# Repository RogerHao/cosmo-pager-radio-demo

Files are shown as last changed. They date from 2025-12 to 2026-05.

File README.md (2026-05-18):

# CosmoRadio

可穿梭于平行宇宙的 Radio 接收器

## 项目简介

桌面交互设备，安卓平板 + 3D 打印外壳 + ESP32 USB HID 控制器。造型参考 iMac G3 斜面站立式设计，用户通过旋钮调频、NFC 刷卡切换内容，仿佛在平行宇宙间搜索信号。

**当前版本：V4**（2026.04 — 2026.05）— 技术方案验证 + 单套原型制作

> 2026-04-29 与 Arthur 达成重启协议：第四期缩小为技术方案验证和单套原型制作，合同价 ¥5,000，目标 2026-05-20 左右交付。原 4 套整机 + 8 套电子套件交付范围已取消。

## 产品形态

- **外观风格**: iMac G3 斜面站立式，模块化三件式（主体 + 顶部 + 背板）
- **显示设计**: 三圆形遮罩（矩形屏幕通过开孔分割为三个圆形显示区）
- **输入方式**: 2 × EC11 旋钮 + Kailh 机械轴按钮 (6.25U 卫星轴) + NFC 刷卡
- **状态指示**: WS2812 RGB LED

## 硬件组成（V4）

| 组件 | 规格 | 用途 |
|---|---|---|
| 安卓平板 | 客户自购 (Samsung Galaxy Tab A9 8.7") | 主机，运行 Web 应用 |
| ESP32-S3 DevKitC N16R8 | 36+ GPIO / USB OTG / 16MB Flash / 8MB PSRAM | HID 控制器 |
| 定制 PCB 载板 | **100×100mm 双面** (JLCPCB 免费打样)，**两条 1×22 单排母** + 5 路 XH2.54 + 4× 10kΩ/10nF 去抖 | 消灭飞线，XH2.54 即插即用 |
| EC11 旋钮 × 2 | 15mm 半轴柄旋转编码器 | 频率调节 / 模式切换 |
| Kailh BOX 轴 + 6.25U 卫星轴 | 机械键盘蝴蝶结构，3.6mm 行程 | Action Button |
| RC522 mini NFC 模块 × 1 | 13.56MHz SPI，读 NTAG215 NDEF | NFC 刷卡交互（最终 1 个，2026-05-06 确认） |
| **OTG dongle (YK16-09E V1) 内置子板** | 拆 USB-A 母座，4 飞线接 J5 → DevKitC 排针 GPIO19/20 + 5V/GND | 平板 Data Host + Power Sink 同时工作 |
| 板载 RGB LED | DevKitC GPIO48 WS2812B | 状态指示（不外接 LED）|

## 连接方案

| 方案 | 固件位置 | 状态 |
|---|---|---|
| USB HID | 项目根目录 | **当前使用** — TinyUSB，即插即用 |
| BLE HID | (已删除，见 git 历史) | V1-V2 遗留，已停用 |

## 交互设计

输入设备通过 ESP32 USB HID 协议作为标准键盘连接到安卓平板，事件以模拟按键传递：

| 输入 | 映射 | 功能 |
|---|---|---|
| 顶部 Action 按钮 | Enter 键 | 确认选择 |
| EC11 左 旋转 | 上/下方向键 | 调节频率 |
| EC11 左 按下 | F1（占位，平板可重映射） | 扩展功能位 |
| EC11 右 旋转 | 左/右方向键 | 切换模式 |
| EC11 右 按下 | F2（占位，平板可重映射） | 扩展功能位 |
| NFC 卡（写了 NDEF Text） | `<payload>\n` | **主路径**：固件读卡上写入的字符串，原样键入 + Enter（无前缀） |
| NFC 卡（空白 / 非 NDEF） | `NFC:<UID>\n` | 兜底：识别失败时键入 UID 方便诊断 |

### NFC 协议设计

为了让产品身份与 NFC 卡 UID 解耦（UID 不可控且需要逐张录入），固件读取卡上的 NDEF Text Record 内容作为产品 ID。流程：

1. 出厂前用任一手机 NFC 工具 app 把每张卡写入特定字符串（如 `R01`、`track-42`）
2. 用户放卡 → 固件读 NDEF → HID 键入 `R01\n`
3. 平板侧 Android 应用结合页面状态/输入长度判断当前是 NFC payload 还是普通 HID 键入；`NFC:` 前缀仅出现在 UID 兜底路径，方便区分

### LED 状态指示（DevKitC 板载 GPIO48 RGB LED）

| 事件 | LED 颜色 |
|---|---|
| 按钮按下 | 红色 |
| 按钮释放 | 熄灭 |
| NFC 识别中（键入期间） | 蓝色 |
| 启动完成 | 绿色闪烁 |

## 项目结构

```
cosmo-radio/                            # 项目根 = ESP-IDF USB HID 固件
├── main/
│   ├── tusb_hid_example_main.c         # 入口：USB HID + ASCII→HID 编码
│   ├── input_handler.c/h               # GPIO 中断输入（按钮 + 双 EC11）
│   ├── nfc_handler.c/h                 # RC522 SPI 扫描 + NDEF Text 解析
│   └── led_indicator.c/h               # 板载 WS2812 RGB（GPIO48）
├── sdkconfig.defaults
├── CMakeLists.txt
├── pcb/                                # KiCad 工程 + JLCPCB 上板资料（待开始）
├── docs/
│   ├── assets/                         # 元器件引脚图、原型照片
│   ├── firmware/                       # 固件实现文档
│   ├── hardware/                       # 硬件模块设计方案（NFC、USB...）
│   ├── legacy/                         # 弃用内容
│   └── project/ → codex                # BOM、PCB Spec、项目主文档
└── test/
    └── hid-test.html
```

## 相关项目

- [cosmo-pager-web-nextjs-vercel](https://github.com/RogerHao/cosmo-pager-web-nextjs-vercel) — Web 应用前端（客户软件团队开发）

## 版本历史

| 版本 | 时间 | 主控 | 连接 | 主要变化 |
|---|---|---|---|---|
| V1 | 2025 Q3-Q4 | Adafruit HUZZAH32 | — | 硬件预研 |
| V2 | 2025.12-2026.01 | XIAO ESP32S3 | BLE HID | 首批组装，硅谷交付 |
| V3 | 2026.01-2026.02 | ESP32-S3 SuperMini | USB HID | BLE→USB 切换，12 套交付 |
| **V4** | **2026.04-2026.05** | **ESP32-S3 DevKitC N16R8** | **USB HID** | **模块化 PCB + NFC + 机械按钮，单套原型验证** |

## V4 进度

**2026-05-07 整体技术方案验证完成 ✅**——电气、固件、NFC 协议端到端跑通。后续是 PCB 板设计 + 结构件设计。

电气与固件：
- [x] 原 12 套 BOM 定稿 + 报价（单套 ¥79，已取消）
- [x] 2026-04-29 与 Arthur 重启 V4：技术方案验证 + 单套原型，合同价 ¥5,000
- [x] USB-C 充电方案：被动 SS34 注入实测失败 → 改为内置一分二 OTG 线材小板（已采购验证）
- [x] NFC 数量确认：1 个 RC522 mini（2026-05-06）
- [x] 万能板飞线原型焊接 + GPIO 验证（2026-05-06，[图片](docs/assets/v4-handmade-prototype-2026-05-06.jpg)）
- [x] 固件 V4 GPIO 迁移（SuperMini → DevKitC N16R8）
- [x] NFC 驱动开发（RC522 SPI + NDEF Text Record 解析）
- [x] 旋钮 + NFC HID 协议定稿（`#<payload>\n` + UID 兜底）
- [x] 端到端验证：iPhone 写卡 → ESP32 读 NDEF → HID 键入 `#112358\n`（2026-05-07）

待办（V4 收尾）：
- [ ] PCB 载板设计（KiCad → JLCPCB），把万能板飞线版固化为正式板
- [ ] Arthur 寄新 Tab A9（原 Pad 已损坏）→ HID + 充电链路回归
- [ ] 按钮机构验证（6.25U 卫星轴空格键 + 3D 打印键帽）
- [ ] 外壳 3D 模型适配（Arthur Fusion 360）+ 打印装配
- [ ] 单套整机原型组装 + 整机测试
- [ ] 交付技术验证报告 + 单套原型

## 构建与烧录

```bash
get_idf                                    # 激活 ESP-IDF 环境
idf.py set-target esp32s3                  # 设置目标芯片（首次）
idf.py build                               # 构建
idf.py -p /dev/cu.usbmodem* flash monitor  # 烧录并监控
```

## GPIO 引脚分配（V4 终版）

> N16R8 = 8MB octal PSRAM，**GPIO 26-37 全段被内部 octal SPI flash + PSRAM 占用，不可使用**。完整表和"PCB 位置"列见 [CLAUDE.md](CLAUDE.md) "GPIO Pin Assignments"。

| 功能 | GPIO | 连接器 (PCB 位置) |
|---|---|---|
| EC11-L (用户左旋钮) A/B/SW | **42 / 41 / 40** | J1 (PCB 左侧中段, 5P) |
| EC11-R (用户右旋钮) A/B/SW | **17 / 18 / 8** | J2 (PCB 右侧中段, 5P) |
| Action Button | 1 | J3 (PCB 左侧靠前, 2P) |
| RC522 NFC RST/IRQ/MISO/MOSI/SCK/CS | 4 / 5 / 6 / 7 / 15 / 16 | J4 (PCB 右侧, 8P, SPI2 via GPIO Matrix) |
| OTG USB D-/D+ | 19 / 20 | J5 (PCB 左侧靠后, 4P) → dongle USB |
| 板载 RGB LED | 48 | DevKitC 板载，无外接 LED |

> EC11 A/B 信号 PCB 上各加 10kΩ 上拉 + 10nF 对地 RC 去抖。
> V3 引脚分配（SuperMini）见 git 历史。

## 文档索引

- [V4 待办事项](TODO.md)
- [V4 BOM 及报价分析](docs/project/CosmoRadio-V4-BOM及报价分析.md)
- [V4 PCB 载板规格](docs/project/CosmoRadio-V4-PCB-Spec.md)
- [项目主文档](docs/project/cosmoradio-yangweile-customized-hardware.md)
- [USB 接口方案](docs/hardware/usb.md)
- [NFC 模块方案](docs/hardware/nfc.md)
- [OTG 一分二适配器（内置子板）](docs/hardware/otg-adapter.md)

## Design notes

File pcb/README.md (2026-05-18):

# CosmoRadio V4 PCB

CosmoRadio V4 的 PCB 目标是做一块 ESP32-S3 DevKitC N16R8 载板，用于技术方案验证和单套原型制作。

当前阶段不追求量产最优，而是追求：

- 可快速打样
- 可手工装配
- 可稳定验证 USB HID、外部充电、旋钮、按钮、NFC
- 出问题时容易测量和返修

## 当前范围

| 项目 | 结论 |
|---|---|
| 合作状态 | 2026-04-29 与 Arthur 重启 V4 |
| 当前交付 | 技术方案验证 + 单套原型制作 |
| 合同价 | ¥5,000 |
| 目标时间 | 2026-05-20 左右 |
| 核心风险 | PCB 设计与验证 |
| 非当前目标 | 原 4 套整机 + 8 套电子件批量交付 |

## 2026-05-07 整体方案验证完成 ✅

| 项目 | 状态 |
|---|---|
| NFC 数量 | ✅ 确认 **1 个** RC522 mini |
| 一分二 OTG + 充电线材 | ✅ 已采购多种型号，测试出一种比较理想，作为内置子板基准 |
| 手工万能板原型 | ✅ 已焊出（[图片](../docs/assets/v4-handmade-prototype-2026-05-06.jpg)）：ESP32-S3 DevKitC + 拆解后的一分二小板 + 4 路 XH2.54 连接器 |
| 测试机 | ⚠️ 原 R4 Tab A9 已损坏，临时用安卓手机替代验证；新 Tab A9 到货后需回归 |
| 连接器布局 | 左上 J4 NFC 8P / 右上 J3 Action Button 2P / 左中 J1 EC11 左 5P / 右中 J2 EC11 右 5P |
| GPIO 分配 | ✅ V4 终版定稿（2026-05-06），详见 [CLAUDE.md](../CLAUDE.md) |
| 外接 LED | ❌ 不接（用 DevKitC 板载 GPIO48 RGB LED 做调试） |
| EC11 接线 | 3 IO + 共地（C 与 SW2 都接 GND，无需 VCC，靠 ESP32 内部上拉） |
| 固件 V4 GPIO 迁移 | ✅ 完成（2026-05-06）；V3 SuperMini pinout 完全弃用 |
| RC522 NFC 驱动 | ✅ 1MHz SPI，NDEF Text Record 解析跑通（2026-05-07） |
| HID 协议 | ✅ `#<payload>\n` 主路径 + `NFC:<UID>\n` 兜底（2026-05-07） |
| 端到端验证 | ✅ iPhone 写卡 "112358" → ESP32 读 NDEF → HID 键入 `#112358\n`（2026-05-07） |

**剩余工作集中在 PCB 设计 + 结构件**——所有方案级未知都已收敛。

## 下一阶段：PCB 落版（Plan v2，2026-05-18 锁定）

详细方案见 `~/.claude/plans/iridescent-snuggling-planet.md`。要点：

- 把万能板飞线版 1:1 复制到 KiCad（连接器位置、网络名都已经在飞线上验证过）
- ESP32-S3 DevKitC N16R8 用**两条 1×22 单排母**（不是 2×22 双排，单排好焊好对齐），间距 22.86mm
- **5 路 XH2.54 连接器**（J1 EC11-L / J2 EC11-R / J3 BTN / J4 NFC / J5 OTG USB 数据）
- OTG dongle (YK16-09E V1) 拆 USB-A 母座后 4 飞线焊到 J5 公头线
- **EC11 A/B 信号外加 10kΩ + 10nF RC 去抖**（4 R + 4 C，全 0805 贴片）—— 解决飞线版"一格不准"
- NFC SPI 时钟可尝试拉回 5MHz（铜箔走线 + 模块自带去耦应该够）
- 板尺寸 **100×100mm 双面板**（JLC 免费打样上限），无 USB-C 母座、无 SS34、无外接 LED

## 板子定位

这不是完整 ESP32 主控板，而是 **ESP32-S3 DevKitC N16R8 carrier board**。

ESP32-S3 DevKitC 通过 2.54mm 排母插在 PCB 上，PCB 只负责：

- 固定主控与外设线束
- 消灭 V3 的万能板和飞线
- 将旋钮、按钮、LED、NFC、USB-C 接口标准化
- 提供必要的上拉、电阻、二极管、去耦
- 支持单套原型的调试和返修

```mermaid
flowchart LR
    tablet[Android 平板] <-- USB HID --> pcb[CosmoRadio V4 PCB]
    charger[USB-C 充电器] --> pcb
    pcb --> devkit[ESP32-S3 DevKitC N16R8]
    pcb --> enc1[EC11 左旋钮]
    pcb --> enc2[EC11 右旋钮]
    pcb --> top[顶部按钮 / LED]
    pcb --> nfc[RC522 NFC 模块]
```

## 已确认事实

### 主控

- 使用 ESP32-S3 DevKitC N16R8，不再使用 V3 的 ESP32-S3 SuperMini。
- DevKitC 插在载板上，不直接焊死。
- ESP32-S3 原生 USB OTG 固定使用 GPIO19 / GPIO20。
- 当前固件仍是 V3/SuperMini pinout，后续必须迁移到 V4 pinout。

### 输入与输出

- 两个 EC11 旋钮，每个旋钮有 A / B / SW。
- Action Button 使用 Kailh BOX 轴 + 6.25U 卫星轴，本质是单路低电平按钮。
- LED 使用 WS2812B，数据线串 330R。
- NFC 使用 RC522 mini 模块，通过 SPI 连接，不把 MFRC522 芯片集成到主板。

### USB 与供电

- 平板是 Samsung Galaxy Tab A9 8.7"。
- 平板侧需要同时承担 USB Host 和充电需求。
- HID 必须走有线 USB；BLE HID 之前已经测试过，不稳定，排除出当前主路径。
- V3 已经通过 Type-C 一分二 OTG 线材验证：Tab A9/Android 手机可以同时接收 ESP32 USB HID 输入并充电。
- 当前问题不是“原理是否成立”，而是 V3 的一分二线材太长、外露、形态差。
- V4 目标是尽可能把一分二线材里的 OTG + 充电能力集成到 PCB/内部结构中，减少外露线材。
- 市面上容易买到的是 OTG + 充电转接线/小扩展坞，不是适合直接嵌入主 PCB 的裸模块。

```mermaid
flowchart LR
    tablet[Tab A9] <-- USB Host 数据 --> sub[内置一分二 OTG + 充电子系统]
    charger[USB-C 充电器] --> sub
    sub <-- USB HID --> esp[ESP32-S3 DevKitC]
    esp --> io[旋钮 / 按钮 / LED / NFC]
```

当前 USB/充电路径按三档处理：

| 档位 | 方案 | 当前定位 |
|---|---|---|
| P0 | 外购一分二 OTG + 充电线材整件 | V3 已验证成立；继续作为功能基准 |
| P1 | 拆解一分二线材，取内部 PCB，短线/板内固定 | 当前最现实的 V4 原型方向 |
| P2 | 自研 LDR6028/LDR6023C OTG + 充电子板 | 可集成，但先作为后续方案，不塞进第一版主板风险内 |

被动 VBUS 注入方案已经降级为失败路径记录，不再作为主线：

- J6 充电输入 USB-C
- J5 平板输出 USB-C
- J6 VBUS 通过 SS34 注入 J5 VBUS
- J5 / J6 CC1 和 CC2 视转接板实测情况配置 5.1k Rd

原因：6P Type-C 转接板即使有 5.1k Rd，也只能让手机/平板识别到 OTG 设备；它不能让平板同时完成 Data Host 和 Power Sink 的角色组合。实测中，两个 6P 转接板直连、或通过 SS34 注入外部 5V，都无法让手机/平板进入充电状态。

不能把 CH224K、HUSB238 这类 PD Sink/诱骗芯片当成完整解法。它们主要解决“从充电器取电压”，不负责让平板同时保持数据 Host 和供电 Sink，也不负责完整 USB 数据/供电角色编排。

### USB/充电可选方案重审

问题本质：Tab A9 必须同时处于 **Data Host** 和 **Power Sink**。这不是普通 USB-C 默认角色，默认情况下 Host 往往也是供电 Source。要让平板一边 Host ESP32，一边被外部充电，需要角色拆分。

| 方案 | 是否能集成到主 PCB | 风险 | 结论 |
|---|---|---|---|
| 拆解已验证一分二线材并内置小板 | 半集成 | 低中 | 第一版最现实，解决形态问题优先 |
| LDR6028 5V OTG + 充电子板 | 能 | 中 | 元件少，可后续小板验证；不一定比成品便宜 |
| LDR6023C 双口 charge-through 子板 | 能 | 中高 | 更接近成品线材内部方案，但外围更复杂 |
| 标准 USB-C PD charge-through | 能 | 高 | 正规方案，但不适合当前预算和周期 |
| 被动/半主动 SS34 注入 | 能 | 已实测失败 | 不再作为主线 |
| BLE HID + USB-C 只负责充电 | 能 | 低 | 已排除：BLE HID 实测不稳定，且当前要求必须有线 HID |

当前主路径：

1. 用已验证一分二线材作为功能基准。
2. 买 2-3 条同类线材拆解，优先寻找尺寸小、焊点清晰、可固定的内部 PCB。
3. 第一版 V4 主 PCB 给内置子板预留安装区、短线焊盘、测试点和应力释放。
4. 只有当成品线材内部 PCB 不适合内置，才启动 LDR6028/LDR6023C 自研小板。

标准 PD charge-through 架构如下：

```mermaid
flowchart LR
    charger[USB-C 充电器] --> sink[充电器侧 PD Sink 控制器]
    sink --> path[5V 电源路径 / eFuse / DC-DC]
    path --> tabletpd[平板侧 PD 控制器]
    tabletpd --> tablet[Tab A9: Power Sink + Data Host]
    tablet <-- USB2 D+/D- --> esp[ESP32-S3 USB HID Device]
```

这种方案需要：

- 平板侧 Type-C/PD 控制器：处理 Power Role Swap / Data Role Swap，使 Tab A9 保持 Host，同时从本设备受电。
- 充电器侧 PD Sink 控制器：从外部充电器取电。
- 电源路径保护：eFuse、限流、反灌保护、ESD、VBUS 放电。
- USB2 D+ / D- 路由：只有 ESP32 一个 USB 设备时不一定需要 USB Hub；若未来还有多个 USB 设备，才需要 Hub。
- PD 控制器配置或固件：这是主要工程风险。

已验证的一分二线材架构如下：

```mermaid
flowchart LR
    tablet[Tab A9 / Android 手机] <-- USB2 HID --> cable[一分二 OTG + 充电线材内部 PCB]
    charger[USB-C 充电器] --> cable
    cable <-- USB2 --> esp[ESP32-S3 HID]
```

它证明 Tab A9/Android 手机支持“Data Host + Power Sink”这个工作状态。失败的是我们用 6P 转接板和 SS34 复刻这个能力的被动电路，不是设备能力。

LDR6028 自研小板判断：

| 项目 | 判断 |
|---|---|
| 功能定位 | 5V OTG + 充电角色控制小板 |
| 预计新增元件 | 不含连接器约 16-22 个；含连接器约 18-24 个 |
| 单板元件成本 | 约 ¥15-20，不含 PCB、SMT、运费、返工 |
| 优点 | 形态可控，可最终集成 |
| 缺点 | 不比 20 元级成品线材便宜，且有兼容性调试风险 |

结论：LDR6028 的价值不是降成本，而是解决线材形态和长期可控性。对单套 V4 原型，优先拆解成品线材更理性。

已排除方案：BLE HID + USB-C 只负责充电：

```mermaid
flowchart LR
    charger[USB-C 充电器] --> pcb[主 PCB 电源输入]
    pcb --> tablet[短线给 Tab A9 充电]
    esp[ESP32-S3] <-- BLE HID --> tablet
    esp --> io[旋钮 / 按钮 / LED / NFC]
```

这个方案硬件上最容易集成到主 PCB：USB-C 只做供电，输入端可以用 PD Sink/诱骗芯片，输出端按 Type-C Source 给平板 5V。数据改为 BLE HID。但它违反当前硬约束，且 BLE HID 已实测不稳定，因此不作为 V4 路线。

### 有线 HID 下的当前建议

先做 **一分二线材拆解内置方案**，不要直接把 LDR6028/LDR6023C 或标准 PD charge-through 塞进第一版主 PCB。

2026-04-30 Manus 调研结论见 [Tab_A9_OTG_Charging_Feasibility_Report.md](research/Tab_A9_OTG_Charging_Feasibility_Report.md)。该报告针对“Tab A9 专用半主动方案”给出偏负面判断；后续实测一分二线材证明设备支持 HID + 充电，但也证明 6P 转接板 + SS34 这类被动复刻不够。

当前根据实测修正：

- 一分二 OTG + 充电线材已经证明 Tab A9/Android 手机可以同时 HID 输入和充电。
- 6P 转接板 + SS34 的失败说明不能靠简单 VBUS 注入和 CC 下拉复刻该线材。
- 第一版目标应先消灭外部长线，而不是立刻自研 USB-C 协议子系统。
- 标准 PD charge-through 仍是正规方向，但需要 PD 控制器配置、PD 协议调试、电源路径保护和可能的协议分析仪。
- V4 当前是技术验证 + 单套原型，合同价 ¥5,000，不能把主要预算压在 USB-C PD 协议栈调试上。

一分二线材拆解内置方案必须验证：

| 验证项 | 通过标准 |
|---|---|
| HID 枚举 | Tab A9 能识别 ESP32-S3 TinyUSB HID |
| 充电接入 | 插入外部充电器后 HID 不断连，系统显示充电 |
| 电池状态 | Android 显示充电，且电量能净增加 |
| 结构集成 | 拆解后的内部 PCB 能固定在外壳内，线长可缩短 |
| 热稳定 | 连续运行 2 小时无明显温升 |
| 恢复能力 | 平板重启、熄屏、亮屏、重插后能恢复 |

被动 SS34 注入实验记录如下，仅保留为排错依据。

最小验证拓扑只需要 1 颗 SS34：

```mermaid
flowchart LR
    chg[外部 5V] --> d1[SS34]
    d1 --> tabv[Tab A9 VBUS / SYS_5V]
    tabv --> esp[ESP32 5V]
    tab[Tab A9 D+/D-] <-- USB2 --> esp
```

这个拓扑里 `Tab_A9_VBUS` 和 `SYS_5V` 是同一个节点。不插外部电源时，平板作为 USB Host 给 ESP32 供电；插外部电源时，外部 5V 通过 SS34 尝试注入同一节点。SS34 的作用是防止平板 VBUS 反灌到外部充电器输入。

实测结果：6P 转接板能实现 USB HID，但不能实现充电。即使不接 ESP32，只把手机/平板和充电器通过两个 6P 转接板四线直连，也无法充电。原因是该电路没有完成 Type-C/PD 角色协商，平板不会因为 VBUS 被外部注入就切换到可充电状态。

更完整的诊断拓扑曾考虑 `SYS_5V` 电源 OR-ing，需要 3 颗 SS34：

```mermaid
flowchart LR
    tabv[Tab A9 VBUS] --> dt[隔离二极管 / 理想二极管]
    chg[外部 5V] --> dc[隔离二极管 / 理想二极管]
    dt --> sys[SYS_5V]
    dc --> sys
    sys --> esp[ESP32 5V]
    chg --> inj[肖特基 / 限流 / eFuse]
    inj --> tabv
    tab[Tab A9 D+/D-] <-- USB2 --> esp
```

原因：不插外部电源时，平板作为 USB Host 必须能从 `Tab_A9_VBUS` 给 ESP32 供电。若 ESP32 只接外部 `VBUS_IN`，则无法验证正常 OTG 使用场景。外部电源接入后，`VBUS_IN` 同时给 ESP32 供电，并通过隔离/限流路径尝试注入 `Tab_A9_VBUS` 给平板充电。

SS34 接线方向：电流从无色端流向有色条纹端，条纹端是阴极。`外部 5V -> Tab_A9_VBUS` 时，条纹端朝 `Tab_A9_VBUS`。

## 关键设计判断

### 采用混合焊接方案

第一版不做全直插件，也不做全贴片。

| 类型 | 方案 | 理由 |
|---|---|---|
| 电阻 | 0805 SMD | 适合加热台，易夹取，易返修 |
| 电容 | 0805 SMD | 适合加热台，布线短 |
| SS34 | SMA / DO-214AC SMD | 电流能力够，焊盘大，可返修 |
| JST-XH 连接器 | 直插件 | 插拔受力大，原型更可靠 |
| DevKitC 排母 | 直插件 | 承重和插拔受力，不适合贴片 |
| USB-C | DIP 转接板 / 2.54mm 排孔 | 第一版避免裸 USB-C SMT 焊接风险 |

判断：**低风险小器件贴片，高机械应力器件直插件**。这比全直插件更整洁，也比全贴片更适合单套原型。

### 不把 USB-C 母座直接做成 SMT 主件

裸 USB-C SMT 母座对第一版不划算：

- 焊盘密，短路排查成本高
- 插拔受力大，需要外壳和板边机械支撑
- 3D 模型和 footprint 容易踩坑
- D+ / D- / CC 任何问题都会让 USB 调试变复杂

第一版主板使用已有 6P USB-C DIP 转接板更稳。OTG + 充电子系统如果采用拆板方案，则作为独立子板固定，不把未知小板强行复刻进主 PCB。

### 先解决线材形态，不先挑战 USB-C 协议

当前真正问题不是“有没有转接器”，而是“转接器线太长、外露、丑”。因此第一轮验证目标应改成：

1. 买 2-3 个便宜 OTG + 充电转接器。
2. 逐个做 Tab A9 + ESP32-S3 HID + 充电稳定性复测。
3. 拆开最稳定、体积最小的一款，记录内部 PCB 尺寸、接口、焊点、芯片丝印。
4. 将其作为内置子板固定在外壳内，用短线或板内焊点连接主板。
5. 主 PCB 只为它预留 USB HID 接口、5V/GND 测试点、安装空间和应力释放结构。

这个路线比从零设计 USB-C PD/OTG 子板更快，也比把完整转接线塞进外壳更干净。

### NFC 连接器按 8P 处理

文档里曾出现 7P / 8P 不一致。以 RC522 mini 实物和 NFC 文档为准，采用 8P：

| Pin | RC522 丝印 | 信号 |
|-----|---|---|
| 1 | SDA | CS |
| 2 | SCK | SCK |
| 3 | MOSI | MOSI |
| 4 | MISO | MISO |
| 5 | IRQ | IRQ |
| 6 | GND | GND |
| 7 | RET | RST |
| 8 | 3V3 | 3V3 |

IRQ 可选，但第一版建议接出，避免后续想做中断驱动时改板。

### 顶部按钮和 LED 暂时分开连接

PCB Spec 曾建议将按钮和 LED 合并为 4P 顶部模块连接器。BOM 里按钮和 LED 是分开的 2P + 3P。

第一版建议分开：

- BTN：2P XH2.54
- LED：3P XH2.54

理由：

- 原型更容易测试
- 按钮和 LED 可独立替换
- 顶部模块结构未最终定型，分开线束更灵活

## 接口定义（Plan v2，最终版）

权威 GPIO 表见 [CLAUDE.md](../CLAUDE.md) "GPIO Pin Assignments"。下表为 PCB 视角连接器列表：

| Ref | 接口 | 类型 | 连接对象 | 信号（按 pin 顺序）|
|-----|---|---|---|---|
| U1A | DevKitC 左列 socket | 1×22P 排母 2.54mm | ESP32-S3 DevKitC N16R8 左侧排针 | 22 pin，含 19/20/21/35-44/1/2/5V/GND |
| U1B | DevKitC 右列 socket | 1×22P 排母 2.54mm | ESP32-S3 DevKitC N16R8 右侧排针 | 22 pin，含 3V3/RST/4-18/3/46/9-14 |
| J1 | EC11-L (用户左旋钮) | XH2.54 5P | 左旋钮 | A=42, B=41, SW=40, GND, GND |
| J2 | EC11-R (用户右旋钮) | XH2.54 5P | 右旋钮 | A=17, B=18, SW=8, GND, GND |
| J3 | BTN | XH2.54 2P | Kailh BOX 按钮 | SIG=1, GND |
| J4 | NFC | XH2.54 8P | RC522 mini | CS=16, SCK=15, MOSI=7, MISO=6, IRQ=5, GND, RST=4, 3V3 |
| J5 | OTG USB 数据 | XH2.54 4P | OTG dongle (YK16-09E V1) 拆 USB-A 后 4 飞线 | VBUS, D-=19, D+=20, GND |

> **U1A 中心距 U1B = 22.86mm** (= 9 × 2.54mm pitch)，breadboard 兼容。以飞线万能板实测为准。

## 原理图元件清单（Plan v2，14 元件）

| Ref | 元件 | 封装 | 说明 |
|-----|---|---|---|
| U1A, U1B | 1×22P 排母座 (×2) | 2.54mm THT | DevKitC 插入用 |
| J1, J2 | XH2.54 5P 立式直针座 (×2) | THT | EC11 旋钮 |
| J3 | XH2.54 2P 立式直针座 | THT | Action Button |
| J4 | XH2.54 8P 立式直针座 | THT | RC522 NFC |
| J5 | XH2.54 4P 立式直针座 | THT | OTG dongle USB 数据 |
| R1, R2 | 10kΩ 上拉 (EC11-L A/B) | 0805 | LCSC C17414 |
| R3, R4 | 10kΩ 上拉 (EC11-R A/B) | 0805 | LCSC C17414 |
| C1, C2 | 10nF 对 GND (EC11-L A/B) | 0805 X7R 50V | RC 去抖，τ=100µs |
| C3, C4 | 10nF 对 GND (EC11-R A/B) | 0805 X7R 50V | 同上 |
| H1-H4 | M2.5 安装孔 | 通孔 | 四角 |

**取消的元件**（vs 旧 spec）：USB-C 母座 J5/J6、USB-C CC 5.1k Rd × 4、SS34 防倒灌、WS2812B LED 连接器 J4 (旧)、330Ω LED 限流。所有 USB 充电由 OTG dongle 内部承担，LED 用 DevKitC GPIO48 板载 RGB。

## PCB 物理约束

| 项目 | 目标 |
|---|---|
| 尺寸 | **100mm × 100mm**（JLC 免费打样上限）|
| 层数 | 2 层 |
| 板厚 | 1.6mm |
| 铜厚 | 1oz |
| 表面 | HASL 无铅 |
| 阻焊 | 黑色 |
| 丝印 | 白色 |
| 安装孔 | 4 × M2.5（四角，孔径 2.7mm）|
| 制造 | JLCPCB 5 片打样 |
| SMT 装配 | 不上 SMT；纯打板，8 个 0805 + 6 个连接器手焊 ~15min |

## 布局原则（Plan v2）

- DevKitC 居中，USB-C OTG 端朝外壳后侧（用户视角顶部）
- 连接器位置就近其需要的 GPIO（最短走线）：
  - **PCB 左侧**：J5 USB (靠后, GPIO 19/20) / J1 EC11-L (中段, GPIO 42/41/40) / J3 BTN (靠前, GPIO 1)
  - **PCB 右侧**：J4 NFC (中段, GPIO 4-7/15-16) / J2 EC11-R (中段偏上, GPIO 17/18/8)
- R/C 去抖网络紧贴 J1/J2 的 A/B pin（电容回 GND 路径最短）
- VBUS 走线宽度 ≥ 0.6mm（dongle 充电电流过路）
- USB D+/D- 短、并行、少过孔（<10cm 距离，无需阻抗控制）
- 每个连接器旁边丝印接口名 + pin 功能（≥1.0mm 高，gotcha #6）
- 顶丝印加 **"OTG USB-C: DO NOT PLUG"** 警示

## 已关闭的问题（Plan v2 收敛）

| 旧问题 | 决议 |
|---|---|
| DevKitC N16R8 实物 pinout 和排母间距 | 22.86mm，参 `pcb/asset/ESP32-S3-DevKitC-N16R8.png` |
| USB-C DIP 转接板尺寸 | 不用——OTG dongle 替代 |
| OTG + 充电转接器选型 + 拆解 | YK16-09E V1，已确定 |
| NFC 数量 | 1 个 RC522 mini，已锁 |
| 顶部模块线束 BTN+LED 合并？| 分开——BTN 2P (J3)，不外接 LED |
| 80×50 是否够 | 改 100×100 直接给到 JLC 免费打样上限 |
| 第二版扩展接口 | 不预留，U1A/U1B 自然暴露所有未用 GPIO |

## 下一步

1. ✅ ~~实测 DevKitC 排针尺寸~~ — 22.86mm 已确认
2. ✅ ~~拆 OTG dongle 选型~~ — YK16-09E V1 已用于飞线版
3. ⏳ KiCad 原理图（circuit-synth Phase 2）
4. ⏳ 生成 100×100mm PCB layout（Phase 4）
5. ⏳ Freerouting + DRC 0/0（Phase 5）
6. ⏳ 出 Gerber zip 上传 JLCPCB（Phase 7）

执行节奏见 `~/.claude/plans/iridescent-snuggling-planet.md`。

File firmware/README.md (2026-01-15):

# Cosmo Pager Radio - ESP32 BLE HID Firmware

基于 ESP-IDF 的 BLE HID 键盘固件，用于 Cosmo Pager Radio 项目。

## 硬件要求

| 组件 | 规格 | 连接 |
|---|---|---|
| XIAO ESP32S3 | Seeed Studio | 主控 |
| EC11 旋转编码器 x2 | 增量式编码器 | D1/D2, D3/D4 |
| 按钮 x1 | 常开按钮 | D0 |

## GPIO 引脚映射

| 功能 | GPIO | XIAO 引脚 | HID 按键 |
|---|---|---|---|
| 按钮 | 1 | D0 | Enter |
| 编码器1 CLK | 2 | D1 | Up |
| 编码器1 DT | 3 | D2 | Down |
| 编码器2 CLK | 4 | D3 | Right |
| 编码器2 DT | 5 | D4 | Left |

所有输入 GPIO 使用内部上拉电阻，低电平有效（接 GND 触发）。

## 电源接线

XIAO ESP32S3 背面有电池焊盘，支持 3.7V 锂电池直接供电：

- **B+**: 电池正极（远离 USB 口）
- **B-**: 电池负极（靠近 USB 口）

## 构建与烧录

```bash
# 激活 ESP-IDF 环境
get_idf

# 设置目标芯片（首次）
idf.py set-target esp32s3

# 构建
idf.py build

# 烧录并监控
idf.py -p /dev/cu.usbmodem* flash monitor
```

退出监控：`Ctrl+]`

## 配置说明

配置文件：
- `sdkconfig.defaults` - 通用配置
- `sdkconfig.defaults.esp32s3` - ESP32-S3 特定配置

关键配置项：
| 配置 | 值 | 说明 |
|---|-----|---|
| `CONFIG_BT_NIMBLE_ENABLED` | y | 使用 NimBLE 协议栈 |
| `CONFIG_EXAMPLE_KBD_ENABLE` | y | HID 键盘模式 |
| `CONFIG_ESPTOOLPY_FLASHSIZE_8MB` | y | 8MB Flash |

## 预期输出

```
I (367) HID_DEV_DEMO: setting hid gap, mode:2
I (457) HID_DEV_DEMO: GPIO input task started
I (457) HID_DEV_DEMO: GPIO input initialized: BTN=1, ENC1=2/3, ENC2=4/5
I (457) HID_DEV_BLE: START
```

按下按钮或转动旋钮时：
```
I (xxxxx) HID_DEV_DEMO: BTN -> ENTER
I (xxxxx) HID_DEV_DEMO: ENC1 CW -> UP
I (xxxxx) HID_DEV_DEMO: ENC2 CCW -> LEFT
```

## 蓝牙配对

设备名称：`cosmo-radio-input`

配对方式：Just Works（无需 PIN 码）

## 故障排除

1. **看不到 GPIO 日志**：确认 `mode:2`（键盘模式），如果是 `mode:1` 说明配置错误
2. **按钮无反应**：检查接线是否正确（按钮一端接 D0，另一端接 GND）
3. **无法烧录**：按住 BOOT 按钮再插入 USB 进入下载模式

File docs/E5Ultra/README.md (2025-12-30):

# E5 Ultra 设备参考

## 设备概述

E5 Ultra 是一款安卓游戏掌机，本项目将其改造为桌面式 Radio 接收器的主机部分。

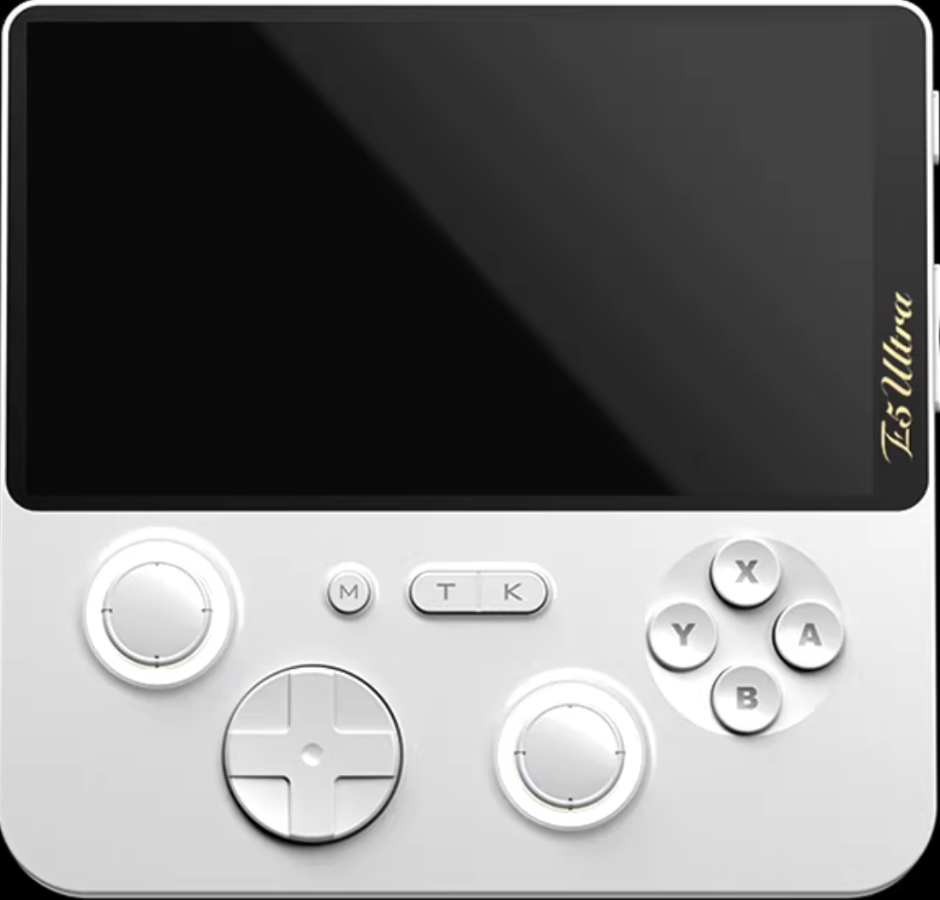
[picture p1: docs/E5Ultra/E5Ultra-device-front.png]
设备正面


## 规格参数

| 类别 | 规格 |
|---|---|
| **处理器** | T620 芯片，8核 A75+A55 CPU |
| **内存/存储** | 6GB RAM + 128GB 存储 |
| **屏幕** | 5寸 IPS 全贴屏 |
| **分辨率** | 1280 x 720 (16:9) |
| **刷新率** | 60Hz |
| **亮度** | 450nit，可调光 |
| **色域** | RGB 98% 覆盖 |
| **电池** | 5000mAh |
| **马达** | 线性马达 |
| **端口** | USB-C 4.0 x1 / 3.5mm 音频 x1 / TF 卡槽 x1 (micro SD 4.0) |
| **无线** | 5G WiFi / 2.4G WiFi / 蓝牙 |

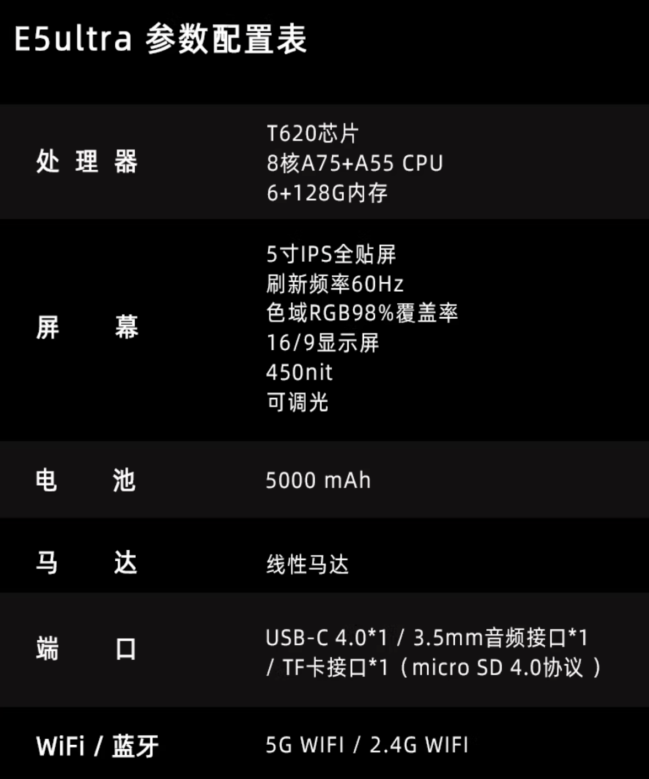
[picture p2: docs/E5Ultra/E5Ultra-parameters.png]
参数表


## 本项目使用方式

### 保留组件
- 屏幕模组（5寸 IPS）
- 主板及芯片组
- 电池（5000mAh）
- USB-C 接口
- WiFi/蓝牙模块

### 移除组件
- 后壳
- 下方物理按键区域
- 原有输入控制板

### 改造后状态

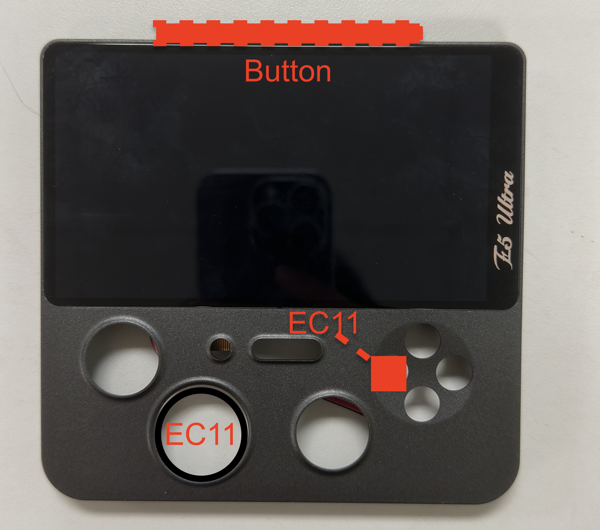
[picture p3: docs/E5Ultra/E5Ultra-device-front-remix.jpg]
改装标注图


改装后只保留前壳+屏幕+主板，下方原有按键区域的开孔将用于安装两个 EC11 旋钮。

## 供电取电点

从主板测试点取电，为外接 ESP32 控制器供电：
- 电压：3.5V ~ 3.7V（电池电压）
- 接入 ESP32 的 BAT 引脚

## 软件环境

- 操作系统：Android
- 浏览器：Fully Kiosk Browser（Kiosk 模式运行 Web 应用）
- 蓝牙：支持 HID 设备连接

## 外壳设计

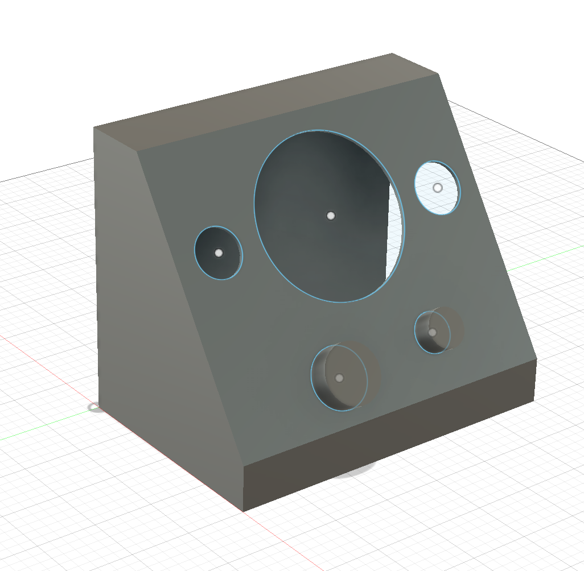
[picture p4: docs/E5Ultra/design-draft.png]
外壳设计稿


新外壳采用 3D 打印，E5 Ultra 的前壳将贴合在新外壳正面，通过三个圆形开孔展示屏幕内容。

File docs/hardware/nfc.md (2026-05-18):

# CosmoRadio V4 — NFC 模块方案

> 用户将带有 NFC/RFID 标签的实物放置在收音机上方，触发安卓平板上的对应行为。
> ESP32 作为 USB HID 键盘，通过"键入字符串"方式将 NFC 事件传递给平板。

> ✅ **NFC 数量已确认（2026-05-06）**：1 个 RC522 mini，最终方案，不再讨论。下文"双 NFC 方案备选"段保留作为备忘，不再实施。

---

## 1. 硬件方案

### 1.1 模块选型：RC522 Mini

| 参数 | 值 |
|---|---|
| IC | NXP MFRC522 |
| 工作频率 | 13.56 MHz (ISO/IEC 14443 Type A) |
| 通信接口 | SPI (Mode 0, max 10 Mbps) |
| 工作电压 | 2.5V — 3.3V |
| 工作电流 | 13 — 26 mA (激活), < 80 µA (休眠) |
| 模块尺寸 | 30 × 40 mm (mini 版) |
| 单价 | ¥9.94 |

支持标签类型：MIFARE Classic 1K/4K, MIFARE Ultralight, **NTAG213/215/216**。

### 1.2 推荐标签：NTAG215

| 规格 | NTAG213 | **NTAG215** | NTAG216 |
|---|---|---|---|
| UID 长度 | 7 bytes | 7 bytes | 7 bytes |
| 用户存储 | 144 bytes | 504 bytes | 888 bytes |
| 写入寿命 | 50,000 次 | 200,000 次 | 500,000 次 |
| 密码保护 | PWD_AUTH | PWD_AUTH | PWD_AUTH |

选 NTAG215 的理由：
- 504 bytes 用户存储，够写入自定义 payload（UID 之外的元数据）
- Amiibo 标准标签，量产最大、价格最低（¥0.3 — ¥1/片）
- 如果只用 UID 识别不写数据，NTAG213 也够用

### 1.3 接线 (PCB J4 连接器 — 8P JST-XH, **PCB 右侧**)

J4 在 PCB 上的物理位置：**用户右侧**（NFC 的 SPI 信号 GPIO 4/5/6/7/15/16 都在 DevKitC 的右列）。与 RC522 mini (MF522-MINI) 模块的 8-pin 排针**物理顺序一一对应**，8P 端子线直接压接即可，无需交叉或空线。

> 引脚顺序来源：zave 旗舰店商品详情图实拍丝印，从排针第 1 脚到第 8 脚。
>
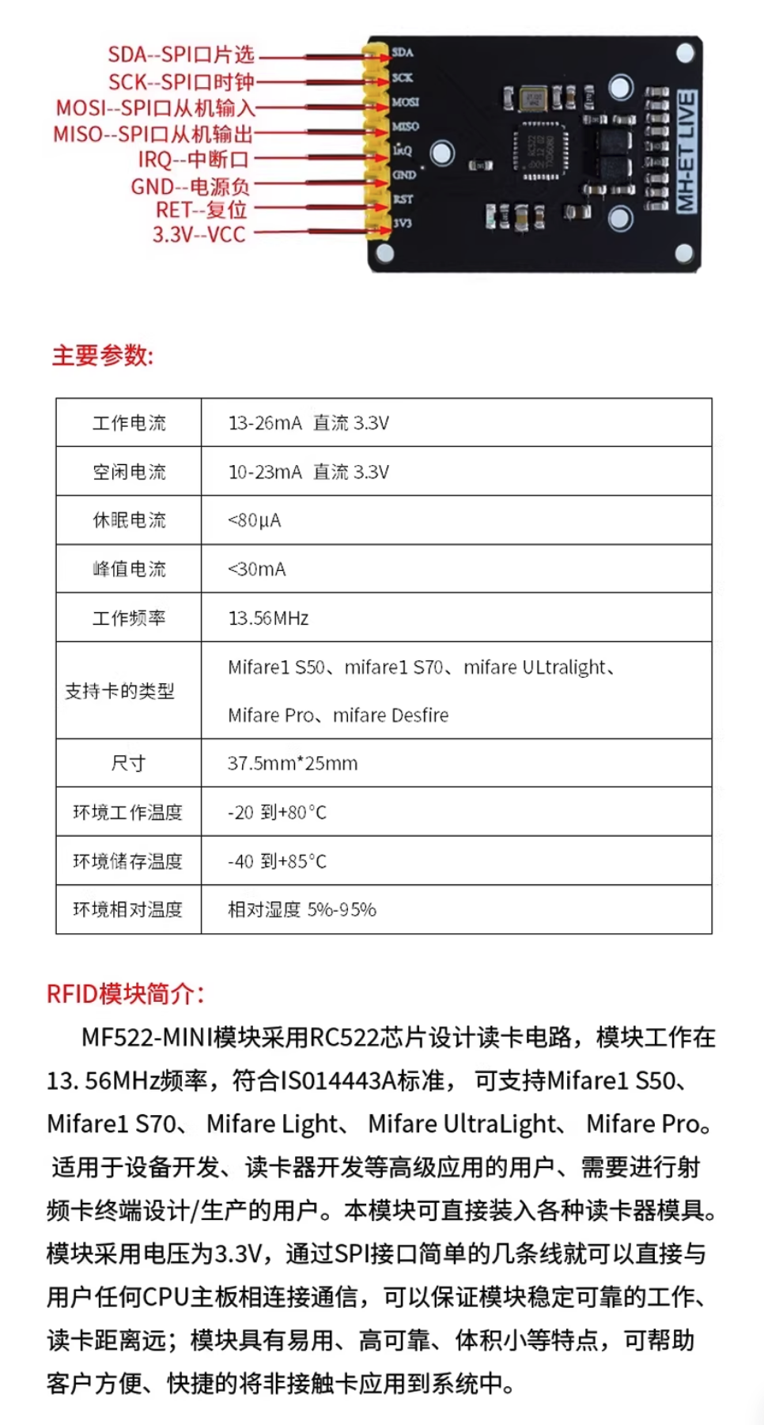
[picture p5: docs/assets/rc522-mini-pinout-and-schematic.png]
RC522 mini 引脚定义与原理图
> 

| Pin | 模块丝印 | 信号 | ESP32-S3 GPIO | SPI 总线 | 说明 |
|-----|---|---|---|---|---|
| 1 | SDA | CS (片选) | GPIO16 | SPI2 (软件 CS) | 软件控制，低有效 |
| 2 | SCK | SPI 时钟 | GPIO15 | SPI2 CLK | |
| 3 | MOSI | 主→从数据 | GPIO7 | SPI2 MOSI | |
| 4 | MISO | 从→主数据 | GPIO6 | SPI2 MISO | |
| 5 | IRQ | 中断请求 | GPIO5 | — | 低有效，固件未使用，仅接线预留 |
| 6 | GND | 地 | GND | — | |
| 7 | RST | 复位 | GPIO4 | — | 低有效 |
| 8 | 3V3 | VCC | 3V3 | — | 模块供电 |

使用 SPI2 (FSPI) 硬件 SPI 总线，信号走 GPIO Matrix。RC522 工作频率 ~8 MHz，远低于 GPIO Matrix 上限（80 MHz），信号完整性无压力。

> **GPIO 分配演进**：
> - 最初：GPIO 34-37（FSPI IO MUX 直连）→ ❌ 撞到 N16R8 内部 octal PSRAM
> - 中间：GPIO 4/5/6/7（SCK/MISO/MOSI/CS）+ 15/16（RST/IRQ）→ 信号端连续，但飞线时 8P 排线需在板上转圈
> - **当前（2026-05-06 实焊定稿）**：把整段顺序"翻过来"——RST→4 / IRQ→5 / MISO→6 / MOSI→7 / SCK→15 / CS→16，让 J4 连接器引脚和 DevKitC 排针走向一致，飞线无交叉
>
> **IRQ 引脚说明**：MFRC522 检测到标签进入射频场时拉低 IRQ。当前 `abobija/rc522` 库采用 SPI 轮询模式，不依赖 IRQ，但保留接线方便未来切换中断驱动模式以降低 CPU 占用。
>
> **注意**：模块丝印 RET 实际为 RST（复位），系厂商丝印错误。

### 1.4 安装位置

RC522 天线安装在**外壳顶部模块内侧**（朝上），用户将标签物品放置在收音机顶部。

> **双 NFC 方案备选**：若确认 2 个 NFC，一个放顶部模块左侧、一个放右侧。第二个 RC522 需要独立 CS 引脚（从 Reserved GPIO 11-18 分配），共享 FSPI 总线的 SCK/MOSI/MISO。RST 和 IRQ 也各需独立 GPIO。总计额外占用 3 个 GPIO（CS + RST + IRQ）。

关键约束：
- **PLA/PETG 对 13.56 MHz 磁场透明** — 2mm 壁厚几乎无衰减，读取距离不受影响
- **金属是大敌** — 天线区域附近不能有铜箔、螺丝、USB 屏蔽层。PCB 载板的地平面需要在天线投影区域开窗
- Mini 模块天线较小，有效读取距离约 15 — 30 mm（贴片标签）/ 30 — 50 mm（卡片标签）
- 标签穿过 2mm PLA 外壳后，实际工作距离 ≈ **13 — 28 mm**（贴片）

```
  ┌──────────────────────────────┐
  │     NFC 标签物品放置区域       │  ← 用户将物品放在这里
  ├──────────────────────────────┤
  │  ░░░░ 3D 打印顶部模块 ░░░░   │  ← 2mm PLA 壁
  │  ┌────────────────────────┐  │
  │  │   RC522 Mini 天线面朝上  │  │  ← 模块贴装在顶盖内侧
  │  └────────────────────────┘  │
  ├──────────────────────────────┤
  │       ESP32-S3 载板区域       │
  └──────────────────────────────┘
```

---

## 2. 通信协议设计

### 2.1 核心思路

ESP32 始终作为 USB HID 键盘。NFC 事件通过**键入结构化字符串**的方式传递给安卓平板，平板端应用解析该字符串并执行对应动作。

这种方案的优势：
- ESP32 固件不需要维护 UID → 动作的映射表
- 新增标签不需要刷固件，只需在安卓端配置
- 标准 HID 键盘协议，无需自定义驱动
- 调试方便 — 任何文本编辑器都能看到输出

### 2.2 NFC HID 报文格式（**2026-05-07 定稿**）

> **协议演进**：早期方案是单一的 `NFC:<UID>\n`，但 UID 不可控（厂家烧录、每张卡随机），意味着每张卡都需要"逐张录入服务端数据库"才能上线。**当前方案改为读取卡上 NDEF Text Record 内容作为产品 ID**，UID 退化为兜底诊断信号。

固件按以下两条路径之一键入：

| 卡片状态 | HID 输出 | 说明 |
|---|---|---|
| 卡上写有 NDEF Text Record | `#<payload>\n` | **主路径** — payload 由生产时写入（如 `R01`、`track-42`） |
| 空白卡 / 非 NDEF / 解析失败 | `NFC:<UID_HEX>\n` | 兜底 — 方便诊断"这张卡是不是没写过内容" |

示例：
```
#R01\n                     ← 用户写入了 "R01"，平板查映射表决定播什么
#track-42\n                ← 用户写入了 "track-42"
#112358\n                  ← 用户写入了 "112358"（实测）
NFC:04734D67220289\n       ← 同一张卡如果擦除了 NDEF，回退为 UID
```

平板侧解析（伪代码）：

```kotlin
when (line.firstOrNull()) {
    '#'  -> handleNfcPayload(line.drop(1))  // "R01" → 查映射 → 执行
    'N'  -> handleNfcUid(line.removePrefix("NFC:"))  // 兜底，提示用户卡未配置
    else -> /* keyboard event from buttons/encoders */
}
```

### 2.2.1 Payload 编码契约

| 项目 | 约束 |
|---|---|
| 字符集 | `[A-Za-z0-9 # : / . - _]`（HID 表能直接键入的） |
| 长度上限 | 32 字节（超长截断；建议 ≤ 12 字节减少键入延迟） |
| 编码 | UTF-8 NDEF Text Record（status 字节 lang_len 任意） |
| 写入工具 | 任一手机 NFC writer app（NFC Tools 等） |
| 不支持 | 中文 / 空格 / UTF-16 / URI 类型 / 多记录 NDEF |

### 2.2.2 同卡去重

固件维护"上次触发的 UID + 时间戳"。同 UID 在 1500ms 内重复出现视为 RC522 心跳抖动（卡片未真正离开），静默丢弃。这意味着用户**必须把卡拿开 ≥1.5s 再放回**才能触发第二次。

### 2.2.3 历史方案（仅 UID）— 已废弃

```
NFC:<UID_HEX>\n   ← 14 字符 UID，留作兜底
```

废弃原因：UID 厂家随机烧录，新卡上线必须逐张录入服务端，损坏一张卡需改服务端配置。NDEF Text 方案让产品身份与卡片物理身份解耦。

### 2.3 键入速率

HID 键盘的轮询间隔为 10ms（当前描述符配置）。每个字符需要 key-down + key-up 两个报文，最快 20ms/字符。

19 个字符 × 20ms = **~380ms** 完成一次 NFC 报文传输。

实际建议字符间隔 5ms（key-down 后 5ms key-up，再 5ms 下一个 key-down），总耗时约 **~190ms**，用户感知为即时响应。

### 2.4 协议扩展（可选）

后续如果需要传递更多信息，可扩展格式：

```
NFC:<UID_HEX>:<ACTION>\n     ← 带动作码
NFC:04A1B2C3D4E5F6:R\n       ← R = 标签放置 (Read)
NFC:04A1B2C3D4E5F6:X\n       ← X = 标签移除 (eXit)
```

当前 V4 阶段只实现基础 `NFC:<UID>\n`，移除检测和扩展动作留作后续。

### 2.5 与现有按键的兼容性

NFC 字符串键入会占用 HID 报文通道。需要处理的边界情况：

| 场景 | 处理方式 |
|---|---|
| NFC 键入期间旋钮转动 | 队列缓冲，NFC 字符串完成后再发送旋钮事件 |
| NFC 键入期间按钮按下 | 按钮事件进队列，NFC 完成后发送 |
| 连续放置同一标签 | 去重 — 同一 UID 在移除前不重复发送 |
| 连续放置不同标签 | 立即发送新 UID（中断当前如果还在键入） |

实现方式：NFC 键入在独立 FreeRTOS task 中执行，通过 mutex 与 `on_input_event()` 互斥访问 HID 报文接口。

---

## 3. 软件实现

### 3.1 驱动库

使用 [`abobija/esp-idf-rc522`](https://github.com/abobija/esp-idf-rc522) (v3.4.3)：

- ESP Component Registry 可用：`idf.py add-dependency "abobija/rc522"`
- ESP-IDF ≥ 5.0，支持 SPI / I2C
- 事件驱动：卡片检测 → 激活 → 空闲 → 移除
- NTAG 支持：`GET_VERSION`, `READ`, `FAST_READ`, `WRITE`, `PWD_AUTH`
- 软件 CS 控制（不占用硬件 CS 资源）

### 3.2 SPI 配置

```c
rc522_spi_config_t driver_config = {
    .host_id = SPI2_HOST,  // FSPI on ESP32-S3
    .bus_config = &(spi_bus_config_t){
        .miso_io_num = 37,   // FSPIQ
        .mosi_io_num = 35,   // FSPID
        .sclk_io_num = 36,   // FSPICLK
    },
    .dev_config = {
        .spics_io_num = 34,  // FSPICS0 (软件控制)
    },
    .rst_io_num = 9,
};
```

ESP32-S3 SPI2 (FSPI) 通过 GPIO Matrix 灵活映射，不存在半双工限制问题。RC522 工作频率 ~8 MHz，GPIO Matrix 完全够用。

### 3.3 模块架构

新增两个文件到 `tusb_hid/main/`：

```
tusb_hid/main/
├── tusb_hid_example_main.c   # 现有：入口 + HID + 事件分发
├── input_handler.c/h         # 现有：GPIO 中断输入
├── led_indicator.c/h         # 现有：WS2812 LED
├── nfc_reader.c              # 新增：RC522 驱动 + UID 读取
└── nfc_reader.h              # 新增：NFC 接口定义
```

### 3.4 接口设计

```c
// nfc_reader.h

typedef struct {
    uint8_t uid[7];       // NTAG 7-byte UID
    uint8_t uid_len;      // 实际 UID 长度 (4 or 7)
    bool present;         // 标签是否在场
} nfc_event_t;

typedef void (*nfc_event_cb_t)(const nfc_event_t *event);

esp_err_t nfc_reader_init(void);
void nfc_reader_set_callback(nfc_event_cb_t cb);
esp_err_t nfc_reader_start(void);
esp_err_t nfc_reader_stop(void);
```

### 3.5 HID 字符串键入实现

HID 键盘发送可打印字符需要查表 ASCII → HID keycode + modifier：

| 字符 | HID Keycode | Modifier |
|---|---|---|
| `N` | 0x11 | Left Shift |
| `F` | 0x09 | Left Shift |
| `C` | 0x06 | Left Shift |
| `:` | 0x33 | Left Shift |
| `0`—`9` | 0x27, 0x1E—0x26 | 无 |
| `A`—`F` | 0x04—0x09 | Left Shift |
| Enter | 0x28 | 无 |

实现为通用的 `hid_type_string(const char *str)` 函数，可复用于未来其他字符串传输需求。

### 3.6 事件流

```
RC522 硬件中断 / 轮询
       │
       ▼
abobija/rc522 事件回调
  RC522_EVENT_PICC_STATE_CHANGED
       │
       ├─ state == ACTIVE  → 读取 UID → nfc_event_cb(present=true)
       └─ state == IDLE    → nfc_event_cb(present=false)
       │
       ▼
tusb_hid_example_main.c: on_nfc_event()
       │
       ├─ 获取 HID mutex
       ├─ hid_type_string("NFC:04A1B2C3D4E5F6")
       ├─ send_key_pulse(KEY_ENTER)
       ├─ 释放 HID mutex
       └─ LED 闪烁反馈 (紫色)
```

### 3.7 去重逻辑

```c
static uint8_t last_uid[7] = {0};
static bool tag_present = false;

void on_nfc_event(const nfc_event_t *event) {
    if (event->present) {
        if (tag_present && memcmp(last_uid, event->uid, 7) == 0) {
            return;  // 同一标签仍在场，跳过
        }
        memcpy(last_uid, event->uid, 7);
        tag_present = true;
        // 发送 HID 字符串
    } else {
        tag_present = false;
        memset(last_uid, 0, 7);
        // 可选：发送移除事件
    }
}
```

---

## 4. 安卓端集成要点

平板端应用需要：

1. **监听键盘输入** — 在前台 Activity 中捕获 `dispatchKeyEvent()` 或维护一个隐藏的 `EditText`
2. **解析 NFC 前缀** — 识别 `NFC:` 开头的字符串，提取 UID
3. **UID → 动作映射** — 本地维护一张映射表（JSON / SQLite），将 UID 映射到具体行为（切换频道、播放音效、触发动画等）
4. **标签注册流程** — 提供 UI 让用户"扫描新标签 → 命名 → 绑定动作"

映射表示例：
```json
{
  "04A1B2C3D4E5F6": { "action": "channel", "value": "jazz" },
  "04D8E9F0A1B2C3": { "action": "channel", "value": "ambient" },
  "0412345678ABCD": { "action": "effect", "value": "static" }
}
```

---

## 5. 风险与对策

| 风险 | 影响 | 对策 |
|---|---|---|
| RC522 读取距离不够（物品标签贴在非最优位置） | 用户体验差 | 标记推荐放置区域；必要时换 40×60mm 标准模块 |
| HID 字符串键入被安卓输入法拦截 | 字符丢失或变形 | 安卓端设置硬件键盘模式，禁用软键盘 |
| NFC 字符串键入与旋钮事件冲突 | HID 报文错乱 | mutex 互斥 + 事件队列 |
| FSPI 总线与其他外设冲突 | SPI 通信失败 | V4 中 FSPI 专用于 NFC，无其他 SPI 设备 |
| 多标签同时在场 | 只能识别一个 | RC522 单天线单标签限制，可接受 |

---

## 6. 实施步骤

| 步骤 | 内容 | 依赖 |
|---|---|---|
| 1 | `idf.py add-dependency "abobija/rc522"` | 无 |
| 2 | 实现 `nfc_reader.c/h` — SPI 初始化 + UID 读取 | RC522 模块到货 |
| 3 | 实现 `hid_type_string()` — ASCII → HID keycode 查表 + 逐字符发送 | 无 |
| 4 | 集成到 `tusb_hid_example_main.c` — 注册回调 + mutex | 步骤 2, 3 |
| 5 | PCB J4 连接器焊接 + 飞线测试 | PCB 到货 |
| 6 | 读取距离测试（穿透 2mm PLA） | 步骤 2 + 外壳样件 |
| 7 | 安卓端字符串解析 + 映射表 | 步骤 4 |
| 8 | 端到端联调：标签 → ESP32 → HID → 平板 → 动作 | 全部 |

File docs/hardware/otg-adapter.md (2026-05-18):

# OTG 一分二适配器 — 集成分析

> 标记号：YK16-09E V1（板上丝印，日期码 240919）
> 用途：让 Tab A9 同时处于 **Data Host**（接收 ESP32 的 USB HID）+ **Power Sink**（被外部充电器充电）
> 当前状态：作为内置子板已采购、已实测 OTG + 充电同时工作；**仅剩 dongle USB-A ↔ ESP32 之间的一根 USB 3.0 线**外露在主板侧

参考图：[otg-adapter-yk16-09e-photo.jpg](../assets/otg-adapter-yk16-09e-photo.jpg)

## 1. 这块小板内部到底在做什么

从照片可以看到三个端口和板间一颗小型 IC：

| 端口 | 类型 | 角色 | 走向 |
|---|---|---|---|
| 左（"Pad"） | **Type-C 公头**（焊接式 plug，已带短缆） | DFP 视角的 Power Sink，但宣告自己是 USB Host (DFP/Host) 的 Data Role | 插入 Tab A9 |
| 中（"Power"） | **Type-C 母座** | UFP/Sink → 上行接外部充电器（Source） | 充电器 |
| 右（"ESP32"） | **USB 3.0 Type-A 母座**（9 pin） | 标准 USB Host 提供给下游设备 | 经一根 USB 3.0 线连到 ESP32-S3 DevKitC 自带 USB-C |

中间那颗带丝印的 IC 是关键，它干三件事：

1. **CC 线协商**：在朝向平板的 Type-C plug 上呈现 Rp（pull-up），并通过 PD BMC（或固定 CC pattern）告诉平板"我是 Host + Sink"。这一步用普通 5.1k 上拉/下拉电阻**做不到**——`pcb/README.md` 里 6P 转接板 + SS34 的失败就是这个原因。
2. **Power Role / Data Role 编排**：让平板内部把电源开关切到 Sink 路径（充电器电直接进电池），同时数据通路保持在 Host 模式（向下游提供 USB Host）。
3. **VBUS 路由 + 反灌保护**：把充电器的 5V 经高边 MOSFET 转接给平板 VBUS，同时阻止平板侧 VBUS 倒灌进充电器或下游设备。

这颗 IC 大概率是 LDR6028/LDR6023C 一族（5V OTG + 充电控制器）或 IP2721 类，**没有从板上拆下来在显微镜下看丝印之前不能 100% 确认**。

## 2. ESP32-S3 实际只用 9 pin 中的 4 pin

| 引脚 | 用途 | ESP32 是否用 |
|---|---|---|
| VBUS | 5V 电源 | ✅ 走 DevKitC 的 5V 输入 |
| GND  | 地 | ✅ |
| D+ / D- | USB 2.0 高速差分对（480 Mbps） | ✅ |
| StdA_SSRX± / StdA_SSTX± / GND_DRAIN | USB 3.0 SuperSpeed 通道（5 GT/s+） | ❌ 全部空跑 |

**结论**：USB-A 一侧 9 pin 里有 5 pin 完全是浪费。把这条 USB 3.0 线消灭只需要把 4 根线（VBUS、GND、D+、D-）从 dongle 直接接到主 PCB 即可。

## 3. 三种集成路径，按风险从低到高排

### 方案 1（推荐 V4 采用）：拆 USB-A 母座，4 根短线直连主 PCB

**做法**：
1. 把 dongle 上的 USB 3.0 Type-A 母座从板上拆下来（USB-A 受电力 + 信号都在板边焊盘，9 pin 加 2-4 个机械固定脚，热风枪 30s 可下件）。
2. 露出 4 个有用焊盘：VBUS、GND、D+、D-。
3. 焊 4 根 AWG28-AWG30 信号线到主 PCB 上一个新增的 4P XH2.54 连接器（或直接 4 个焊盘 + 应力释放）。
4. 主 PCB 这一侧用一根短跳线接到 ESP32-S3 DevKitC 的 USB-C 座（保持 DevKitC 不变）；或者后续 PCB rev 把 ESP32-S3 的 GPIO19/20/5V/GND 直接走到这个 4P 连接器，整条 USB-C 线也省掉。

**优点**：
- 不动 dongle 上的 PD/CC 控制 IC，电气行为 0 变化。
- 工艺非常确定：拆一个 USB-A 座 + 焊 4 根线，半小时收工。
- USB 2.0 HS 480 Mbps 在 <10 cm 短线上完全不需要阻抗匹配/length matching。
- 任何一头坏了都好换。

**缺点**：
- dongle 仍是一块独立小板，机械固定方案要做（双面胶 / 螺丝柱 / 卡扣）。
- BOM 里仍有"成品 dongle 整片"这一项，不是真正"自研一片主 PCB 含 OTG"。

**成本**：dongle ¥15-25 + 4 根线 ¥0 + 1 个 4P 连接器 ¥0.5。比当前少一根 USB 3.0 线（~¥10）。

**适合 V4** —— 04/29 重启的 V4 范围是"技术验证 + 单套原型"，2026-05-20 前要交付。这条路径**风险几乎为零**，今天就能动手。

### 方案 2：dongle USB-A 焊盘改 2.54 排针，主 PCB 出 4P 排母

**做法**：把 USB-A 拆掉后不焊飞线，而是焊一个 4P 2.54 直插排针；主 PCB 对应位置放排母。

**优点**：可拆卸，调试期间方便单独验证 dongle 或主 PCB。

**缺点**：增加了机械应力点，长期连接可靠性略差，不如直接焊死。

**适合**：调试阶段做，到最终组装再焊死，等于"1 + 2 混合"。

### 方案 3（推迟到 V5）：把 dongle 内部电路完整复刻到主 PCB

**做法**：
1. 拆 dongle，显微镜读丝印识别 CC 控制 IC（关键步骤——丝印不清就死路一条，需要好相机 + 侧光）。
2. 找到 datasheet 后，把 IC、外围被动件、ESD/TVS 阵列、VBUS 路径 MOSFET 全部画进 KiCad 原理图。
3. 主 PCB 上加 1 个 Type-C 充电母座 + 1 根 Type-C 公头 pigtail（去往平板）。
4. 重新过 JLCPCB（5 天打板 + 3 天到货），做 PD/CC 行为回归测试。

**优点**：彻底单板化、形态最干净、可量产。

**缺点 / 风险**：
- IC 识别失败 → 整条路径作废（实物焊在板上的 SOT-23-6/QFN 丝印往往只有 2-3 字符代号，要查代号表，不一定能查到）。
- 即使识别出 IC，PD/CC 行为复刻不一定 1:1 一致；Tab A9 这类设备对 CC 时序敏感，可能要协议分析仪才能调通。
- 时间预算 ≥ 一个 PCB rev cycle，约 10-15 天，**吃光 V4 剩余周期**。

**结论**：**不要塞进 V4。** 这是 V5（如果客户后续要小批量量产）才动的活。文档里把这条路径标为"未来工作"即可。

## 4. 给 V4 的具体决定

| 项 | 决定 |
|----|---|
| OTG dongle | **保留为内置子板**（YK16-09E V1） |
| dongle ↔ ESP32 之间的 USB 3.0 线 | **消灭**：拆 USB-A 母座 → 4 根飞线 → 主 PCB 4P XH2.54 连接器 |
| 主 PCB 上是否新增 PD/CC 控制 IC | **不新增** |
| 主 PCB 上是否新增 Type-C 母座（充电输入） | **不新增**（充电仍走 dongle 上自带的 Type-C 母座） |
| 朝向平板的 Type-C 公头线 | **保留 dongle 自带的**（它就是焊在 dongle 板上的 plug + 短缆） |
| 后续工作（V5+） | 显微镜读 IC 丝印 → 复刻入主 PCB |

## 5. 在动手之前要做的小件事（10 分钟）

1. **拍一张 dongle 中央 IC 的高分辨率照片**（手机 macro 或 USB 显微镜，侧光读丝印）。即使本期不复刻，IC 型号也是 V5 文档的金字塔基。把照片存成 `docs/assets/otg-adapter-yk16-09e-ic-marking.jpg`。
2. **量一下 dongle PCB 物理尺寸**（含 Type-C plug 短缆出板方向 + 长度 + 三个端口的开口位置），决定外壳里给它留哪一块平面 + 螺丝柱。
3. **确认 USB-A 母座下件后的 4 个焊盘极性**（VBUS、D-、D+、GND，从左到右是 USB-A 标准定义，但实物板可能镜像）。可以用万用表通断从 USB-A 金属壳和 4 个 pin 之间反查。

## 6. 主 PCB 改动清单

如果 V4 PCB 还没下单，加这几项；如果已经下单，飞线接也行：

- 新增 1 个 **J5（dongle USB 数据接入）** = 4P XH2.54 立式直插，位于 PCB 边缘靠近 ESP32-S3 DevKitC USB-C 那一侧。
- 信号顺序建议 `VBUS / D- / D+ / GND`（与 USB-A 物理顺序一致，方便排查）。
- VBUS 走线宽度 ≥ 0.6 mm（承载 ≤2 A 充电电流过路）。
- D+ / D- 走差分对，宽度 ~0.2 mm，间距 ~0.13 mm，长度匹配差 < 5 mm（USB 2.0 HS 容差很宽）。
- 在 J5 上的 D+ / D- 各预留一个不焊接的 ESD 二极管位（USBLC6-2 类或 0402 TVS），现版可以 0Ω 跳过。

## 7. 文档前后兼容

- `docs/hardware/usb.md` 中"方案 A / B / C"分析仍保留为历史参考，但其结论已被 dongle 实测 + 本文件覆盖。
- `pcb/README.md` 第 113-115 行的优先级表里，本方案对应 P1（"拆解一分二线材，取内部 PCB，短线/板内固定"），现在升级为 V4 主路径。
- BOM (`docs/project/CosmoRadio-V4-BOM及报价分析.md`) 应增加：dongle YK16-09E V1 ¥X / 4P XH2.54 connector ¥0.5 / 4 根 AWG28 飞线 ¥0。下次更新 BOM 时一起补。

## 8. 一句话总结

**能集成，但分两步走。** V4 阶段把 dongle 当成"焊死的内置子板"，仅消灭 USB 3.0 长线（4 根飞线即可，零电气改动）；V5 阶段再考虑识别 dongle 上的 CC 控制 IC、整板复刻。这样 V4 deadline (2026-05-20) 守得住，长期可控性也保住了。

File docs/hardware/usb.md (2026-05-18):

# CosmoRadio V4 — USB 接口方案设计（历史文档）

> ⚠️ **2026-05-18 状态**：本文件是早期方案 A/B/C 调研记录，**已被 OTG dongle 方案替代**。
> 当前 V4 最终方案：
> - 充电 + USB Host 由 OTG dongle (YK16-09E V1) 内置子板承担，详见 [otg-adapter.md](otg-adapter.md)
> - 主 PCB 不上 USB-C 母座、不做 VBUS 注入、无 SS34
> - PCB 设计 v2 详细方案见 `~/.claude/plans/iridescent-snuggling-planet.md`
>
> 以下内容保留为历史参考。

## 2026-04-30 修正结论

本文件下面的方案分析保留为历史参考，但当前 V4 原型的 USB/充电判断已经调整：

1. 市面上低价可买到的通常是 OTG + 充电转接线/小扩展坞，不是可直接上板的裸模块。
2. 外置长线方案只能验证电气功能，不能满足产品形态。
3. 第一阶段应购买 3-5 个低价 OTG + 充电转接器，验证 Tab A9 + ESP32-S3 HID + 充电是否稳定。
4. 若稳定，拆解最小的一款，取内部 PCB 作为内置子板，用短线或焊点接入主 PCB。
5. 被动 VBUS 注入方案降级为实验项，不能作为最稳妥主路径。
6. CH224K、HUSB238 这类 PD Sink/诱骗芯片不能单独解决“平板做 USB Host，同时平板作为供电 Sink 充电”的完整问题。

当前权威记录以 [pcb/README.md](../../pcb/README.md) 为准。

## 目标设备

| 项目 | 规格 |
|---|---|
| 平板 | Samsung Galaxy Tab A9 8.7" (SM-X110, Wi-Fi) |
| USB | Type-C 2.0 |
| OTG | 支持 (USB OTG 2.0) |
| PD | 支持 (USB PD 2.0, Power Role Swap) |
| 充电 | 15W (5V/3A) |
| 电池 | 5100 mAh |
| 系统 | Android 13 / One UI 5.1 |

**关键特性**：
- **USB 2.0** → 只需 D+/D- 一对数据线，无需 USB 3.x 的 SS 高速对
- **USB PD 2.0** → 具备 Power Role Swap 能力，方案 C (PD 控制器) 的硬件基础已具备
- **15W / 5V3A** → 方案 B 的 SS34 二极管 (3A 额定) 刚好匹配最大充电电流

## 当前状态（已替换）

| 组件 | 规格 | 单价 |
|---|---|---|
| FPC Type-C 弯头线 | ESP32 → PCB USB-C 座 | ¥24.80 |
| Type-C 一分二数据线 | 充电 + OTG 分流 | ¥33.00 |
| **合计** | **占单套成本 43%** | **¥57.80** |

当前方案需要两根线 + 外部 Y 型分线器，成本高且走线复杂。

## 需求分析

```
                    ┌──────────────────────┐
  [USB-C 充电器] ──→│  J6 (充电输入)         │
     5V/2A+        │                      │
                    │    CosmoRadio PCB    │
                    │                      │
                    │  ESP32 GPIO19/20 ──→ │──→ [J5 (数据+供电输出)] ──→ [平板]
                    │  (USB HID D+/D-)     │     单根 USB-C 线
                    └──────────────────────┘
```

**数据流**：ESP32 (USB Device/HID) → D+/D- → 平板 (USB Host)
**电力流**：充电器 5V → J6 VBUS → PCB → J5 VBUS → 平板充电

## 核心技术挑战

USB-C 协议中，数据角色和供电角色默认绑定：
- **DFP (Host)** = 数据主机 = 供电方 (Source)
- **UFP (Device)** = 数据从机 = 受电方 (Sink)

我们需要的是：**平板做数据主机 (Host)，但同时接受外部供电 (Sink)**。这在标准 USB-C 中需要 PD Power Role Swap 才能实现。

但实际上，大多数 Android 平板的充电 IC 和 USB 数据通路是独立的——只要 VBUS 上有 ≥4.5V 电压，充电 IC 就会开始充电，不管 USB 控制器处于 Host 还是 Device 模式。这就是市面上大量 "OTG+充电" Y 型线能工作的原理。

---

## 方案对比

| | 方案 A：成品 OTG+充电模块 | 方案 B：PCB 被动 VBUS 注入 | 方案 C：PD 控制器 IC |
|---|---|---|---|
| **原理** | 购买成品 2-in-1 适配器 | 双 USB-C 座 + 肖特基二极管 | FUSB302/WUSB3801 IC |
| **物料成本** | ¥15-25/套 | ¥6-10/套 | ¥15-20/套 |
| **PCB 改动** | 无（外置模块） | 新增 J6 座 + 二极管 + 电阻 | 新增 IC + 外围电路 |
| **固件改动** | 无 | 无 | 需 I2C 驱动 + PD 协商 |
| **兼容性** | 高（模块已处理 PD） | 中（依赖平板充电 IC 行为） | 高（标准协议） |
| **复杂度** | 极低 | 低 | 高 |
| **推荐场景** | 首选，快速验证 | 成本敏感，已验证平板兼容 | 需要兼容所有设备 |

---

## 方案 A：成品 OTG+充电模块（推荐首选）

### 原理

购买现成 "USB-C OTG + PD 充电二合一" 适配器（内置 MCU + MOSFET 处理 PD 协商），安装在外壳内部。PCB 只需要一个 USB-C 座（J5）输出 HID 数据。

### 架构

```
[充电器] → [OTG+PD 适配器 充电口]
                    │
[PCB J5] → [OTG+PD 适配器 数据口] → [单根线] → [平板]
```

### 物料清单

| 组件 | 规格 | 参考价 | 采购关键词 |
|---|---|---|---|
| OTG+充电适配器 | USB-C 二合一，PD 60W | ¥15-25 | "USB-C OTG 充电 二合一 转接器" |
| USB-C 短线 | PCB J5 → 适配器，15cm | ¥3-5 | "USB-C 公对公 短线 25cm" |

**单套成本：¥18-30（对比当前 ¥57.80，节省 48-69%）**

### 优点
- 零 PCB 设计改动，零固件改动
- PD 协商由模块内部 MCU 处理，兼容性最好
- 如模块坏了可直接更换

### 缺点
- 外壳内部需要给模块留空间
- 增加一个连接节点（可靠性略降）
- 外观不够整合

### 选型建议
淘宝搜索 "USB-C OTG 充电 二合一"，选择：
- 支持 PD 快充（至少 18W，最好 60W）
- 输出端为 USB-C（不是 USB-A）
- 体积小巧，适合内嵌

---

## 方案 B：PCB 被动 VBUS 注入（推荐量产）

### 原理

在 PCB 上增加第二个 USB-C 座（J6，充电输入），通过肖特基二极管将充电器 VBUS 注入到平板连接的 J5 VBUS 线上。利用 Android 平板充电 IC 独立于 USB Host 控制器的特性，实现 OTG 数据 + 外部充电同时工作。

### 电路原理图

```
J6 (充电输入 USB-C)              J5 (平板输出 USB-C)
┌─────────┐                     ┌─────────┐
│ VBUS  ──┼── SS34 ──┬───────── │ VBUS    │
│ CC1 ──┼── 5.1kΩ ─┤GND       │ CC1 ──┼── 5.1kΩ ── GND
│ CC2 ──┼── 5.1kΩ ─┤GND       │ CC2 ──┼── 5.1kΩ ── GND
│ D+   NC │         │          │ D+ ←────── ESP32 GPIO20
│ D-   NC │         │          │ D- ←────── ESP32 GPIO19
│ GND  ──┼─────────┴───────── │ GND     │
│ SHLD ──┼── GND              │ SHLD ──┼── GND
└─────────┘                     └─────────┘
                                     │
                              DevKitC 5V ←┘ (ESP32 供电)
```

### CC 引脚配置说明

| 端口 | CC 配置 | 电阻 | 作用 |
|---|---|---|---|
| J6 (充电输入) | Rd pull-down | 2× 5.1kΩ to GND | 对充电器呈现为 Sink，充电器输出 5V |
| J5 (平板输出) | Rd pull-down | 2× 5.1kΩ to GND | 对平板呈现为 UFP Device，平板进入 Host 模式 |

### 供电路径

**无充电器时**：
```
平板 VBUS (5V) → J5 VBUS → DevKitC 5V → ESP32 供电
（二极管反偏，J6 不导通）
```

**接入充电器时**：
```
充电器 (5V~5.2V) → J6 VBUS → SS34 (Vf≈0.3V) → ~4.7-4.9V → J5 VBUS
平板充电 IC 检测到 VBUS 电压 → 开始充电
同时：ESP32 D+/D- 维持 HID 通信不中断
```

大多数充电器输出 5.0-5.2V，经肖特基二极管后约 4.7-4.9V，足以触发平板充电 IC（阈值通常 4.0-4.5V）。平板自身在 Host 模式也会输出约 5V VBUS，但当外部供电电流能力远大于平板 VBUS 输出时（充电器 2A+ vs 平板 OTG 输出 500mA），平板充电 IC 会净吸收电流，实现充电。

### 物料清单

| 组件 | 封装 | 数量 | 参考价 | 备注 |
|---|---|---|---|---|
| USB-C 母座转接板 (DIP) | 2.54mm through-hole | 2 | ¥2-3/个 | "USB-C 母座 转接板 DIP 2.54" |
| SS34 肖特基二极管 | SMA/DO-214AC | 1 | ¥0.3 | Vf=0.3V@3A，防倒灌 |
| 5.1kΩ 电阻 | 0805 或直插 | 4 | ¥0.1 | CC 引脚配置 |
| **合计** | | | **¥5-7/套** | |

**单套成本：¥5-7（对比当前 ¥57.80，节省 88-91%）**

### 模块选型：USB-C 母座转接板

选择 DIP (2.54mm 间距) 直插模块，引出至少 VBUS / GND / D+ / D- / CC1 / CC2 六个引脚。

推荐选择条件：
- 引出全部引脚（至少 6P，最好 12P/16P）
- 2.54mm 排针间距，可直接插面包板或焊接排母
- 有固定孔（M2 或 M2.5）

淘宝搜索关键词：
- "USB Type-C 母座 转接板 DIP"
- "USB-C breakout board 2.54mm"
- "Type-C 测试板 引脚全引出"

### PCB 设计改动

在现有 80×50mm PCB 基础上：
1. **新增 J6 位置**：USB-C 充电输入座，放置在 PCB 边缘（与 J5 同侧或对侧）
2. **新增 SS34 二极管**：J6 VBUS → SS34 → J5 VBUS 路径
3. **新增 4× 5.1kΩ 电阻**：J5 和 J6 各两个 CC pull-down
4. **走线**：VBUS 走线宽度 ≥ 1mm（承载 2A）

如果使用 DIP 转接板模块，J5 和 J6 可以用排母座接口代替板载 USB-C 座，大幅降低 PCB 贴片复杂度。

### 兼容性注意

此方案依赖平板内部充电 IC 在 USB Host 模式下仍接受 VBUS 充电。需要实测验证：

**验证步骤**：
1. 用面包板搭建原型：两个 USB-C 转接板 + SS34 + 5.1kΩ 电阻
2. 接入充电器和平板，确认平板是否进入充电状态
3. 同时接入 ESP32 HID，确认数据通信不受影响
4. 测量 VBUS 电压、充电电流、温升

**已知兼容情况**：
- 三星 Galaxy Tab 系列：历史上对 OTG+充电支持较好
- 大部分 Android 10+ 设备：充电 IC 独立于 USB Host 模块

**不兼容的补救**：若平板在 Host 模式拒绝 VBUS 充电，回退到方案 A。

---

## 方案 C：PD 控制器 IC（参考，暂不推荐）

### 原理

使用 FUSB302 或 WUSB3801 等 USB PD 控制器 IC，在固件中实现 PD 协议协商，执行 Power Role Swap（将平板从 Source 切换为 Sink）和 Data Role Swap（保持平板为 Host），从而标准化地解决供电和数据角色分离问题。

### 关键 IC

| IC | 价格 | 接口 | 功能 | 备注 |
|----|---|---|---|---|
| FUSB302 | ¥3-5 | I2C | CC 检测 + PD BMC 通信 | 开源社区支持好，需 MCU 驱动 |
| WUSB3801 | ¥3-4 | I2C/GPIO | CC 检测 + DRP 自动切换 | 更简单，但不支持完整 PD |
| TPS65987 (TI) | ¥15+ | I2C | 完整 PD 3.0 控制器 | 贵，功能过剩 |

### 复杂度评估

- 需要 FUSB302 + 外围电路（10+ 被动元件）
- 需要 ESP32 I2C 驱动 + PD 协议栈固件（约 500-1000 行代码）
- 需要 MOSFET 做 VBUS 开关
- PCB 面积增加约 15×10mm
- 调试和验证周期长

**结论：复杂度远超项目需求，留作未来需要兼容所有设备时的升级路径。**

---

## 推荐实施路径

```
第一步：方案 B 原型验证（面包板，1-2 天）
  │
  ├── 成功 → 方案 B 集成到 PCB V4
  │          成本 ¥5-7/套，节省 ¥50+/套
  │
  └── 失败（平板不充电）→ 方案 A
                          成本 ¥18-30/套，仍节省 ¥28-40/套
```

### 第一步：面包板验证方案 B

所需材料：
- 2× USB-C 母座转接板（DIP）
- 1× SS34 肖特基二极管
- 4× 5.1kΩ 电阻
- 面包板 + 杜邦线
- ESP32-S3 DevKitC（现有）
- 充电器 + USB-C 线 + 平板

接线验证 VBUS 注入是否能触发平板充电，同时确认 HID 不中断。

### 第二步：PCB 集成

验证通过后，在 KiCad 原理图中：
1. 新增 J6 (USB-C 充电输入) 连接器符号
2. 新增 SS34 二极管符号
3. 新增 4× 5.1kΩ CC 电阻
4. 更新 PCB layout，J6 放置在板边缘
5. VBUS 走线加宽到 1mm+

---

## 附录 A：USB-C 引脚定义速查

```
USB-C 母座 (Receptacle) 引脚定义 — 简化 USB 2.0 用途

Pin  Name    用途
A1   GND     地
A4   VBUS    电源 5V
A5   CC1     Configuration Channel 1
A6   D+      USB 2.0 数据+
A7   D-      USB 2.0 数据-
A8   SBU1    (不用)
A9   VBUS    电源 5V
A12  GND     地

B1   GND     地
B4   VBUS    电源 5V
B5   CC2     Configuration Channel 2
B6   D+      USB 2.0 数据+ (连接到 A6)
B7   D-      USB 2.0 数据- (连接到 A7)
B8   SBU2    (不用)
B9   VBUS    电源 5V
B12  GND     地

USB 2.0 简化接法：
- VBUS: A4+A9+B4+B9 全部短接
- GND:  A1+A12+B1+B12 全部短接
- D+:   A6+B6 短接
- D-:   A7+B7 短接
- CC1:  A5 (独立)
- CC2:  B5 (独立)
```

## 附录 B：CC 引脚电阻配置速查

| 角色 | CC 电阻 | 阻值 | 效果 |
|---|---|---|---|
| Sink (UFP/Device) | Rd pull-down to GND | 5.1kΩ | 告知对方"我是设备" |
| Source (DFP/Host) Default USB | Rp pull-up to VBUS | 56kΩ | 告知对方"我是主机，可提供默认电流" |
| Source 1.5A | Rp pull-up to VBUS | 22kΩ | 告知对方"可提供 1.5A" |
| Source 3A | Rp pull-up to VBUS | 10kΩ | 告知对方"可提供 3A" |

本项目 J5/J6 均使用 **Rd 5.1kΩ pull-down**（Sink 配置）。

## 附录 C：参考资料

- [All About USB-C: Example Circuits (Hackaday)](https://hackaday.com/2023/08/07/all-about-usb-c-example-circuits/)
- [USB Type-C Configuration Channel (Benson Leung)](https://medium.com/@leung.benson/usb-type-c-s-configuration-channel-31e08047677d)
- [Simultaneously Charging and OTG in Type C (TI E2E)](https://e2e.ti.com/support/power-management-group/power-management/f/power-management-forum/949928/simultaneously-charging-and-otg-in-type-c)
- [Teardown: USB-C OTG Adapter with PD Charging (Gough's Tech Zone)](https://goughlui.com/2023/10/29/teardown-t-tersely-usb-c-otg-adapter-with-pd-charging-pass-through/)
- [USB-C OTG + Charge Discussion (XDA Forums)](https://xdaforums.com/t/usb-otg-charge.3588019/page-2)
- [ESP32-S3-USB-OTG Dev Board (Espressif)](https://docs.espressif.com/projects/esp-dev-kits/en/latest/esp32s3/esp32-s3-usb-otg/user_guide.html)
- [USB OTG Host Adapter with Charging (Elektroda)](https://www.elektroda.com/rtvforum/topic3449427.html)

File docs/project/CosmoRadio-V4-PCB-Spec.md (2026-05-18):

# CosmoRadio V4 — PCB 载板规格 (v2.0)

> **版本**：v2.0（2026-05-18 整理，对应 PCB Plan v2）
> **范围**：技术方案验证 + 单套原型制作；JLCPCB 免费打样 5 片
> **设计文档**：详细执行步骤见 `~/.claude/plans/iridescent-snuggling-planet.md`
> **GPIO 权威表**：`/CLAUDE.md` "GPIO Pin Assignments"

---

## 设计理念

**Carrier Board（载板）** — ESP32-S3 DevKitC N16R8 通过两条 1×22 单排母插入 PCB，所有外设通过 5 路 XH2.54 JST 连接器即插即用。**整块板的本质是"连接器转接板 + EC11 RC 去抖网络"**——零有源元件，只有 8 个 0805 贴片被动件 + 6 个 THT 连接器。

### 为什么是 DevKitC N16R8 + carrier board

| 对比项 | ESP32-S3 SuperMini (V3) | ESP32-S3 DevKitC N16R8 (V4) |
|---|---|---|
| USB HID | TinyUSB ✓ | TinyUSB ✓（同一套代码）|
| BLE | 有（未用）| 无（不需要）|
| GPIO 数量 | 11 可用 | 36+ 可用 |
| 价格 (1688) | ¥15 | ¥8-10 |
| 尺寸 | 25×18mm | 70×27mm |
| Flash / PSRAM | 4MB / 0 | 16MB / 8MB Octal |
| 固件迁移量 | — | 仅改 GPIO 编号 + sdkconfig |

ESP32-S3 有原生 USB OTG，TinyUSB HID 代码直接跑。GPIO 多 3 倍，方便加 NFC。N16R8 的 16MB Flash + 8MB PSRAM 足够 NFC 大缓冲。

### V3 问题 → V4 解决

| V3 问题 | V4 方案 |
|---|---|
| 飞线杂乱，杜邦线无锁扣 | PCB 走线 + JST-XH 带卡扣连接器 |
| 万能板空间局促 + 容易脱焊 | 100×100mm 双面 PCB，机械稳定 |
| 组装需焊接技能 | 全插拔 + 螺丝固定，附图文指南 |
| SuperMini GPIO 不够 | DevKitC 36+ GPIO，充裕 |
| 旋钮一格一格不准 | EC11 A/B 加 10kΩ + 10nF RC 去抖 |
| USB-C 母座焊接难 + 充电方案不稳 | OTG dongle (YK16-09E V1) 内置子板，主 PCB 不上 USB-C |

---

## 原理图

### GPIO 引脚分配（V4 终版）

> 完整权威表见 [/CLAUDE.md](../../CLAUDE.md)。下表为 PCB 视角概览。

| 功能 | GPIO | 连接器 | PCB 位置 |
|---|---|---|---|
| EC11-L (用户左旋钮) A/B/SW | 42 / 41 / 40 | J1 (5P) | **PCB 左侧中段** |
| EC11-R (用户右旋钮) A/B/SW | 17 / 18 / 8 | J2 (5P) | **PCB 右侧中段** |
| Action Button | 1 | J3 (2P) | **PCB 左侧靠前** |
| RC522 NFC RST/IRQ/MISO/MOSI/SCK/CS | 4 / 5 / 6 / 7 / 15 / 16 | J4 (8P) | **PCB 右侧** |
| OTG USB D-/D+ | 19 / 20 | J5 (4P) | **PCB 左侧靠后** (near USB-C 端) |
| 板载 RGB LED | 48 | DevKitC 板载 | — |

> "PCB 位置" 列基于 DevKitC 安装朝向（USB-C OTG 朝外壳后侧 = PCB 顶部）。`pcb/asset/ESP32-S3-DevKitC-N16R8.png` 是 datasheet 标准视角（USB-C 在下），用户安装 = 180° 旋转后视角。

### 连接器定义（5 路 XH2.54）

| 连接器 | 类型 | 引脚定义（从 pin 1 顺序）| 线缆长度 | 方向 |
|---|---|---|---|---|
| J1 | XH2.54 5P 立式直针 | A=GPIO42, B=GPIO41, SW=GPIO40, GND, GND | 20cm | → 左旋钮 (EC11) |
| J2 | XH2.54 5P 立式直针 | A=GPIO17, B=GPIO18, SW=GPIO8, GND, GND | 20cm | → 右旋钮 (EC11) |
| J3 | XH2.54 2P 立式直针 | SIG=GPIO1, GND | 25cm | → Kailh BOX 按钮 |
| J4 | XH2.54 8P 立式直针 | CS=16, SCK=15, MOSI=7, MISO=6, IRQ=5, GND, RST=4, 3V3 | 15cm | → RC522 NFC mini |
| J5 | XH2.54 4P 立式直针 | VBUS, D-=19, D+=20, GND | <10cm | → OTG dongle USB-A 拆后 4 飞线 |

> **J4 引脚顺序与 RC522 mini 模块物理排针 1:1**，端子线直压无需交叉。详见 [docs/hardware/nfc.md](../hardware/nfc.md)。
> **J5 引脚顺序与 USB-A 公头物理引脚顺序一致**（VBUS, D-, D+, GND），方便 dongle 拆解后直焊。详见 [docs/hardware/otg-adapter.md](../hardware/otg-adapter.md)。

### DevKitC 插座（两条 1×22 单排母）

| Ref | 类型 | 间距 |
|-----|---|---|
| U1A | 1×22P 排母 2.54mm 立式 | — |
| U1B | 1×22P 排母 2.54mm 立式 | — |
| U1A ↔ U1B 中心距 | **22.86mm** (= 9 × 2.54mm pitch) | breadboard 兼容 |

**为什么用两条单排母而非一条 2×22 双排母**：
- 单排母可独立对齐，安装时容差大、不会因双排"一边歪导致整体插不进"
- 单排零件 LCSC 可选范围更大，本身更便宜
- 焊接工艺更简单（每条 22 个焊点串行做完再做下一条）

### EC11 RC 去抖网络（关键设计）

每个 EC11 旋钮的 A/B 信号各加：
- **10kΩ 上拉电阻**到 3V3（增强边沿陡度，比内部 ~45kΩ 强 4.5×）
- **10nF 电容**对 GND（与上拉电阻形成 RC 低通滤波器，τ = 100µs）

**工作原理**：EC11 机械触点抖动通常在 µs 级；10nF 电容把高频抖动吸收掉，但用户手转的 ~10 detent/s 信号（频率 <100Hz）原封通过。这是 Ben Buxton 1998 年《Rotary encoders》经典文档里的标准接法。

**布局要求**：R/C 紧贴各自的 J1/J2 连接器（A/B pin 旁 ≤5mm），电容对 GND 走线尽量短。

```
J1.1 (A=GPIO42) ──┬──── 10kΩ ──── 3V3
                  ├──── 10nF ──── GND
                  └─── 走线到 DevKitC GPIO42

J1.2 (B=GPIO41) ──┬──── 10kΩ ──── 3V3
                  ├──── 10nF ──── GND
                  └─── 走线到 DevKitC GPIO41

(J2 同结构，A=17 / B=18)
```

**不加去抖网络的 pin**：
- EC11 SW（按下事件慢，软件 debounce 足够）
- Action Button (J3 SIG, GPIO1)
- NFC SPI 信号（模块板载已有去耦）

### 电路要点

1. **USB HID 通路**：DevKitC native USB → 排针 GPIO19/20 → J5 4P → dongle USB-A 拆后 4 飞线 → dongle 输出 Type-C plug → 平板
2. **供电**：外部充电器 → dongle Type-C 母座 → dongle 内部 CC IC 协商 → 平板 (充电) + dongle 输出 5V 给 DevKitC (USB 通路)
3. **3V3 来源**：DevKitC 板载 AMS1117-3.3 LDO
4. **EC11 上拉**：A/B 各 10KΩ 上拉到 3V3，A/B 各 10nF 对 GND（共 8 个 0805 贴片件）
5. **NFC SPI**：SPI2 经 GPIO Matrix 走 GPIO 4/5/6/7/15/16（不是 FSPICLK 硬件 pin，因为那些 pin 在 octal PSRAM 占用范围内）
6. **板载 LED**：DevKitC GPIO48 板载 WS2812B RGB，不外接

---

## PCB 物理规格

| 参数 | 值 |
|---|-----|
| 尺寸 | **100mm × 100mm**（JLCPCB 免费打样上限）|
| 层数 | 2 层 |
| 板厚 | 1.6mm |
| 铜厚 | 1oz |
| 表面处理 | HASL（无铅）|
| 阻焊 | 黑色 |
| 丝印 | 白色，每个连接器标注接口名 + 引脚功能 + **"OTG USB-C: DO NOT PLUG"** 警示 |
| 安装孔 | 4× M2.5（四角，孔径 2.7mm）|

### 布局建议

```
                ↑ BACK (远离用户, USB-C 朝外)
   ┌────────────────────────────────────────────┐
   │ ⊙ H1                                ⊙ H2  │
   │                                            │
   │  ┌──────────┐                              │
   │  │ J5 USB   │  ◄── GPIO 19/20 + 5V/GND     │
   │  │   4P     │                              │
   │  └──────────┘                              │
   │                                            │
   │  ┌──────┐ ┌──────┐                         │
   │  │ U1A  │ │ U1B  │            ┌──────────┐ │
   │  │ 1×22 │ │ 1×22 │            │ J4 NFC   │ │
   │  │      │ │      │            │   8P     │ │
   │  │ 左列  │ │ 右列  │            └──────────┘ │
   │  │      │ │      │                         │
   │  │      │ │      │            ┌────────┐   │
   │  │      │ │      │            │ J2     │   │
   │  │      │ │      │            │ EC11-R │   │
   │  │      │ │      │            │  5P    │   │
   │  └──────┘ └──────┘            └────────┘   │
   │                                            │
   │   R3,R4,C3,C4 (10k/10n for ENC2)           │
   │                                            │
   │  ┌────────┐                                │
   │  │ J1     │ ◄── GPIO 42/41/40              │
   │  │ EC11-L │                                │
   │  │   5P   │                                │
   │  └────────┘                                │
   │                                            │
   │  R1,R2,C1,C2 (10k/10n for ENC1)            │
   │                                            │
   │  ┌────────┐                                │
   │  │ J3 BTN │ ◄── GPIO 1 + GND               │
   │  │   2P   │                                │
   │  └────────┘                                │
   │                                            │
   │   CosmoRadio V4 r1.0      OTG USB-C:       │
   │   dehonghao.com           DO NOT PLUG      │
   │ ⊙ H4                                ⊙ H3  │
   └────────────────────────────────────────────┘
                ↓ FRONT (朝向用户)
```

### 丝印标注

- 每个 JST 连接器旁标注：**接口名 + pin 顺序的信号名**（如 J4 旁标 `NFC | CS SCK MOSI MISO IRQ G RST 3V3`）
- 顶部丝印：`CosmoRadio V4 r1.0` + `dehonghao.com`
- **底部丝印警示**：`⚠ OTG USB-C: DO NOT PLUG`（必须，避免误插烧端口）
- 安装孔旁不丝印（避免遮挡螺丝）
- 所有丝印高 ≥ 1.0mm（JLC DFM 最小 0.8mm，留余量）

---

## 配套线缆（预压 JST-XH 端子）

| 线缆 | 规格 | JST 端 | 外设端 | 数量/套 |
|---|---|---|---|---|
| EC11 线缆 ×2 | 5P × 20cm | JST-XH 5P 公 | 直焊 EC11 引脚 | 2 |
| Action Button 线缆 | 2P × 25cm | JST-XH 2P 公 | 焊到 Kailh BOX 轴 | 1 |
| NFC 线缆 | 8P × 15cm | JST-XH 8P 公 | 8P 排针压接到 RC522 | 1 |
| OTG dongle 线缆 | 4P × <10cm | JST-XH 4P 公 | 焊到 dongle 拆 USB-A 后的 4 焊盘 | 1 |
| dongle Type-C 输出 | Type-C plug + 短缆 | （dongle 自带）| 插入平板 | 1 |
| dongle Type-C 充电输入 | Type-C 母座 | （dongle 自带）| 接外部充电器 USB-C | 1 |

> 单套原型阶段：JST 端预压好，外设端预焊好，用户只需插 JST 到主板。

---

## 制造

| 项目 | 方案 | 成本 |
|---|---|---|
| PCB 打样 | JLCPCB 免费打样 5 片 | ¥0 + 国内运费 ~¥20 |
| SMT 贴片 | **不上**——单套原型，8 个 0805 手焊 ~5min | ¥0 |
| 手焊部分 | 2× 1×22 排母 + 5× JST 母座 + 8× 0805 (R+C) | ~15min/板 |

### 生产流程

```
KiCad 设计完成
  → JLCPCB 下单（仅打板，不贴片）
  → 5 片裸板到货（国内 ~3-5 天）

焊接元件（我们做，~15min/板）
  → R1-R4 (10kΩ 0805) × 4
  → C1-C4 (10nF 0805) × 4
  → U1A + U1B (1×22 排母) × 2
  → J1-J5 (XH2.54 母座) × 5

预压 JST 线缆（5 根）
  → EC11 5P × 2 / BTN 2P × 1 / NFC 8P × 1 / OTG dongle 4P × 1

质检
  → 万用表通断（5V/3V3/GND 到 J5/J4/U1 各 pin）
  → 插入 DevKitC，UART USB-C 烧固件，逐一测试各端口
  → 旋钮转动测试（验证 RC 去抖效果，每格一个事件）

打包
  → PCB + DevKitC + dongle + 线缆 + 螺丝 = 1 套电子件
```

---

## 工具需求

| 工具 | 用途 |
|---|---|
| KiCad 10+ | 原理图 + PCB layout |
| circuit-synth + Freerouting | AI 驱动的设计 + 自动布线（见 `~/.claude/skills/pcb`）|
| JLCPCB | 打板下单 |
| 万用表 | 通断测试 |
| JST-XH 压线钳 | 预压端子线缆 |
| 烙铁 + 助焊剂 + 加热台 | 焊接 0805 + 直插件 |

---

## 设计追溯

- 完整设计计划 + 风险评估：`~/.claude/plans/iridescent-snuggling-planet.md`
- DevKitC 物理引脚分布权威表：`/CLAUDE.md` + `pcb/asset/ESP32-S3-DevKitC-N16R8.png`
- OTG dongle 集成方案：`docs/hardware/otg-adapter.md`
- NFC 模块接口：`docs/hardware/nfc.md`
- 飞线万能板实证：`pcb/asset/飞线测试版本-顶视图.JPG` + `飞线测试版本-飞线图.JPG`

---

## 历史归档

v1.0（2026-04-01 出稿，对应 V4 启动期）已被本 v2.0 取代。v1.0 的主要差异：
- 板尺寸 80×50mm → 100×100mm
- 连接器 4 路 → 5 路（新增 J5 OTG USB）
- 包含 USB-C 母座 J5/J6 → 移除（OTG dongle 接管充电）
- 包含 SS34 防倒灌 + 4× 5.1k CC 下拉 → 全移除
- 包含 LED 4P 顶部模块连接器 → 移除（用 DevKitC GPIO48 板载 RGB）
- GPIO 编号是 V3 残留（顺序 1-8）→ 更新为 V4 终版（与固件实测一致）
- 单排母 vs 双排母未定 → **确定两条 1×22 单排母**
- 旋钮稳定性未涉及 → **新增 10kΩ + 10nF RC 去抖网络**

如需查阅 v1.0 内容，请 `git log -- docs/project/CosmoRadio-V4-PCB-Spec.md`。

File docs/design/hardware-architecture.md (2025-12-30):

# 硬件架构设计

## 概述

本项目将 E5 Ultra 安卓掌机改造为桌面式 Radio 接收器，核心思路是：
1. 保留 E5 Ultra 的屏幕、主板、电池
2. 移除原有物理按键
3. 通过 ESP32 蓝牙 HID 实现自定义输入
4. 3D 打印新外壳，实现 iMac G3 风格造型

## 系统架构

```
┌─────────────────────────────────────────────────────────┐
│                    3D 打印外壳                           │
│  ┌─────────────────────────────────────────────────┐   │
│  │                  E5 Ultra                        │   │
│  │  ┌───────────────────────────────────────────┐  │   │
│  │  │            5寸 IPS 屏幕                    │  │   │
│  │  │   ○ 模式    ◉ 主显示区    ○ 频率         │  │   │
│  │  └───────────────────────────────────────────┘  │   │
│  │               Android 系统                       │   │
│  │               蓝牙 HID Host                      │   │
│  └──────────────────┬──────────────────────────────┘   │
│                     │ 蓝牙                              │
│  ┌──────────────────┴──────────────────────────────┐   │
│  │           Adafruit HUZZAH32 (ESP32)             │   │
│  │               蓝牙 HID Device                    │   │
│  └────┬─────────────┬─────────────────┬────────────┘   │
│       │             │                 │                 │
│   ┌───┴───┐    ┌────┴────┐      ┌────┴────┐           │
│   │ EC11  │    │  EC11   │      │ 微动开关 │           │
│   │频率旋钮│    │模式旋钮 │      │顶部按钮  │           │
│   └───────┘    └─────────┘      └─────────┘           │
└─────────────────────────────────────────────────────────┘
```

## E5 Ultra 改造

### 保留部件
- 5寸 IPS 全贴屏（1280x720，60Hz）
- T620 主板及芯片组
- 5000mAh 电池
- USB-C 充电接口
- WiFi/蓝牙模块

### 移除部件
- 后壳
- 下方物理按键区域（摇杆、D-pad、ABXY 按钮等）
- 原有输入控制板

### 改造要点
- 只保留前壳+屏幕+主板组件
- 前壳将贴合在新 3D 打印外壳的正面
- 从主板测试点取电为 ESP32 供电

## ESP32 蓝牙 HID 方案

### 控制器选型
选用 Adafruit HUZZAH32 - ESP32 Feather，原因：
- ESP32 双模蓝牙，支持 Classic BT 和 BLE
- 内置电池管理，BAT 引脚支持锂电池直连
- 体积小巧，便于内置
- ESP-IDF 开发生态成熟

### 输入设备映射

| 输入设备 | 硬件接口 | HID 映射 |
|---|---|---|
| EC11 #1 | 旋转编码器 A/B 相 | 上/下方向键 |
| EC11 #2 | 旋转编码器 A/B 相 | 左/右方向键 |
| 顶部按钮 | 微动开关 | Enter 键 |

### 通信协议
- 使用蓝牙 HID 协议（Human Interface Device）
- ESP32 作为 HID Device（键盘）
- E5 Ultra Android 系统作为 HID Host
- 配对后自动连接，模拟标准键盘输入

## 供电方案

### 电源来源
从 E5 Ultra 主板测试点取电，输出电压约 3.5~3.7V（电池电压）

### 接入方式
- 电源正极接入 HUZZAH32 的 BAT 引脚
- BAT 引脚额定输入范围：3.5V - 4.2V
- 共地连接

### 充电
- E5 Ultra 原有 USB-C 接口保留
- 通过 USB-C 为整机充电
- ESP32 随 E5 Ultra 一同开关机

## 外壳设计

### 设计风格
- 参考 iMac G3 的斜面站立式造型
- 屏幕面板向后倾斜，便于桌面使用
- 底部加宽作为稳定支撑

### 三圆形遮罩设计
利用 E5 Ultra 的 5 寸矩形屏幕，通过外壳开孔实现三个圆形显示区：
- **中间大圆**: 主显示区，展示核心内容
- **左侧小圆**: 模式指示区
- **右侧小圆**: 频率指示区

软件界面需配合此遮罩设计，在对应位置显示相应内容。

### 开孔布局
- 正面上部：三个圆形开孔（屏幕区域）
- 正面下部：两个圆形开孔（EC11 旋钮）
- 顶部：条状开槽（顶部按钮）
- 背部/底部：USB-C 充电口、散热孔

### 制造工艺
- Fusion 360 建模
- FDM 3D 打印
- 建议使用 PLA 或 PETG 材料

## 后续开发

1. **ESP32 固件**: 使用 ESP-IDF 开发蓝牙 HID 键盘固件
2. **外壳迭代**: 根据实际装配情况调整 3D 模型
3. **整机组装**: 布线、固定、测试

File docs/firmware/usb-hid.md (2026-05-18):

# USB HID 固件实现

> ⚠️ **2026-05-18 状态**：本文件原始内容（V2 XIAO ESP32S3 时代 GPIO 1/D0 描述）已过时，整理为下方简明版。
> 完整 V4 实现细节见 [`/CLAUDE.md`](../../CLAUDE.md) "HID Key Mappings" + "GPIO Pin Assignments"。

## 概述

基于 **TinyUSB** 的 USB HID 键盘实现，运行在 **ESP32-S3 DevKitC N16R8**。把物理输入（双 EC11 旋钮 + Kailh BOX 按钮 + RC522 NFC）转换为键盘事件。USB OTG 通过外置 dongle (YK16-09E V1) 实现"平板 USB Host + 充电"同时工作。

V1/V2 BLE HID 方案已删除（见 git 历史）；V3 SuperMini → V4 DevKitC N16R8 已完成迁移。

## 当前固件入口

| 文件 | 职责 |
|---|---|
| `main/tusb_hid_example_main.c` | TinyUSB 初始化 + ASCII→HID keycode 编码 + 多键并发报告管理（`s_pressed_keys[6]` + `s_hid_mutex`）|
| `main/input_handler.c/h` | GPIO 中断驱动状态机：Action Button + 双 EC11 (A/B/SW)，事件队列分发 |
| `main/nfc_handler.c/h` | RC522 SPI (1MHz, SPI2 via GPIO Matrix) + NDEF Text Record 解析 + 1.5s 同卡去重 |
| `main/led_indicator.c/h` | DevKitC GPIO48 板载 WS2812B RGB 状态指示 |

## HID 输入映射

权威表见 [/CLAUDE.md](../../CLAUDE.md) "HID Key Mappings"，简要：

| 输入 | HID 按键 |
|---|---|
| Action Button (GPIO1) 按 | Enter |
| EC11-L (GPIO 42/41/40) 旋转 / 按 | ↑/↓ / F1 |
| EC11-R (GPIO 17/18/8) 旋转 / 按 | →/← / F2 |
| NFC 卡 (NDEF Text) | `<payload>\n` |
| NFC 卡 (UID 兜底) | `NFC:<UID_HEX>\n` |

## LED 行为

DevKitC GPIO48 板载 RGB（不外接 LED）：

| 事件 | 颜色 |
|---|---|
| 启动完成 | 绿色闪烁 |
| 按钮按下 | 红色 |
| NFC 识别中 | 蓝色 |

## 构建与烧录

```bash
get_idf                                    # 激活 ESP-IDF 环境
idf.py set-target esp32s3                  # 首次
idf.py build
idf.py -p /dev/cu.usbmodem* flash monitor  # 走 DevKitC UART USB-C 烧录，不走 OTG USB-C
```

> ⚠️ **烧录走 UART USB-C，不要走 OTG USB-C** — V4 PCB 设计下 GPIO19/20 连到 J5 接 dongle 注入 VBUS，外部插 OTG USB-C 会冲突。

## 已知技术债

详见 [/CLAUDE.md](../../CLAUDE.md) "Known Limitations / Technical Debt"：

- NFC SPI 时钟暂用 1MHz（PCB 版可尝试拉回 5MHz）
- HID 多键并发已修复（2026-05-08 `s_pressed_keys[6]` + mutex）
- NFC 启动失败容错已实现（2026-05-10 warn 不 abort）
- sdkconfig 已升级 N16R8（2026-05-08 16MB QIO + 8MB Octal PSRAM）

## 硬件需求

详见 [/CLAUDE.md](../../CLAUDE.md) "Hardware Target (V4)" + [/docs/project/CosmoRadio-V4-PCB-Spec.md](../project/CosmoRadio-V4-PCB-Spec.md)。

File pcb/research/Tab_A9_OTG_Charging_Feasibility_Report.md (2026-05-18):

# CosmoRadio V4 专用 Tab A9 半主动 USB-C OTG + 充电方案可行性调研报告

> ⚠️ **OBSOLETE — 2026-05-18 状态**：本报告是 2026-04-30 Manus 调研产出的"半主动 SS34 注入"方案可行性评估。
> 实测结论：**6P 转接板 + SS34 复刻方案失败**，无法让 Tab A9 同时进入 Data Host + Power Sink 状态。
> 当前 V4 实际方案：**外购 OTG dongle (YK16-09E V1) 内置子板**，详见 [`docs/hardware/otg-adapter.md`](../../docs/hardware/otg-adapter.md)。
> 本报告仅保留为"为什么不走半主动路线"的历史依据。

## 1. 方案工作原理与机制分析

在 USB-C 和 Android 体系下，实现平板作为 USB Host（控制 ESP32-S3）同时接受外部充电，涉及到 USB 角色协商和电源路径管理的复杂机制。

### 1.1 标准行为与设备特定行为
*   **标准 USB-C DRP (Dual Role Port) 行为**：标准的 USB-C 接口通过 CC (Configuration Channel) 引脚进行角色协商。供电端（Source）在 CC 引脚上提供上拉电阻（Rp），受电端（Sink）提供下拉电阻（Rd，5.1kΩ）。双角色端口（DRP）在未连接时会交替呈现 Rp 和 Rd。当平板作为 USB Host 时，标准行为是它必须作为供电端（Source），向外输出 5V VBUS，此时其内部 CC 逻辑呈现 Rp [1]。
*   **SimulCharge / ACA (Accessory Charger Adapter) 机制**：在早期的 Micro-USB 时代，USB BC 1.2 规范定义了 ACA 机制，通过在 ID 引脚上接特定阻值的电阻（如 124kΩ 或 36.5kΩ），允许设备同时作为 USB Host 并接受充电 [2]。
*   **设备特定行为（Samsung 专有实现）**：在 USB-C 时代，虽然 USB PD 规范支持 Power Role Swap（电源角色交换）和 Data Role Swap（数据角色交换），但这需要完整的 PD 协议栈支持。对于低成本的半主动方案（不使用 PD 芯片），三星等厂商在底层固件中保留了类似 ACA 的模拟检测逻辑，或者允许在特定的 CC 电阻组合及 VBUS 强制注入时，触发“Host 模式下充电”的隐藏状态。这属于**高度设备特定**的行为，严重依赖于平板的内核驱动和充电 IC 固件 [3]。

## 2. 可行电路拓扑建议

针对“低复杂度、可集成到 PCB、不使用完整 PD 固件栈”的需求，建议采用以下半主动注入拓扑：

### 2.1 核心连接关系
1.  **外部充电器 VBUS 注入**：外部 5V 电源通过一个低压降的肖特基二极管（如 SS14 或 SS24）或者 P-MOSFET 理想二极管电路，注入到连接平板的 VBUS 线上。
2.  **平板端 CC 引脚配置**：
    *   在连接平板的 USB-C 插头的 CC 引脚上，需要配置特定的电阻网络来“欺骗”平板。
    *   **常规尝试**：接 5.1kΩ 下拉电阻（Rd）到地，使平板认为连接了充电器（进入 Sink 模式接受充电），同时强行在 D+/D- 上进行数据通信。
    *   **三星特定尝试（模拟 ACA）**：部分三星设备可能需要特定的 Rp 上拉（例如 56kΩ 到 5V）或者在 CC 线上施加特定电压，配合 D+/D- 上的设备连接，才能触发 SimulCharge 模式。
3.  **ESP32-S3 端**：ESP32 的 USB D+/D- 直接连接到平板的 D+/D-。ESP32 的供电可以直接取自外部注入的 5V VBUS。
4.  **防反灌保护**：**必须**在平板 VBUS 和外部充电器 VBUS 之间加入隔离。如果不加隔离，当外部电源断开时，平板会试图向外输出 5V（Host 模式默认行为），导致平板电池被外部电路迅速抽干 [4]。

### 2.2 推荐验证拓扑（第一版，已修正）
*   **最小拓扑**：`Tab_A9_VBUS` 直接作为 `SYS_5V` 给 ESP32 供电。`VBUS_IN -> SS34 -> Tab_A9_VBUS/SYS_5V`。无外部电源时，平板 Host 给 ESP32 供电；有外部电源时，外部 5V 通过 SS34 尝试注入同一节点。该拓扑只需要 1 颗 SS34。
*   **完整诊断拓扑**：验证板单独定义一个 `SYS_5V` 轨道给 ESP32 供电。`SYS_5V` 同时支持两种来源：
    *   无外部电源时：`Tab_A9_VBUS -> SS34/理想二极管 -> SYS_5V -> ESP32_5V`，由平板 Host 供电给 ESP32。
    *   有外部电源时：`VBUS_IN -> SS34/理想二极管 -> SYS_5V -> ESP32_5V`，由充电器供电给 ESP32。
*   **平板充电注入路径**：`VBUS_IN -> SS34/限流/eFuse -> Tab_A9_VBUS`，尝试让平板在 Host 模式下接受外部 VBUS。
*   **CC 引脚**：平板侧 CC1/CC2 尝试下拉 5.1kΩ 到 GND（基础 Sink 测试），或预留焊盘以便测试悬空/上拉。
*   **数据线**：ESP32 D+/D- 直连平板 D+/D-（注意 USB 2.0 走线尽量等长）。

## 3. 最小样板验证步骤

在进行 PCB 投板前，必须使用洞洞板或简单的转接板进行验证。

### 3.1 验证准备
*   准备一个 USB-C 母座（接外部电源）、一个 USB-C 公头（接 Tab A9）、一个 ESP32-S3 DevKit。
*   准备万用表、示波器、低压降肖特基二极管（如 SS24）、5.1kΩ 电阻。

### 3.2 测试步骤与测量项
1.  **基础充电测试**：只连接外部 5V 和 CC 下拉电阻到平板，万用表测量平板 VBUS 电压，确认平板是否显示充电。
2.  **数据连通测试**：在步骤 1 基础上，将 ESP32 的 D+/D- 接入，观察 ESP32 是否成功枚举为 HID 设备。
3.  **无外部电源 OTG 测试**：断开外部 5V，确认平板 `Tab_A9_VBUS` 能通过隔离路径拉起 `SYS_5V`，ESP32 能上电并枚举为 HID。
4.  **VBUS 冲突测试（关键）**：断开外部 5V，万用表测量外部充电输入端，确认平板输出的 VBUS 没有反灌到充电器输入。接入外部 5V 后，确认 `SYS_5V` 来源切换不导致 ESP32 掉电。
5.  **枚举中断测试**：在 ESP32 正常工作时，插拔外部 5V 电源，观察 ESP32 的 HID 连接是否会断开重连。

### 3.3 通过/失败标准
*   **通过**：Tab A9 显示充电（即使是慢充），且 ESP32 稳定枚举为 HID 并能发送数据；插拔充电器不导致 ESP32 掉线或仅有短暂可恢复的掉线。
*   **失败**：Tab A9 拒绝充电；或者充电时无法识别 ESP32；或者外部电源断开时，平板反向供电导致系统不稳定。

## 4. Tab A9 兼容性实测证据

针对 Samsung Galaxy Tab A9 (SM-X110) 的 SimulCharge 兼容性，调研结果**非常不乐观**。

1.  **LAVA 官方兼容性列表**：LAVA 是提供 SimulCharge 适配器的权威厂商。在其 Charge-Plus 兼容性列表中，**未列出**基础版 Tab A9 (SM-X110)。列表中仅提到了 Tab A7 Lite、Tab A8 等，且明确指出部分型号（如 Tab A7 Lite SM-T220）存在严重的电流限制 bug（电量不同时拉取的电流不同，甚至低至 0.5A），并建议**不要使用** [5]。
2.  **用户社区反馈**：在三星社区和 Reddit 上，多位用户反馈 Tab A9 和 A9+ 无法在使用普通 USB-C Hub 时同时进行 OTG 和充电。有用户明确表示“连接 USB-C 输入会点亮适配器，Android 显示正在充电，但无法与外设工作” [6]。
3.  **底层限制原因**：LAVA 的技术博客指出，如果移动设备没有实现完整的 USB-C PD 规范（Power Delivery），就无法与适配器协商电源契约，从而无法实现同时供电和数据传输 [7]。Tab A9 作为入门级平板，其 USB-C 接口仅支持 USB 2.0 且大概率**阉割了完整的 PD 角色交换功能**。

## 5. 可采购器件建议 (LCSC/立创商城)

为了控制 BOM 复杂度，建议采购以下基础器件进行验证：

*   **肖特基二极管（防反灌）**：
    *   **SS24** (Slkor / 长电)：2A，40V。价格极低（约 0.05 RMB），适合基础验证，但压降较大（约 0.5V）。
    *   **SS34**：3A 版本，余量更大。
*   **P-MOSFET（替代肖特基，降低压降）**：
    *   **AO3401A** (AOS / 长电)：-4.2A，-30V，SOT-23 封装。常用于简单的 VBUS 开关和防反接电路，导通电阻低 [8]。
*   **ESD 保护**：
    *   **USBLC6-2SC6** (ST / 各种国产替代)：专为 USB 2.0 D+/D- 设计的超低电容 ESD 阵列，SOT23-6 封装。

## 6. 风险清单

*   **平板拒绝充电 / 充电电流不足**：由于缺乏 PD 协商，平板可能只以默认的 500mA 甚至拒绝充电。
*   **枚举中断**：在插拔外部充电器时，VBUS 电压的波动可能导致 ESP32 重新启动或 USB 重新枚举，导致操作中断。
*   **反灌风险**：如果防反灌二极管失效或 P-MOSFET 栅极控制逻辑错误，外部 5V 和平板输出的 5V 发生冲突，可能烧毁平板接口。
*   **CC 配置错误**：错误的电阻值可能导致平板进入错误的模式（如纯供电模式），完全无法识别设备。

## 7. 最终结论与建议

**结论：针对 Tab A9 (SM-X110) 做纯硬件的“半主动”验证小板，风险极高，成功率较低，但考虑到项目成本限制，值得进行一次低成本的“死马当活马医”式验证。**

原因在于，大量证据表明 Tab A9 缺乏完整的 PD 协议支持，三星很可能在固件层面屏蔽了简单的电阻欺骗法。如果基础的下拉/上拉验证失败，则说明该平板**必须**依赖带 PD 芯片的复杂方案（如通过 FUSB302 等芯片进行角色交换协商），这将违背“低复杂度”的初衷。

### 第一版验证板原理图级连接清单：

1.  **VBUS_IN (外部 5V)** 连接到 **Diode_Anode** (肖特基阳极)。
2.  **Diode_Cathode** (肖特基阴极) 连接到 **Tab_A9_VBUS**。
3.  **最小拓扑**：**Tab_A9_VBUS** 直接连接到 **ESP32_5V_IN**，此时 **Tab_A9_VBUS** 同时也是 **SYS_5V**。
4.  **完整诊断拓扑**：**Tab_A9_VBUS** 通过第二路 SS34/理想二极管连接到 **SYS_5V**，保证无外部电源时平板能给 ESP32 供电。
5.  **完整诊断拓扑**：**VBUS_IN** 通过第三路 SS34/理想二极管连接到 **SYS_5V**，保证有外部电源时充电器给 ESP32 供电。
6.  **SYS_5V** 连接到 **ESP32_5V_IN**。
7.  **Tab_A9_CC1** 和 **Tab_A9_CC2** 各接一个 **5.1kΩ** 电阻到 **GND**（预留断开跳线）。
8.  **Tab_A9_D+** 直连 **ESP32_D+**。
9.  **Tab_A9_D-** 直连 **ESP32_D-**。
10.  所有设备的 **GND** 共地。

*建议先用切断 VBUS 线的 USB 数据线配合面包板进行测试，若步骤 3.2 中的测试均失败，则应果断放弃半主动方案，考虑更换平板型号或接受无法边充边用的现实。*

---
### 参考文献
[1] Texas Instruments. A Primer on USB Type-C and Power Delivery Applications.
[2] StackExchange. Can an Android tablet serve as USB Host and be charged simultaneously.
[3] XDA Forums. Guide..OTG USB HOST and CHARGING at same time for Galaxy tabs.
[4] Reddit. USB-C Prevent back powering in Host OTG-Mode.
[5] LAVA Accessory. Charge-Plus Compatibility List.
[6] Samsung Community. Galaxy Tab A9 USB and charging at the same time.
[7] LAVA Blog. Why Some USB-C Mobile Devices Can't Do Simultaneous Power and Data.
[8] LCSC. AO3401A Datasheet and Pricing.

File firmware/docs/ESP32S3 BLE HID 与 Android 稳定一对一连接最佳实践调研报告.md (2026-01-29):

# ESP32S3 BLE HID 与 Android 稳定一对一连接最佳实践调研报告

## 1. NimBLE BLE HID 连接稳定性最佳实践

### 1.1. 问题与挑战

在 ESP32S3 作为 BLE HID 设备与 Android 平板进行一对一固定配对的场景中，实现与物理外接键盘相媲美的连接稳定性是核心挑战。不稳定的连接表现为意外断开，影响用户体验。这主要与 BLE 的连接参数、安全性和广播策略的配置密切相关。

### 1.2. 推荐方案

#### 1.2.1. 连接参数 (Connection Parameters)

连接参数的设置是功耗与延迟之间的权衡。对于 HID 设备，低延迟通常是首要考虑的因素。根据 TI 工程师的建议和 Apple 的《Accessory Design Guidelines》，对于键盘等 HID 设备，推荐使用较短的连接间隔以保证响应速度 [1] [2]。

**推荐参数组合：**

| 参数 | 推荐值 | 单位 | 说明 |
| --- | --- | --- | --- |
| **Connection Interval (Min)** | 11.25 | ms | 对应 GAP 配置中的 `8` (8 * 1.25ms = 10ms)，或 `9` (9 * 1.25ms = 11.25ms)。 |
| **Connection Interval (Max)** | 15 | ms | 对应 GAP 配置中的 `12` (12 * 1.25ms = 15ms)。 |
| **Peripheral Latency (Slave Latency)** | 0 | - | 对于需要低延迟的键盘操作，建议设置为 0。在低频输入场景下，可以适当增加以降低功耗，但需要充分测试。 |
| **Supervision Timeout** | 5000 | ms | 对应 GAP 配置中的 `500` (500 * 10ms = 5s)。这是用户在初始配置中已设置的值，是一个合理的范围。 |

> **注意**：Android 和 iOS 对连接参数有自己的限制。虽然外设可以请求更新连接参数，但最终决定权在 Central（Android 平板）。iOS 设备在连接到 HID 服务时，可能会接受低至 11.25ms 的连接间隔 [2]。Android 的行为可能因制造商和系统版本而异，需要进行实际测试。

#### 1.2.2. Bonding 与 Security 配置

为了实现固定配对和断线后的快速重连，必须正确配置 Bonding（绑定）和安全性。

- **启用 Bonding**：在 `menuconfig` 中启用 NimBLE 的持久化绑定功能。这会将绑定信息（如加密密钥）存储在 NVS (非易失性存储) 中，使设备在重启后仍能识别已配对的 Android 平板 [3]。
- **安全模式与级别**：对于 HID 设备，建议使用 `LESC (Secure Connections)` 配对，因为它提供了更强的安全性。初始配置中的 `SM_LEGACY + SM_SC` 是一个兼容性较好的选择。
- **I/O 能力**：根据您的设备是否有显示屏或键盘，设置合适的 I/O 能力 (IO Capabilities)。对于一个没有显示和输入的旋钮设备，可以设置为 `NoInputNoOutput`。

#### 1.2.3. 广播参数 (Advertising Parameters)

广播参数影响设备被发现的速度和功耗。

- **广播间隔 (Advertising Interval)**：在未连接状态下，为了让 Android 平板能快速发现设备，可以设置一个较短的广播间隔，例如 100ms。一旦连接建立，应立即停止广播，以节省功耗并防止其他设备尝试连接。
- **定向广播 (Directed Advertising)**：在与已知设备（已绑定）断开连接后，应使用定向广播来快速重连。这会直接向已知的 Android 平板的 MAC 地址发送广播，而不是公开广播。这不仅速度更快，功耗更低，也更安全。

### 1.3. 代码片段或配置示例

**menuconfig 配置:**

在 `Component config -> Bluetooth -> NimBLE Options` 中进行以下配置：

```
[*] NimBLE Host enabled
    (1)   Max Connections
[*]   Enable bonding
[*]   Store bonding information in NVS
```

**连接参数更新请求 (示例):**

```c
// 定义期望的连接参数
static const struct ble_gap_conn_params conn_params = {
    .min_conn_interval = 8,    // 10ms
    .max_conn_interval = 12,   // 15ms
    .slave_latency = 0,
    .supervision_timeout = 500 // 5s
};

// 在连接建立后发起更新请求
ble_gap_update_params(conn_handle, &conn_params);
```

---
## 2. Android 端 BLE HID 的已知问题与规避方法

### 2.1. 问题与挑战

Android 系统的开放性导致其在不同品牌、不同版本的设备上对 BLE 的处理存在差异，这给追求稳定连接带来了挑战。主要的挑战包括：

- **系统兼容性**：不同 Android 版本和手机制造商的 ROM 对 BLE 协议栈的实现和限制不同，可能导致连接参数协商失败或连接不稳定。
- **电源管理策略**：Android 的省电模式（Doze Mode）和应用待机（App Standby）等机制可能会限制后台应用的蓝牙扫描和连接，甚至在屏幕关闭后中断 BLE 连接以节省电量。
- **HID 报告描述符**：不规范或过于复杂的 HID Report Descriptor 可能会被某些 Android 系统拒绝或解析错误。

### 2.2. 推荐方案

#### 2.2.1. 应对兼容性差异

- **遵循标准**：严格遵循 Bluetooth SIG 定义的 HID over GATT Profile (HOGP) 规范。这是保证最大兼容性的基础。
- **连接参数的灵活性**：虽然我们推荐了理想的连接参数，但应用层代码应能处理来自 Android 主机的连接参数更新请求，并接受一个合理的范围，而不是固执地要求一个特定值。
- **充分测试**：在目标 Android 平板上进行详尽的测试是不可或缺的。如果可能，也在其他不同品牌和版本的 Android 设备上进行测试，以了解兼容性范围。

#### 2.2.2. 规避电源管理问题

- **前台服务**：如果您的应用需要在后台保持连接，可以考虑在 Android 应用端实现一个前台服务 (Foreground Service)。这会提高应用的优先级，使其不容易被系统杀死，并减少蓝牙连接被中断的可能性。但这需要修改 Android 端的代码。
- **用户引导**：在 Android 应用中，可以引导用户将您的应用和蓝牙服务加入系统的“电池优化”白名单。这需要用户手动操作，但可以有效防止系统为了省电而断开连接。
- **保持连接活跃**：即使没有用户输入，也可以通过定期发送“心跳包”（例如，一个空的 HID 报告）来模拟设备活跃状态，但这会增加功耗。

#### 2.2.3. HID Report Descriptor 配置

- **保持简洁**：对于旋钮和按钮这样的简单输入设备，HID Report Descriptor 应尽可能简洁。只包含必要的 Usage Page (e.g., Generic Desktop) 和 Usage (e.g., Keyboard, Mouse, Consumer Control)。
- **遵循规范**：确保 Report Descriptor 的格式严格符合 USB HID Specification。任何微小的错误都可能导致 Android 主机拒绝连接。
- **参考成熟项目**：可以参考一些广泛使用的开源 BLE HID 项目的 Report Descriptor，例如 `olegos76/nimble_kbdhid_example` [4] 或 ESP-IDF 官方的 `ble_hid_device_demo` [5]。

### 2.3. 代码片段或配置示例

**一个精简的键盘 HID Report Descriptor 示例：**

```c
static const uint8_t hid_report_map[] = {
    0x05, 0x01, // Usage Page (Generic Desktop)
    0x09, 0x06, // Usage (Keyboard)
    0xA1, 0x01, // Collection (Application)
    0x85, 0x01, // Report ID (1)
    // ... (Modifier keys, keycodes, etc.)
    0xC0        // End Collection
};
```

> **注意**：上述描述符是一个高度简化的示例。实际的键盘描述符需要包含 Modifier (like Ctrl, Shift), Reserved byte, 和多个 Keycode 的定义。关键在于避免包含非标准或设备用不到的复杂定义。

---
## 3. 断线重连机制

### 3.1. 问题与挑战

实现快速、可靠的自动重连是保证“像物理键盘一样稳定”体验的关键。当连接因信号弱、超出范围或 Android 端进入休眠而意外断开时，设备需要能够自动恢复连接，而无需用户手动干预。挑战在于如何区分是需要重新配对（re-pairing）还是仅需重连（reconnection），以及如何高效地利用 BLE 协议栈的特性来实现这一目标。

### 3.2. 推荐方案

#### 3.2.1. 持久化 Bonding 信息

这是实现自动重连的基础。如前所述，必须在 `menuconfig` 中启用 NimBLE 的绑定信息持久化功能。这会将配对过程中交换的密钥（如 LTK）存储在 ESP32S3 的 NVS 闪存中。当 Android 平板（主机）尝试重连时，设备可以使用存储的密钥来恢复加密会话，而无需再次进行配对流程。

#### 3.2.2. 定向广播 (Directed Advertising)

当与一个已绑定的主机断开连接后，最有效的重连方式是使用定向广播。

- **工作原理**：定向广播是一种特殊的广播模式，它将广播包直接发送到特定主机的蓝牙地址。这使得主机可以立即识别并响应，从而快速重建连接。
- **优点**：相比于通用的、可连接的非定向广播，定向广播功耗更低、重连速度更快，并且由于不是公开广播，安全性也更高。
- **实现**：在 NimBLE 中，当发生断连事件时，可以检查断连的原因以及对方设备是否是已绑定的设备。如果是，则可以启动定向广播。通常，会先进行一小段时间（例如，几十秒）的高占空比定向广播，如果仍未连接成功，再转为较慢的非定向广播，以允许用户在需要时从其他设备连接或重新配-对。

#### 3.2.3. Reconnection 与 Re-pairing 的处理

- **Reconnection (重连)**：这是理想情况。当 ESP32S3 和 Android 平板都存有对方的绑定信息时，任何一方都可以发起连接请求，并使用已有的密钥恢复安全连接。您的固件逻辑应该总是优先尝试这种方式。
- **Re-pairing (重新配对)**：当一方的绑定信息丢失时（例如，用户在 Android 的蓝牙设置中“忘记”了该设备），重连会失败（通常是因为加密验证失败）。在这种情况下，设备需要能够处理这种失败，并回退到允许重新配对的状态。这通常意味着：
    1.  删除 ESP32S3 上存储的旧的绑定信息。
    2.  重新开始通用的、可发现的广播，等待新的配对请求。

### 3.3. 代码片段或配置示例

**断连事件处理逻辑 (伪代码):**

```c
void on_disconnect(uint16_t conn_handle, int reason) {
    printf("Disconnected; reason=%d\n", reason);

    // 检查是否是已绑定的设备
    ble_addr_t peer_addr = get_peer_address(conn_handle);
    if (is_bonded(peer_addr)) {
        // 尝试使用定向广播进行快速重连
        start_directed_advertising(peer_addr);
    } else {
        // 如果不是绑定设备，或者定向广播失败后，回退到通用广播
        start_general_advertising();
    }
}

void on_security_failure(uint16_t conn_handle, int reason) {
    // 如果安全验证失败（可能是对方删除了绑定信息）
    // 删除本地的绑定信息，并准备重新配对
    ble_addr_t peer_addr = get_peer_address(conn_handle);
    delete_bonding_info(peer_addr);
    start_general_advertising();
}
```

> **注意**：上述代码是逻辑示意。在 NimBLE 中，您需要在 `ble_gap_event_listener` 中处理 `BLE_GAP_EVENT_CONNECT` 和 `BLE_GAP_EVENT_DISCONNECT` 事件，并调用 `ble_gap_adv_start()` 函数，通过设置 `struct ble_gap_adv_params` 中的 `conn_mode` 和 `filter_policy` 来实现不同类型的广播。

---
## 4. 调试与诊断

### 4.1. 问题与挑战

当连接意外断开时，快速定位问题根源是至关重要的。断连可能是由 ESP32S3 侧、Android 侧或外部环境因素引起的。有效的调试手段可以帮助我们区分这些情况，并找到具体的错误原因。

### 4.2. 推荐方案

#### 4.2.1. 理解断连原因码 (Disconnect Reason Codes)

当 BLE 连接断开时，协议栈会提供一个原因码。这是最直接的调试信息。在 NimBLE 的断连事件回调中，可以获取到这个 `reason` 码。

**常见原因码及其含义 [6] [7]：**

| 原因码 (Hex) | 宏定义 (示例) | 含义 | 可能的原因 |
| --- | --- | --- | --- |
| `0x08` | `BLE_ERR_CONN_TMO` | 连接超时 | 信号弱、干扰、一方设备无响应（死机或进入无法唤醒的休眠）。 |
| `0x13` | `BLE_ERR_REM_USER_CONN_TERM` | 远程用户终止连接 | Android 端主动断开连接（例如，用户在设置中手动断开，或应用调用了断开 API）。 |
| `0x16` | `BLE_ERR_CONN_TERM_LOCAL` | 本地主机终止连接 | ESP32S3 侧主动断开连接。 |
| `0x3E` | `BLE_ERR_CONN_FAIL_ESTABLISH` | 连接建立失败 | 在连接建立过程中，多次尝试后仍无法与对方同步。 |
| `0x05` | `BLE_ERR_AUTH_FAIL` | 认证失败 | 配对或加密过程失败，可能是密钥错误或一方丢失绑定信息。 |

> **特别注意**：您在问题描述中提到的 `BLE_ERR_CONN_SPVN_TMO` (Supervision Timeout) 对应于 `0x08` 连接超时。这是最常见的非主动断连原因，通常指向信号质量问题或一方设备未能及时响应。

#### 4.2.2. 判断断开方

- **`0x13` (Remote User Terminated)**：明确表示是 **Android 侧**主动断开。
- **`0x16` (Local Host Terminated)**：明确表示是 **ESP32 侧**主动断开。
- **`0x08` (Timeout)**：不确定是哪一方的问题。可能是 ESP32 信号太弱，Android 没收到；也可能是 Android 进入深度休眠，没有发送数据，导致 ESP32 超时。需要结合其他信息进一步分析。

#### 4.2.3. 日志级别和调试手段

- **提高日志级别**：在 `menuconfig` 中，将 NimBLE 和 Bluetooth Controller 的日志级别调整为 `Debug` 或 `Verbose`。这将输出详细的协议栈内部状态信息，有助于分析问题。
- **使用 BLE Sniffer**：这是最强大的调试工具。通过一个第三方的 BLE 嗅探器（例如，Nordic 的 nRF Sniffer for Bluetooth LE），可以捕获空中的所有 BLE 数据包。通过分析 sniffer 日志，可以清晰地看到连接参数协商过程、数据交换、以及谁发送了 `LL_TERMINATE_IND` 包，从而无可辩驳地确定问题根源。
- **功耗分析仪**：对于怀疑与休眠相关的问题，使用功耗分析仪可以观察设备在不同状态下的电流消耗，判断设备是否按预期进入或退出了 Light-sleep 模式。
- **禁用 Tickless Idle**：您在初始配置中已经禁用了 `tickless idle`，这是一个正确的调试步骤。因为不当的休眠配置确实是导致 BLE 断连的常见原因。在问题解决之前，保持禁用状态，可以排除休眠带来的不确定性。

---
## 5. 参考实现

### 5.1. 问题与挑战

从零开始实现一个稳定可靠的 BLE HID 设备是复杂的。参考成熟的开源项目和官方讨论可以大大加快开发进程，并避免重复造轮子。挑战在于找到与当前技术栈（ESP32S3 + NimBLE）高度相关且质量优良的参考实现。

### 5.2. 推荐方案

#### 5.2.1. 开源参考项目

在调研过程中，发现以下项目具有较高的参考价值：

- **olegos76/nimble_kbdhid_example** [4]
  - **简介**：这是一个专门为 ESP32 和 NimBLE 栈设计的 BLE HID 键盘和鼠标的示例项目。代码结构清晰，是本次调研任务最直接、最相关的参考实现。
  - **优点**：
    - **专注于 NimBLE**：与 Bluedroid 栈的官方示例相比，它更轻量，启动更快，镜像更小。
    - **功能完整**：实现了 GATT 服务器、广播、连接、GPIO 按键输入、以及发送键盘/鼠标报告的功能。
    - **文档清晰**：作者详细说明了使用 NimBLE 相对于 Bluedroid 的优势，并列出了所参考的蓝牙官方文档，非常适合学习。
  - **建议**：强烈建议将此项目作为您开发的基础框架。仔细研究其服务定义、广播和安全配置。

- **ESP-IDF 官方示例 `ble_hid_device_demo`** [5]
  - **简介**：这是 Espressif 官方提供的 BLE HID 设备示例，位于 ESP-IDF 的 `examples/bluetooth/bluedroid/ble/ble_hid_device_demo` 目录下。
  - **优点**：
    - **官方维护**：代码质量和稳定性有基本保证。
    - **功能全面**：实现了鼠标、键盘和消费类控制设备（如音量键）的复合 HID 设备。
  - **缺点**：
    - **基于 Bluedroid**：与您选择的 NimBLE 技术栈不同。Bluedroid 功能更全面（支持经典蓝牙），但也更臃肿。其 API 和配置方式与 NimBLE 有较大差异。
  - **建议**：可以将其作为 HID Report Descriptor 和服务定义的参考，但不要直接照搬其代码逻辑，因为协议栈不同。

#### 5.2.2. 社区与官方讨论

- **Espressif GitHub Issues & ESP32.com 论坛**：
  - 这些是获取最新信息和解决疑难杂症的重要渠道。例如，关于特定版本 ESP-IDF 中 NimBLE 的 bug、WiFi 与 BLE 共存的稳定性问题、以及特定硬件（如 ESP32-S3）的兼容性问题，通常可以在这些地方找到有价值的讨论。
  - 在搜索时，使用具体的错误码（如 `BLE_ERR_CONN_SPVN_TMO`）、函数名和芯片型号作为关键词，可以更精确地找到相关信息。

- **Punchthrough, Argenox 等专业博客**：
  - 这些公司专注于蓝牙技术，其博客文章（如本次报告引用的 [1] 和 [6]）提供了超越官方文档的深度见解和最佳实践总结，非常值得阅读。

---

## 6. 参考文献

[1] Punchthrough. (2022). *The Ultimate Guide To Managing Your BLE Connection*. [https://punchthrough.com/manage-ble-connection/](https://punchthrough.com/manage-ble-connection/)

[2] Apple Developer. (2017). *Accessory Design Guidelines for Apple Devices*. [https://developer.apple.com/accessories/Accessory-Design-Guidelines.pdf](https://developer.apple.com/accessories/Accessory-Design-Guidelines.pdf)

[3] Espressif Systems. (n.d.). *ESP-IDF Programming Guide: NimBLE Options*. [https://docs.espressif.com/projects/esp-idf/en/latest/esp32/api-reference/kconfig.html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](https://docs.espressif.com/projects/esp-idf/en/latest/esp32/api-reference/kconfig.html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)

[4] olegos76. (n.d.). *nimble_kbdhid_example*. GitHub. [https://github.com/olegos76/nimble_kbdhid_example](https://github.com/olegos76/nimble_kbdhid_example)

[5] Espressif Systems. (n.d.). *ESP-IDF BLE HID Device Demo*. GitHub. [https://github.com/espressif/esp-idf/tree/master/examples/bluetooth/bluedroid/ble/ble_hid_device_demo](https://github.com/espressif/esp-idf/tree/master/examples/bluetooth/bluedroid/ble/ble_hid_device_demo)

[6] Argenox. (2020). *Understanding BLE Disconnections*. [https://argenox.com/blog/understanding-ble-disconnections/](https://argenox.com/blog/understanding-ble-disconnections/)

[7] Bluetooth SIG. (2021). *Core Specification Supplement, Part D, Error Codes*. [https://www.bluetooth.com/specifications/specs/core-specification-5-3/](https://www.bluetooth.com/specifications/specs/core-specification-5-3/)

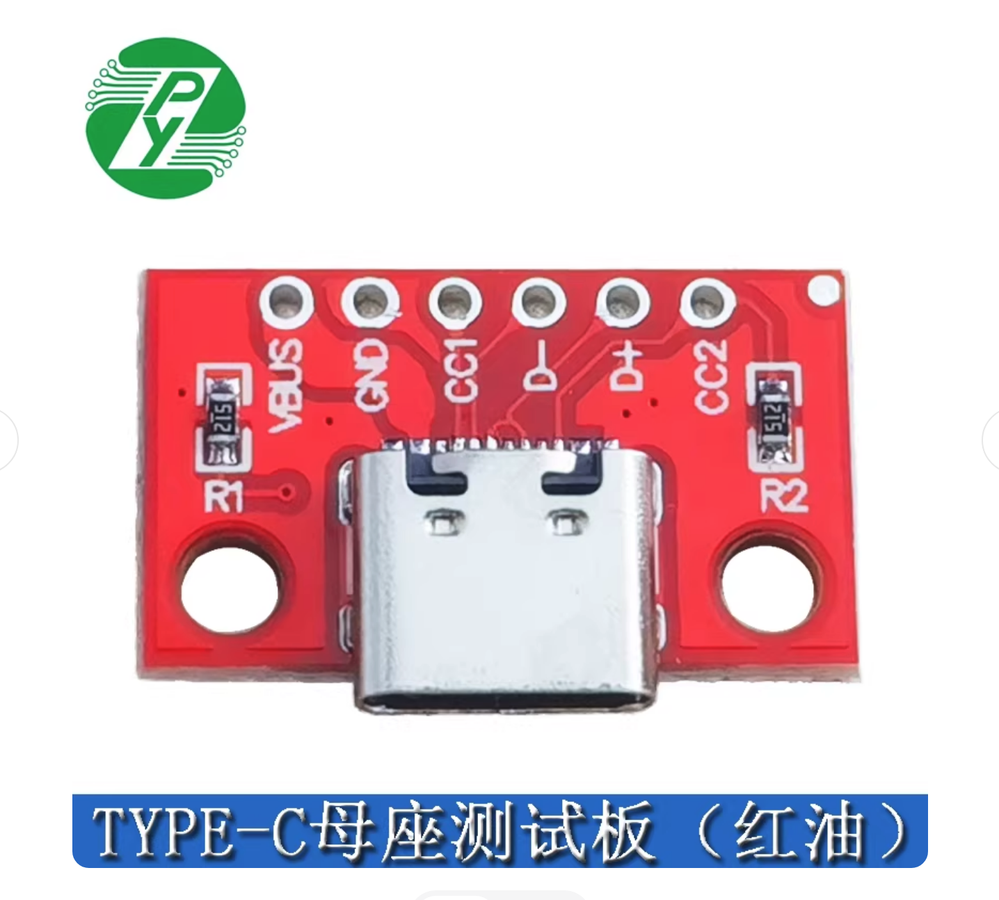
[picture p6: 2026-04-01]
docs/assets/usb-c-breakout-6p-pinout.png

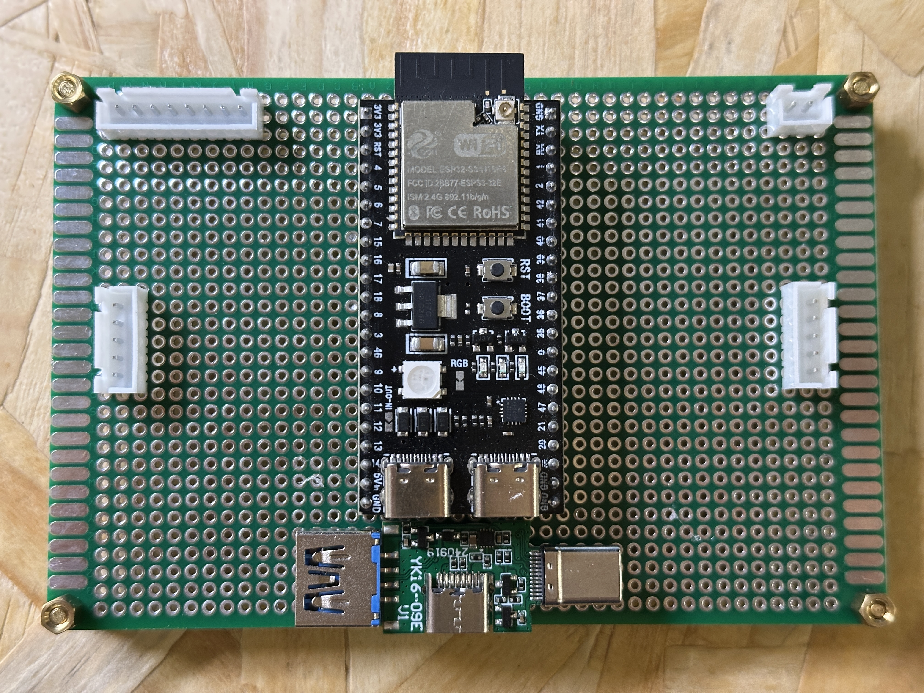
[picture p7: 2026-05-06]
docs/assets/v4-handmade-prototype-2026-05-06.jpg

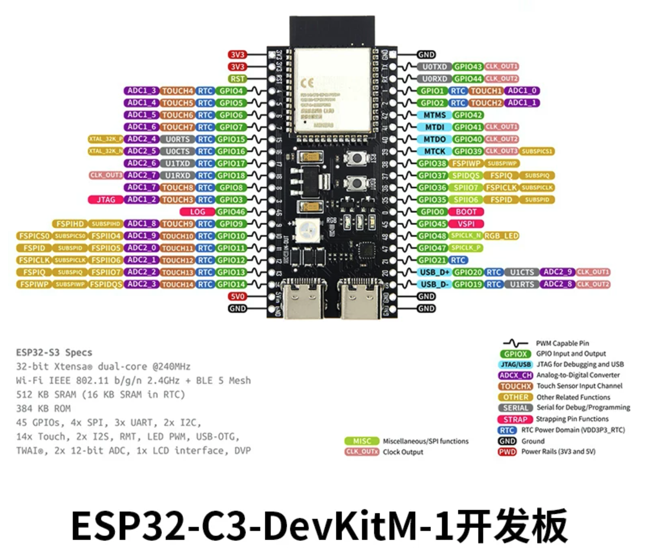
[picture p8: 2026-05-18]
pcb/asset/ESP32-S3-DevKitC-N16R8.png

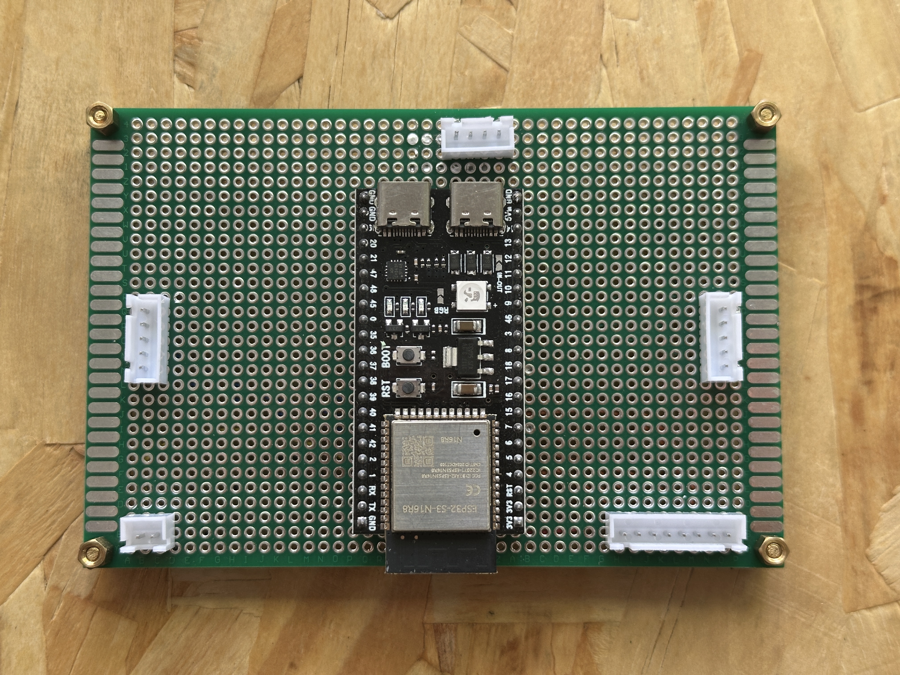
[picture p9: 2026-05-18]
pcb/asset/飞线测试版本-顶视图-接口布局.JPG

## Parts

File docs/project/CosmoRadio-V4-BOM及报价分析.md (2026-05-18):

# CosmoRadio V4 — BOM 及报价分析

> 制作日期：2026-03-31 | 报价会议：2026-04-01 下午
> 主要采购渠道：**zave 旗舰店 (天猫)**、凯华官方天猫、淘宝散件、JLCPCB（PCB）
> 原交付：4 套完整设备 + 8 套电子元件套件（2026-04-02 已取消）
> 当前交付：技术方案验证 + 单套原型制作（2026-04-29 与 Arthur 重启，合同价 ¥5,000）
> 价格核实：2026-03-31 晚实时查价

---

## 一、原批量交付范围（已取消）

> 以下 12 套采购和成本模型保留为批量方案参考。2026-04-29 重启后，当前执行范围为技术方案验证 + 单套原型制作，需按单套原型重新核算材料和打样成本。

| 类型 | 数量 | 包含内容 |
| --- | --- | --- |
| 完整设备 | 4 套 | 3D 打印外壳（3 件模块化） + 控制器 + NFC + 全部线材（不含平板，客户自购） |
| 电子套件 | 8 套 | 控制器 + NFC + 旋钮 + 按钮 + 线材 + 螺丝包（客户自行打印外壳、组装） |
| **合计生产** | **12 套电子件** | 4 套含外壳，8 套不含 |

---

## 二A、V4 单套原型 BOM (Plan v2, 2026-05-18)

> 当前生效的 BOM，对应 2026-04-29 重启后的"单套原型"范围。下方"二、单套 BOM"是 2026-04-01 出稿的批量方案 BOM，保留作为历史参考。

### PCB 载板（V4 PCB Plan v2）

| 序号 | 元件 | 规格 / 封装 | 数量 | 单价 (¥) | 小计 (¥) | 备注 |
|---|---|---|---|---|---|---|
| PCB-1 | PCB 打样 | 100×100mm 2L 1.6mm 黑油白字 HASL | 5 片 | 0 | 0 | JLCPCB 免费打样 + 国内运费 ~¥20 |
| PCB-2 | 1×22P 排母 2.54mm | THT 立式 | 2 | 1.20 | 2.40 | DevKitC 插座 (U1A/U1B) |
| PCB-3 | XH2.54 5P 立式插座 | THT | 2 | 0.40 | 0.80 | J1 EC11-L, J2 EC11-R |
| PCB-4 | XH2.54 2P 立式插座 | THT | 1 | 0.20 | 0.20 | J3 Action Button |
| PCB-5 | XH2.54 8P 立式插座 | THT | 1 | 0.60 | 0.60 | J4 NFC |
| PCB-6 | XH2.54 4P 立式插座 | THT | 1 | 0.30 | 0.30 | J5 OTG USB 数据 |
| PCB-7 | 10kΩ 电阻 | 0805 SMD, LCSC C17414 | 4 | 0.02 | 0.08 | EC11 A/B 上拉 (R1-R4) |
| PCB-8 | 10nF 电容 | 0805 X7R 50V | 4 | 0.05 | 0.20 | EC11 A/B RC 去抖 (C1-C4) |
| **PCB 小计** | | | **14 件** | | **¥4.58** | + 运费 ¥20 = **~¥25** |

### 外购功能模块（与 V3 / 旧 V4 一致）

| 序号 | 元件 | 规格 | 数量 | 单价 (¥) | 小计 (¥) | 来源 |
|---|---|---|---|---|---|---|
| M-1 | ESP32-S3 DevKitC N16R8 | 16MB QIO Flash + 8MB Octal PSRAM, Type-C, 已焊针 | 1 | 32.75 | 32.75 | zave 天猫 |
| M-2 | EC11 旋转编码器 15mm 半轴柄 | 5 只/包 (买 1 包) | 2 (用) | 11.57/5 ≈ 2.31 | 4.63 | zave |
| M-3 | Kailh BOX 轴体 | 5 只/包 | 1 | 12.75/5 ≈ 2.55 | 2.55 | zave |
| M-4 | KEYCOOL 卫星轴 6.25U | 含轴座 + 钢丝 | 1 | 10.80 | 10.80 | 熊猫外设 |
| M-5 | RC522 mini NFC 模块 | 黑色 SPI | 1 | 9.94 | 9.94 | zave |
| M-6 | OTG dongle YK16-09E V1 | 一分二 OTG + 充电 | 1 | ~25 | 25.00 | 已采购验证 |
| M-7 | M2.5×10 平头内六角螺丝 | 不锈钢 | 4 | 0.05 | 0.20 | 固万基 |
| M-8 | M2.5 热熔铜螺母 | M2.5×5×3.5 | 4 | 0.10 | 0.40 | 固万基 |
| **模块小计** | | | | | **~¥86** | |

### 配套线缆（预压 / 预焊）

| 序号 | 线缆 | 规格 | 数量 | 单价 (¥) | 小计 (¥) | 备注 |
|---|---|---|---|---|---|---|
| W-1 | XH2.54 5P 端子线 | 公头 20cm | 2 | 0.47 | 0.94 | J1/J2 to EC11 |
| W-2 | XH2.54 2P 端子线 | 公头 25cm | 1 | 0.30 | 0.30 | J3 to BTN |
| W-3 | XH2.54 8P 端子线 | 公头 15cm | 1 | 1.19 | 1.19 | J4 to NFC |
| W-4 | XH2.54 4P 端子线 + AWG28 飞线 | 公头 <10cm | 1 | 0.40 | 0.40 | J5 to dongle (拆解后焊接) |
| **线缆小计** | | | | | **~¥2.83** | |

### V4 单套原型总成本

| 分类 | 成本 (¥) | 占比 |
|---|---|---|
| PCB（含 SMD 被动件 + 插座 + 打板 + 运费）| ~¥25 | 19% |
| 外购功能模块（主控 + EC11 + 按钮 + NFC + dongle + 螺丝）| ~¥86 | 65% |
| 配套线缆 | ~¥3 | 2% |
| 3D 打印外壳（Arthur 寄来 + 微调）| ~¥20 | 15% |
| **单套合计** | **~¥134** | 100% |

> vs 旧批量方案单套 ¥79：单套原型贵在 PCB 打板分摊（5 片打样而只用 1 片）+ OTG dongle 整件成本。批量化后单套可降至 ~¥80-90。

### 取消的元件（vs 2026-04-01 批量 BOM）

| 元件 | 原数量 | 取消原因 |
|---|---|---|
| USB-C 大电流 DIP 转接板 6P | 28 | 主 PCB 不上 USB-C；OTG dongle 接管充电 |
| 0805 5.1KΩ 贴片电阻 (CC 配置)| 1 包 (100 只)| 取消 USB-C 母座 → 无 CC 引脚需配 |
| 5.1KΩ 1/6W 直插电阻 | 1 包 | 同上 |
| SS34 肖特基二极管 | 2 包 (20 只)| 取消 VBUS 注入方案 |
| WS2812B 5050 RGB LED | 15 | 用 DevKitC GPIO48 板载 RGB |
| XH2.54 插座 3P | 1 包 | 原为 LED 连接，取消 |
| XH2.54 端子线 3P | 2 包 | 同上 |

---

## 二、单套 BOM（V4 USB HID + NFC）— 旧批量方案（2026-04-01 出稿，已被二A 取代）

### V3 → V4 变化对比

| 组件  | V3 | V4 | 变化原因 |
| --- | --- | --- | --- |
| 主控  | ESP32-S3 SuperMini ¥20.68 | ESP32-S3 DevKitC N16R8 ¥32.75 | SuperMini 仅 11 GPIO，NFC SPI 需 5 pin，总需 14+ pin |
| 按钮  | 轻触按键 12×12 ¥0.15 | Kailh BOX 轴 + 6.25U 卫星轴 ~¥12  | 蝴蝶结构，≥3mm 行程，稳定不卡 |
| NFC | 无 | RC522 mini 模块 ¥9.94 | 新增功能，读 NTAG213 UID |
| PCB | 万能板 ¥0.65 | 定制 PCB (JLCPCB) ~¥3/片 | 消灭飞线，XH2.54 即插即用 |
| 连接器 | 焊接直连 | XH2.54 插座 + 端子线 ~¥6 | 模块化，零焊接组装 |
| 螺丝  | M2 少量 | M2.5 × 8 颗 + 热熔螺母 ~¥1 | 4 螺丝固定，结构加强 |
| USB | 无 | PCB 双 USB-C 座 + VBUS 注入 ~¥9 | 板载充电+数据分流，替代 FPC+一分二（[方案](../hardware/usb.md)） |
| 外壳  | 一体两件式 ~300g | 模块化三件式 ~350g | 主体 + 顶部 + 背板 |

> **芯片选型结论**：
>
> - 只有 ESP32-S2 和 S3 支持 USB OTG (TinyUSB HID)，C3/C6/H2 的 USB 是 Serial/JTAG 硬件锁定，**不可用于 HID**
> - ESP32-S3 SuperMini (¥20.68) 仅 11 GPIO，V4 新增 NFC SPI (5 pin) 后总需 14+ pin，**GPIO 不够**
> - ESP32-S3 DevKitC N16R8 (¥32.75 zave) 36+ GPIO，满足所有外设 + 未来扩展
> - 备选供应商：深圳优信电子 (淘宝)，SuperMini 系列更便宜，可作为备件来源

### 采购清单（批量采购）

> 按实际采购批次统计，非单套拆分。数据更新：2026-03-31

#### 主控

| # | 组件 | 规格 | 采购量 | 单价 (¥) | 小计 (¥) | 备注 |
| --- | --- | --- | --- | --- | --- | --- |
| 1 | ESP32-S3 DevKitC N16R8 | Type-C 接口，已焊针 | 12  | 32.75  | 393.00 | 单个售卖，需 12 只 [[A1]] |

#### 旋钮 / 编码器

| # | 组件 | 规格 | 采购量 | 单价 (¥) | 小计 (¥) | 备注 |
| --- | --- | --- | --- | --- | --- | --- |
| 2 | EC11 旋转编码器 | 15mm 半轴柄，5 只/包 | 5 包 | 11.57  | 57.85  | 共 25 只，需 24 只 (12 套 × 2) [[A2]] |

#### 按钮 / 轴体

| # | 组件 | 规格 | 采购量 | 单价 (¥) | 小计 (¥) | 备注 |
| --- | --- | --- | --- | --- | --- | --- |
| 3 | Kailh BOX 轴体 | 白轴 5 + 红轴 5/包，3.6mm 行程 | 2 包 | 12.75  | 25.50  | 共 20 只，需 12 只 [[A3]] |
| 4 | KEYCOOL 卫星轴 6.25U | 钢板卫星轴，含轴座 + 10.5cm 钢丝  | 12  | 10.80  | 129.60 | 单个售卖，需 12 只 [[A4]] |

#### NFC / LED

| # | 组件 | 规格 | 采购量 | 单价 (¥) | 小计 (¥) | 备注 |
| --- | --- | --- | --- | --- | --- | --- |
| 5 | RC522 mini NFC 模块 | 黑色，国产有字芯片，SPI 接口 | 15  | 9.94 | 149.10 | 单个售卖，需 12 只 + 3 备件 [[A5]] |
| 6 | WS2812B 5050 RGB LED | 1 位方形板 | 15  | 2.21 | 33.15  | 单个售卖，需 12 只 + 3 备件 [[A6]] |

#### 连接器 — 排母座

| # | 组件 | 规格 | 采购量 | 单价 (¥) | 小计 (¥) | 备注 |
| --- | --- | --- | --- | --- | --- | --- |
| 7 | 22P 单排母座 2.54mm | 10 只/包 | 3 包 | 3.56 | 10.68  | 共 30 只，需 24 只 (12 套 × 2) [[A7]] |

#### 连接器 — XH2.54 插座（板载）

| # | 组件 | 规格 | 采购量 | 单价 (¥) | 小计 (¥) | 备注 |
| --- | --- | --- | --- | --- | --- | --- |
| 8 | XH2.54 插座 5P | 直针，50 个/包 | 1 包 | 3.04 | 3.04 | 接 EC11 旋钮 × 2，需 24 个 [[A8]] |
| 9 | XH2.54 插座 3P | 直针，50 个/包 | 1 包 | 3.26 | 3.26 | 接 WS2812 LED，需 12 个 [[A8]]  |
| 10  | XH2.54 插座 8P | 直针，50 个/包 | 1 包 | 3.76 | 3.76 | 接 RC522 NFC，需 12 个 [[A8]] |
| 11  | XH2.54 插座 2P | 直针，50 个/包 | 1 包 | 2.16 | 2.16 | 接 Kailh 轴体，需 12 个 [[A8]] |

#### 连接器 — XH2.54 端子线

| # | 组件 | 规格 | 采购量 | 单价 (¥) | 小计 (¥) | 备注 |
| --- | --- | --- | --- | --- | --- | --- |
| 12  | XH2.54 端子线 5P | 公头 20cm，10 条/包 | 3 包 | 4.66 | 13.98  | 接 EC11 旋钮，需 24 条 [[A9]] |
| 13  | XH2.54 端子线 3P | 公头 15cm，10 条/包 | 2 包 | 3.56 | 7.12 | 接 WS2812 LED，需 12 条 [[A9]] |
| 14  | XH2.54 端子线 8P | 公头 20cm，5 条/包  | 3 包 | 5.97 | 17.91  | 接 RC522 NFC，需 12 条 [[A9]]  |
| 15  | XH2.54 端子线 2P | 公头 15cm，10 条/包 | 2 包 | 2.74 | 5.48 | 接 Kailh 轴体，需 12 条 [[A9]] |

#### USB 集成（替代原 FPC + 一分二方案）

> 方案 B：PCB 板载双 USB-C 座 + VBUS 被动注入，详见 [docs/usb.md](../hardware/usb.md)

| # | 组件 | 规格 | 采购量  | 单价 (¥) | 小计 (¥) | 备注 |
| --- | --- | --- | ---- | --- | --- | --- |
| 16  | USB-C 大电流 DIP 转接板 6P | CC1/CC2/D+/D-/VBUS/GND | 28 个 | 1.00 | 28.00  | J5+J6 各 1/套，需 24 + 4 验证备件 [[A10]] |
| 17  | 0805 5.1KΩ 贴片电阻 1% | 100 只/包 | 1 包  | 2.92 | 2.92 | CC 引脚配置，4 只/套，需 48 只 [[A11]] |
| 18  | 5.1KΩ 1/6W 直插金属膜电阻 | 100 只/包 | 1 包  | 2.46 | 2.46 | 面包板原型验证用 [[A12]] |
| 19  | SS34 肖特基二极管 | 贴片 SMA，10 只/包 | 2 包  | 2.05 | 4.10 | VBUS 防倒灌，需 12 + 备件 [[A13]] |

#### 五金 / PCB

| # | 组件 | 规格 | 采购量 | 单价 (¥) | 小计 (¥) | 备注 |
| --- | --- | --- | --- | --- | --- | --- |
| 20  | M2.5 不锈钢超薄头内六角螺丝 | M2.5 × 8mm，200 个/包 | 1 包 | 9.60 | 9.60 | 需 96 个 (12 套 × 8)，余量充足 [[A14]] |
| 21  | M2.5 热熔铜螺母 | M2.5 × 5 × 3.5，50 个/包 | 1 包 | 4.90 | 4.90 | 仅完整设备需要 (4 套 × 8 = 32 个) [[A15]] |
| 22  | PCB 定制载板 | 80 × 50mm 双面，15 片 | 1 批 | 3.00/片 | 45.00  | JLCPCB 含运费，待 KiCad 设计完成后下单 [[A16]] |

---

> **采购总计：¥953**（原 ¥1,609，USB 集成方案节省 ¥656）

#### 链接索引

| 编号  | 店铺 | 链接 |
| --- | --- | --- |
| A1  | ++**[zave旗舰店](https://zave.tmall.com/)**++ | [ESP32-S3 DevKitC N16R8](https://detail.tmall.com/item.htm?id=887690740161&skuId=5749012884645) |
| A2  | ++**[zave旗舰店](https://zave.tmall.com/)**++ | [EC11 旋转编码器 15mm 半轴柄](https://detail.tmall.com/item.htm?id=614080038092&skuId=5034452591940) |
| A3  | ++**[zave旗舰店](https://zave.tmall.com/)**++ | [Kailh BOX 轴体](https://detail.tmall.com/item.htm?id=639271554533&skuId=5232353392543) |
| A4  | 熊猫外设 | [KEYCOOL 卫星轴 6.25U](https://item.taobao.com/item.htm?id=1028713285265&skuId=6205214291793) |
| A5  | ++**[zave旗舰店](https://zave.tmall.com/)**++ | [RC522 mini NFC 模块](https://detail.tmall.com/item.htm?id=609470096659&skuId=4559514486884) |
| A6  | ++**[zave旗舰店](https://zave.tmall.com/)**++ | [WS2812B 5050 RGB LED](https://detail.tmall.com/item.htm?id=643957520185&skuId=4810589362903) |
| A7  | ++**[zave旗舰店](https://zave.tmall.com/)**++ | [22P 单排母座 2.54mm](https://detail.tmall.com/item.htm?id=607373839301&skuId=5735058853004) |
| A8  | ++**[zave旗舰店](https://zave.tmall.com/)**++ | [XH2.54 插座（选 SKU）](https://detail.tmall.com/item.htm?id=609069698010) |
| A9  | ++**[zave旗舰店](https://zave.tmall.com/)**++ | [XH2.54 端子线（选 SKU）](https://detail.tmall.com/item.htm?id=607825418214) |
| A10 | **[鹏宇电子科技](https://pengyu-circuit.taobao.com/)** | [USB-C 大电流 DIP 转接板 6P](https://item.taobao.com/item.htm?id=844266868488&skuId=5789976139613) |
| A11 | ++**[zave旗舰店](https://zave.tmall.com/)**++ | [0805 5.1KΩ 贴片电阻](https://detail.tmall.com/item.htm?id=607129192037&skuId=4265311209718) |
| A12 | ++**[zave旗舰店](https://zave.tmall.com/)**++ | [5.1KΩ 1/6W 直插电阻](https://detail.tmall.com/item.htm?id=614267859689&skuId=4494918971050) |
| A13 | ++**[zave旗舰店](https://zave.tmall.com/)**++ | SS34 肖特基二极管（同店搜索 "SS34 贴片 SMA"） |
| A14 | ++**[固万基官方旗舰店](https://guwanji.tmall.com/)**++ | [M2.5 不锈钢超薄头内六角螺丝](https://detail.tmall.com/item.htm?id=1036592632828&skuId=6215898378248) |
| A15 | ++**[固万基官方旗舰店](https://guwanji.tmall.com/)**++ | [M2.5 热熔铜螺母](https://detail.tmall.com/item.htm?id=673367228604&skuId=5074142984241) |
| A16 | JLCPCB | [jlcpcb.com](https://jlcpcb.com) |

### 单套成本估算

> 采购总计 ¥953 ÷ 12 套 = **¥79/套**

| 分类 | 单套成本 (¥) | 占比 |
| --- | --- | ---- |
| 主控 (ESP32-S3) | 32.75 | 39%  |
| 旋钮 (EC11 × 2) | 4.82 | 6% |
| 按钮 (Kailh + 卫星轴) | 12.93 | 15%  |
| NFC (RC522) | 12.43 | 15%  |
| LED (WS2812B) | 2.76 | 3% |
| 连接器 (排母 + 插座 + 端子线) | 5.62 | 7% |
| USB 集成 (转接板 + 电阻 + 二极管) | 3.12 | 4% |
| 五金 (螺丝 + 螺母) | 1.21 | 1% |
| PCB | 3.75 | 4% |
| **合计** | **~¥79** | 100% |

> USB 集成方案（方案 B）将原线缆成本从 ¥57.80/套 降至 ¥3.12/套，单套总成本从 ~¥134 降至 ~¥79。方案待面包板验证，详见 [docs/usb.md](../hardware/usb.md)。

### 外壳成本（仅完整设备需要）

| # | 部件 | 重量 | 单价 | 小计 (¥) | 备注 |
| --- | --- | ----- | --- | --- | --- |
| 1 | 主体壳 | ~180g | ¥0.06/g | 10.80 | 壁厚 2mm，含肋板 |
| 2 | 顶部模块 | ~80g  | ¥0.06/g | 4.80 | 按钮安装座 |
| 3 | 背板模块 | ~60g  | ¥0.06/g | 3.60 | 可替换 |
| 4 | 旋钮帽 × 2 | ~20g  | ¥0.06/g | 1.20 | |
| | **单套外壳合计** | ~340g | | **¥20.40** | |

> 平板由客户自购，不计入 BOM。

### 配套平板（客户自购，仅供接口评估参考）

| 项目 | 规格 |
| --- | --- |
| 型号 | Samsung Galaxy Tab A9 8.7" |
| 芯片号 | SM-X110 (Wi-Fi) |
| USB 接口  | Type-C 2.0 |
| USB OTG | 支持 (OTG 2.0) |
| USB PD  | 支持 (PD 2.0) |
| 充电功率 | 15W (5V/3A) |
| 电池 | 5100 mAh |
| 系统 | Android 13 / One UI 5.1 |

> **USB 方案评估要点**：Tab A9 支持 USB PD 2.0，意味着它具备 Power Role Swap 能力。方案 B（被动 VBUS 注入）需实测确认平板在 OTG Host 模式下是否接受外部 VBUS 充电；若不行，PD 2.0 支持为方案 C（PD 控制器）提供了升级路径。

---

## 三、原批量总物料成本（已取消）

| 项目 | 金额 (¥) | 说明 |
| --- | --- | --- |
| 电子元件采购（含 PCB） | 953 | 22 项，见采购清单（USB 集成方案后） |
| 3D 打印外壳 | 82 | 4 套 × ¥20.40 |
| PLA 耗材冗余 10%  | 8 | 失败重打余量 |
| XH2.54 压线钳 | 35 | 工具，一次性购入复用 |
| 运费（淘宝订单） | 20 | 天猫免运，淘宝 2-3 单 |
| **物料总计** | **¥1,098** | （原 ¥1,754，节省 ¥656） |

---

## 四、原批量工时估算（已取消）

| 任务 | 工时 (h)  | 说明 |
| --- | --- | --- |
| 按钮机构研究 + 原型验证 | 8 | Kailh 轴适配 + 3D 打印测试 |
| NFC 模块驱动开发 | 6 | RC522 SPI 接入 ESP32，固件扩展 |
| PCB 设计 + 打样 | 8 | KiCad 布局，JLCPCB 下单 |
| 外壳适配（Arthur 设计 → 打印验证） | 6 | 模块化结构配合调整 |
| 固件集成（按钮 + NFC + HID） | 6 | 合并新模块，USB HID 协议扩展 |
| 12 套电子件焊接组装 | 12 | PCB 焊接 + 连接器 + 测试 |
| 4 套完整设备组装 | 8 | 打印 + 装配 + 整机测试 |
| 文档 + 交付 | 4 | BOM 表、技术文档、组装指南 |
| **合计** | **58h** | ~7 个工作日 |

---

## 五、报价记录

### 2026-04-29 重启协议

| 项目 | 内容 |
|---|---|
| 范围 | 技术方案验证 + 单套原型制作 |
| 合同价 | ¥5,000 |
| 目标交付 | 2026-05-20 左右 |
| 核心挑战 | PCB 设计与验证 |
| 说明 | 原 4 套完整设备 + 8 套电子套件批量交付范围已取消 |

### 2026-04-01 原批量报价（已取消）

| 项目 | 金额 (¥) |
| --- | --- |
| 物料成本 | 1,098 |
| 人工 58h × ¥150/h | 8,700 |
| **成本合计** | **9,798** |
| 报价 | 15,000 |
| **毛利** | **¥5,202 (35%)** |

### 建议

- **¥15,000 报价合理**：物料占比 8%，主要价值在 NFC 开发、PCB 设计、USB 集成、按钮机构研发
- **付款节点建议**：签约预付 50% (¥7,500) → 交付验收付 50% (¥7,500)
- **成本优化已落地**：USB 集成方案将线缆成本从 ¥57.80/套降至 ¥3.12/套，12 套共节省 ¥656

---

## 六、供应商

| 代号 | 店铺 | 平台  | 链接 |
| --- | --- | --- | --- |
| zave | ++**[zave旗舰店](https://zave.tmall.com/)**++ | 天猫  | [店铺首页](https://zave.tmall.com) |
| Kailh  | **[Kailh旗舰店](https://kailh.tmall.com/)** | 天猫  | [店铺首页](https://kailh.tmall.com) |
| 优信 | **[深圳市优信电子科技](https://youxin-electronic.taobao.com/)** | 淘宝  | [SuperMini 系列](https://item.taobao.com/item.htm?id=988989854868) |
| 鹏宇 | **[深圳市鹏宇电子科技](https://pengyu-circuit.taobao.com/)** | 淘宝  | [USB-C 大电流转接板](https://item.taobao.com/item.htm?id=844266868488&skuId=5789976139613) |
| JLCPCB | 嘉立创 | 官网  | [jlcpcb.com](https://jlcpcb.com) |

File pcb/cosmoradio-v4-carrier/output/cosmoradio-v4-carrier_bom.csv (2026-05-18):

Refs | Value | Footprint | Qty | DNP
C1 | 10nF | Capacitor_SMD:C_0805_2012Metric | 1
C2 | 10nF | Capacitor_SMD:C_0805_2012Metric | 1
C3 | 10nF | Capacitor_SMD:C_0805_2012Metric | 1
C4 | 10nF | Capacitor_SMD:C_0805_2012Metric | 1
J1 | EC11-L-5P | Connector_JST:JST_XH_B5B-XH-A_1x05_P2.50mm_Vertical | 1
J2 | EC11-R-5P | Connector_JST:JST_XH_B5B-XH-A_1x05_P2.50mm_Vertical | 1
J3 | BTN-2P | Connector_JST:JST_XH_B2B-XH-A_1x02_P2.50mm_Vertical | 1
J4 | NFC-8P | Connector_JST:JST_XH_B8B-XH-A_1x08_P2.50mm_Vertical | 1
J5 | USB-DONGLE-4P | Connector_JST:JST_XH_B4B-XH-A_1x04_P2.50mm_Vertical | 1
R1 | 10k | Resistor_SMD:R_0805_2012Metric | 1
R2 | 10k | Resistor_SMD:R_0805_2012Metric | 1
R3 | 10k | Resistor_SMD:R_0805_2012Metric | 1
R4 | 10k | Resistor_SMD:R_0805_2012Metric | 1
U1A1 | DevKitC-Left-Socket | Connector_PinSocket_2.54mm:PinSocket_1x22_P2.54mm_Vertical | 1
U1B1 | DevKitC-Right-Socket | Connector_PinSocket_2.54mm:PinSocket_1x22_P2.54mm_Vertical | 1

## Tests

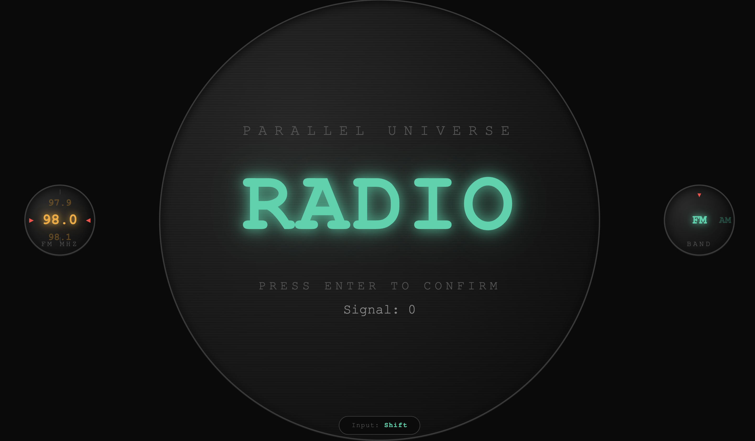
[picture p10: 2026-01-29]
test/cosmo-pager-radio.png

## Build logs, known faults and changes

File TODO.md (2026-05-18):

# CosmoRadio V4 — TODO

> 第四期：2026-04-01 启动 → 2026-04-02 取消 → 2026-04-29 重启
> 当前交付：技术方案验证 + 单套原型制作
> 项目文档：[docs/project/](docs/project/)（symlink → codex）
> 合同价：¥5,000
> 目标交付：2026-05-20 左右

## 2026-05-07 整体技术方案验证完成 ✅

电气、固件、NFC 协议在万能板飞线版上**端到端跑通**：

- ESP32-S3 DevKitC N16R8 主控 + 4 路 XH2.54 连接器（J1/J2 EC11、J3 按钮、J4 NFC）
- 拆解一分二 OTG + 充电线材内置子板，平板 USB Host + 充电同时工作
- 固件 V4 GPIO 全部跑通：Action Button、双 EC11 旋转 + 按压、板载 RGB
- NFC 链路：RC522 SPI（1MHz）→ 读 NTAG215 UID + NDEF Text Record → HID 键入 `#<payload>\n`
- 协议契约：NDEF Text 主路径 / `NFC:<UID>` 兜底 / 1.5s 同卡去重
- 端到端独立验证：iPhone NFC Tools 写入 "112358" → ESP32 读到字节级一致 UID + payload

**剩余工作集中在 PCB 设计 + 结构件 + 整机装配**，不再有方案级未知风险。

---

## 2026-05-08 今日双线并行 + PCB 前最后一项验证

| 线 | 谁 | 内容 |
|----|----|----|
| 固件 | Claude | 彻底优化升级到 V4（A 类技术债清理 + 代码整理） |
| 结构 | Dehong | NFC 模块 + 长按条按钮模块结构设计 + 历史结构改进 |

✅ **2026-05-18 PCB Plan v2 锁定**：USB 互联走线方案确定为"OTG dongle 拆 USB-A → 4 飞线 → J5 4P → DevKitC 排针 GPIO19/20"，固件不需 revert L/R swap，详见 `~/.claude/plans/iridescent-snuggling-planet.md`。

---

## 当前范围（2026-04-29 重启）

- [x] 与 Arthur 达成重启协议：V4 缩小为技术方案验证和单套原型制作
- [x] 合同价确认：¥5,000
- [x] 目标交付时间确认：2026-05-20 左右
- [x] **验证 PCB 载板设计路径** ✅ 2026-05-07（飞线版跑通，剩 KiCad 落版）
- [ ] 完成一套可演示原型，不再按 4 套整机 + 8 套电子套件交付

---

## 关键待办

### USB 互联走线 ✅ 2026-05-18 已锁定（Plan v2）

> 方案：OTG dongle (YK16-09E V1) 拆 USB-A 母座 → 4 根 AWG28 飞线 → J5 (XH2.54 4P) → DevKitC 排针 GPIO19/20 + 5V/GND。
> 详见 [`docs/hardware/otg-adapter.md`](docs/hardware/otg-adapter.md) + `~/.claude/plans/iridescent-snuggling-planet.md`。

- [x] OTG 子板选型 (YK16-09E V1) ✅ 2026-05-06
- [x] USB 走线方案确认（J5 4P → DevKitC 排针，无中间 USB-C 跳线）✅ 2026-05-18

### PCB 载板设计 ✅ 2026-05-18 落版完成 (Phase 1-7)
- [x] DevKitC N16R8 排针间距确认（22.86mm = 9 × 2.54mm pitch）✅ 2026-05-18
- [x] 用两条 1×22 单排母（不用 2×22 双排）✅ 2026-05-18
- [x] 加 4× 10kΩ + 4× 10nF EC11 RC 去抖网络 ✅ 2026-05-18
- [x] KiCad 原理图（circuit-synth Phase 2-3）：U1A/U1B + J1-J5 + R1-R4 + C1-C4 ✅
- [x] PCB layout（pcbnew API Phase 4）：100×100mm 双面板，B-type 立式直插，latch 朝外 ✅
- [x] Freerouting 自动布线 + DRC 0/0 ✅
- [x] 出 Gerber zip + BOM + 渲染图 (Phase 7) ✅ `pcb/cosmoradio-v4-carrier/output/`
- [x] EC11 端子线序按实物 SW-GND-A-GND-B (修正 v2 凭空 ABCDE 顺序错误) ✅ 2026-05-18
- [x] U1A pin 2 = GND (修正 v2 误标 5V 的短路隐患) ✅ 2026-05-18
- [x] 螺丝规格确认：M2.5×10 平头内六角 ✅
- [ ] **JLCPCB 上传 zip 下单打样 (5 片免费打样)**
- [ ] PCB 到货后焊接：2× 1×22 排母 + 5× B-type JST + 8× 0805 + 4× M2.5 螺孔
- [ ] schematic PDF 手动连线修正 (circuit-synth ≥3-node 网塌网 bug 的可视化修复，不影响 Gerber)

### USB-C 板载集成评估 ✅ 2026-05-18 关闭 — OTG dongle 方案替代
> ~~原方案 B：PCB 双 USB-C 座 + 被动 SS34 VBUS 注入~~ → 2026-04-30 实测失败（Tab A9 PD 协议不接受）
> **最终方案**：外购 OTG dongle (YK16-09E V1) 拆 USB-A 内置，详见 [docs/hardware/otg-adapter.md](docs/hardware/otg-adapter.md)
> ~~历史选型详情~~ → [docs/hardware/usb.md](docs/hardware/usb.md) (已标记历史文档)

- [x] 研究 USB-C 母座直焊 PCB 方案（CC 引脚配置、ESD 保护）→ 鹏宇 6P 大电流转接板，板载 5.1kΩ CC pull-down
- [x] 研究 USB 信号分流芯片（如 USB Hub IC），实现板载一分二 → 不需要 Hub IC，被动 VBUS 注入即可
- [x] 对比方案成本：USB-C 母座 (~¥3) + Hub IC (~¥5) + 被动元件 vs 当前 ¥57.80 → ¥3.12/套 vs ¥57.80/套
- [x] 评估 JLCPCB SMT 贴片可行性（Hub IC 封装是否支持）→ 无需 SMT，DIP 转接板直插
- [x] **被动 SS34 注入实测**（2026-04-30）→ 失败，6P 转接板 + SS34 无法让 Tab A9 同时进入 Data Host + Power Sink，弃用为主线
- [x] **采购一分二 OTG + 充电线材**（2026-05-06）→ 已购买多种型号，测试出一种比较理想的可作为内置子板基准
- [x] **手工万能板原型集成**（2026-05-06，[图片](docs/assets/v4-handmade-prototype-2026-05-06.jpg)）→ ESP32-S3 DevKitC + 拆解后的一分二小板 + 5 路 XH2.54 连接器已焊出
- [ ] 万能板上回归测试：HID 枚举 / 充电接入 / 电池电量净增 / 热稳定 2h
- [ ] 根据万能板验证结果，更新 PCB Spec 和原理图

### 按钮机构
> 选定方案：键盘轴 + 6.25U 卫星轴空格键，长度 ~10cm
> 状态：物料预计 04-02/03 到货，待手感测试
> ⚠️ **测试机变更（2026-05-06）**：原 R4 Pad（Arthur 寄来）因操作失误已损坏，临时使用安卓手机替代验证 USB HID + 充电链路。Tab A9 行为兼容性需在拿到新 Pad 后再回归一遍。

- [ ] 收到 Arthur 寄来的 Pad → 装配按钮测试手感
- [ ] Kailh BOX 轴 + 6.25U 卫星轴原型测试
- [ ] 3D 打印键帽适配（与 Arthur 外壳顶部模块配合）
- [ ] 行程验证 ≥ 3mm，稳定性测试
- [ ] **新 Tab A9 到货后**：回归 HID + 充电链路（当前在安卓手机上验证）

### NFC 模块
> 方案设计完成 ✅ 2026-04-01，详见 [docs/hardware/nfc.md](docs/hardware/nfc.md)
> 驱动库：`abobija/esp-idf-rc522` v3.4.3 (ESP Component Registry)
> 通信协议：HID 键盘逐字符键入 `NFC:<UID_HEX>\n`，平板端解析
> ✅ **NFC 数量已确认（2026-05-06）**：1 个 RC522 mini，最终方案，不再讨论。

- [x] 方案调研：模块选型、标签选型、驱动库评估、可行性分析 ✅ 2026-04-01
- [x] 确定安装位置：**外壳顶部模块内侧**（天线朝上） ✅ 2026-04-01
- [x] J4 连接器 pinout 确认（8P，与模块物理丝印一一对应） ✅ 2026-04-01
- [x] NFC 数量决策：1 个 ✅ 2026-05-06
- [x] RC522 mini SPI 驱动开发（ESP-IDF，abobija/rc522 v3.x） ✅ 2026-05-07
- [x] NTAG215 UID 读取 → HID 字符串键入实现 ✅ 2026-05-07
- [x] **NDEF Text Record 解析**：从卡上读出用户写入的字符串 ✅ 2026-05-07
- [x] 同卡 1.5s 去重（应对 RC522 心跳抖动） ✅ 2026-05-07
- [ ] 天线读取距离测试（穿透 3D 打印壁厚 2mm）— 留到外壳打印后

### 固件迁移
- [x] **设计 V4 引脚接线方案**（CLAUDE.md GPIO 表定稿，与万能板焊接一致） ✅ 2026-05-06
- [x] SuperMini → DevKitC N16R8 GPIO 重映射（input_handler.c / led_indicator.c） ✅ 2026-05-06
- [x] 新增 NFC SPI 模块（SPI2 GPIO Matrix，1MHz） ✅ 2026-05-07
- [x] 新增按钮 + 双 EC11 SW 处理（GPIO1 / GPIO8 / GPIO40） ✅ 2026-05-06
- [x] input_handler 扩展：NFC 事件 → `nfc_handler.c` 独立模块 + HID 字符串键入 ✅ 2026-05-07
- [x] 万能板上烧录验证：旋钮 / 按钮 / NFC 全链路 ✅ 2026-05-07
- [x] CLAUDE.md GPIO 分配表确认 ✅ 2026-05-06
- [x] `sdkconfig.defaults` 更新：N16R8 16MB flash + octal PSRAM ✅ 2026-05-08
- [x] HID Key Report 多键并发支持（`pressed_keys[6]` 状态数组 + mutex，消除 NFC 字符串注入与用户按键的竞态） ✅ 2026-05-08
- [x] NFC 启动失败容错：`nfc_handler_init/start` 失败时只 warning 不 abort，裸板（无 RC522）演示不再 reboot loop ✅ 2026-05-10
- [ ] NFC SPI 时钟从 1MHz 拉回 5MHz（需 PCB 焊好后验证，飞线版受 RF 噪声干扰）

### 旋钮与协议
> ✅ 协议定稿（2026-05-07，2026-05-15 简化）：详见 [README.md 交互设计](README.md#交互设计) 和 [CLAUDE.md HID Key Mappings](CLAUDE.md)
> NFC 主路径：固件读 NDEF Text → 原样键入 + Enter（无前缀，2026-05-15 起去掉 `#`）；UID 兜底用 `NFC:` 前缀

- [x] 编写旋钮 + NFC HID 协议（CLAUDE.md HID Key Mappings + NFC Tag 内容编码契约） ✅ 2026-05-07

### 外壳适配
> Arthur 已展示概念图，基本还原效果。设备可能两边各宽 1cm 增加安装灵活性。
> 充电口需留位，可水平插入。顶板螺丝固定，M2.5×10 平头内六角。
> **2026-05-08 起 Dehong 自己负责**：NFC 模块结构 + 长按条按钮模块结构 + 历史结构改进。

- [ ] **NFC 模块结构设计**（Dehong）：天线朝外、与 PCB 安装位对齐、走线通道
- [ ] **长按条按钮模块结构设计**（Dehong）：键盘轴 + 6.25U 卫星轴空格键，按压行程 + 装配方式
- [ ] **历史结构改进**（Dehong）：复盘 R1-R3 装配中暴露的问题点
- [ ] 与 Arthur 对接 Fusion 360 模型 (`cosmo-radio-v4-arthur`)
- [ ] 模块化验证：主体 / 顶部 / 背板 三件可独立打印
- [ ] PCB 安装孔位对齐（4 × M2.5）
- [ ] 线缆走线通道确认（取决于 USB 互联走线方案是否落地）
- [ ] Arthur 修改设计：充电口位置、设备宽度调整 → 打印小号模型验证
- [ ] NFC 位置确定后，协调另一侧用途（指示灯 vs 留空）

### 成本核算
> 单套估算 ¥79（不含线材）：主控板 ~¥32 (40%)，按钮+卫星轴 ~¥13，NFC IC ~¥13，底部 PCB 较便宜

- [x] 04-29 重启后合同价调整为 ¥5,000，原 12 套 ¥13,000 报价只作为历史参考
- [ ] 精确估算单套电路成本（待 PCB 设计定稿）
- [ ] 精确估算整机成本（含 3D 打印 + 组装工时）
- [ ] 重新估算单套原型的材料、PCB 打样、工时成本

### 组装与交付
- [ ] 1 套电子件：PCB 焊接 + 连接器 + 功能测试
- [ ] 1 套完整原型：打印 + 装配 + 整机测试
- [ ] 编写技术验证记录（PCB、USB-C、按钮、NFC、固件）
- [ ] 交付文件上传飞书

---

## 重启协议 2026-04-29（与 Arthur）

关键决策：
1. **范围**：仅做技术方案验证和单套原型制作
2. **报价**：¥5,000
3. **目标交付**：2026-05-20 左右
4. **核心挑战**：PCB 设计与验证
5. **合作定位**：保留和 Arthur 的持续硬件合作，不恢复原 4+8 批量交付合同

---

## 会议纪要 2026-04-01（与 Arthur/纪晟）

关键决策：
1. **音响**：使用平板自带音响，不外接
2. **按钮**：键盘轴 + 6.25U 卫星轴空格键（~10cm），物料预计 04-02/03 到
3. **NFC 数量**：待杨炜乐确认（1 vs 2），1 个 NFC = 8 根线，2 个 GPIO 开销过大
4. **螺丝**：M2.5×10 平头内六角
5. **旋钮按压**：EC11 SW 引脚会接线，功能可选不用
6. **设备宽度**：暂继续用弯头线，两边各宽 1cm 增加安装灵活性
7. **成本**：单套 ¥79（不含线材），12 套总计约 ¥13,000
8. **付款**：1 周后基础方案验证完成预付 50%

会后 Action Items：
- [ ] Arthur 与杨炜乐讨论 NFC 数量 → 结果告知 Dehong
- [ ] Arthur 寄 Pad → Dehong 收到后测试按钮手感
- [ ] Dehong 估算单套电路和整机价格
- [ ] Arthur 修改设计（充电口位置、宽度）→ 打印小号模型
- [ ] Dehong 编写旋钮 + NFC 协议规范文档

---

## 时间节点

| 日期 | 事项 |
|---|---|
| 04-01 | V4 正式启动，BOM 定稿，第一次需求会议 |
| 04-02 | 原 4 套整机 + 8 套电子套件合同取消 |
| 04-02/03 | 键盘轴物料到货，开始按钮手感测试 |
| 04-04 | Arthur 海运两个铁箱（现有设备） |
| 04-29 | 与 Arthur 重启 V4，范围缩小为技术验证 + 单套原型，合同价 ¥5,000 |
| 05-06 | 万能板飞线原型焊接，V4 GPIO 全部跑通 |
| 05-07 | NFC NDEF Text 解析 + `#<payload>\n` 协议落地，端到端跑通 |
| 05-08 | 固件 V4 彻底优化（sdkconfig + HID 多键并发）+ 结构件设计启动 + USB 互联走线验证 |
| 05-15 | NFC HID 协议简化：NDEF payload 去掉 `#` 前缀，固件 + 文档同步；端到端实卡验证通过（UID `04A38B6A220289`→`004`、`0463DA47220289`→`002`） |
| 05 中旬 | KiCad PCB 设计 + 外壳 3D 模型适配 |
| ~05-20 | 单套原型装配 + 交付技术验证结果 |

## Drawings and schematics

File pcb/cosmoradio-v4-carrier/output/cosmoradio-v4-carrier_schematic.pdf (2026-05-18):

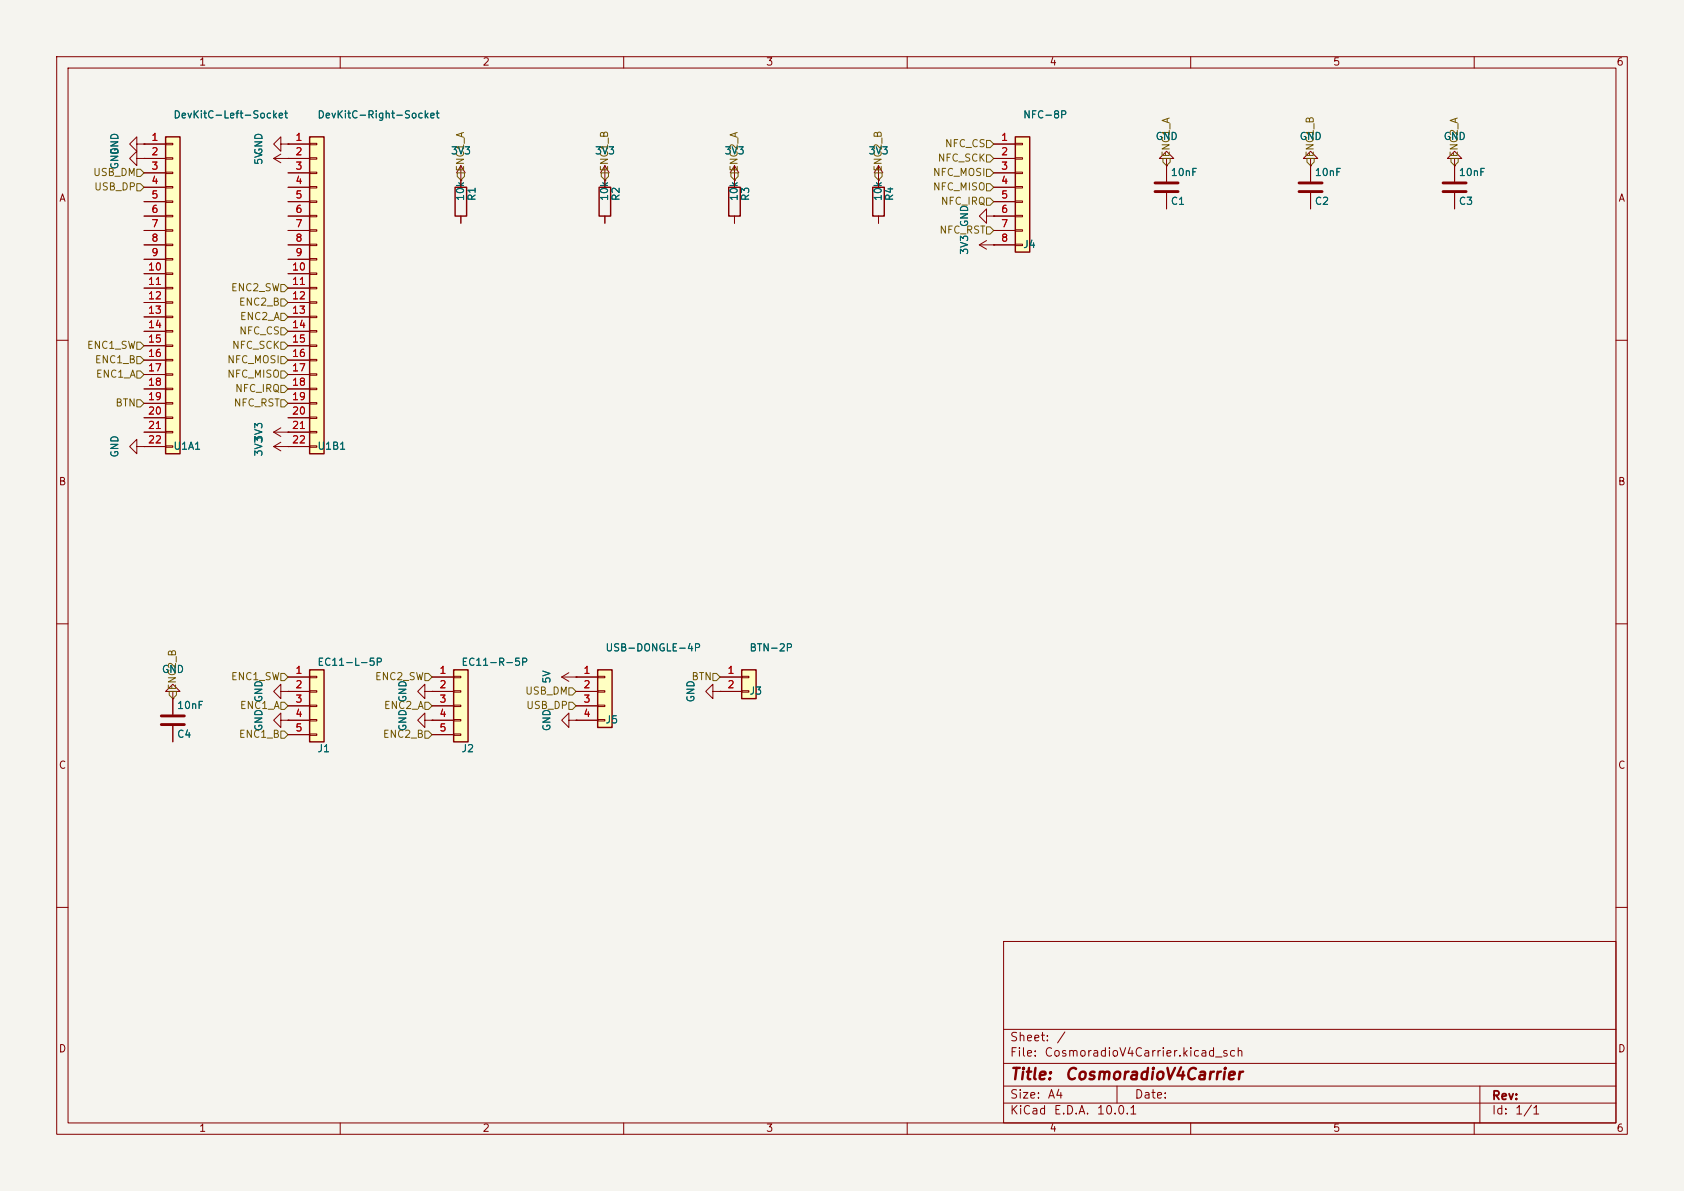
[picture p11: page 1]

Size: A4 | Rev:
KiCad E.D.A. 10.0.1 | Id: 1/1

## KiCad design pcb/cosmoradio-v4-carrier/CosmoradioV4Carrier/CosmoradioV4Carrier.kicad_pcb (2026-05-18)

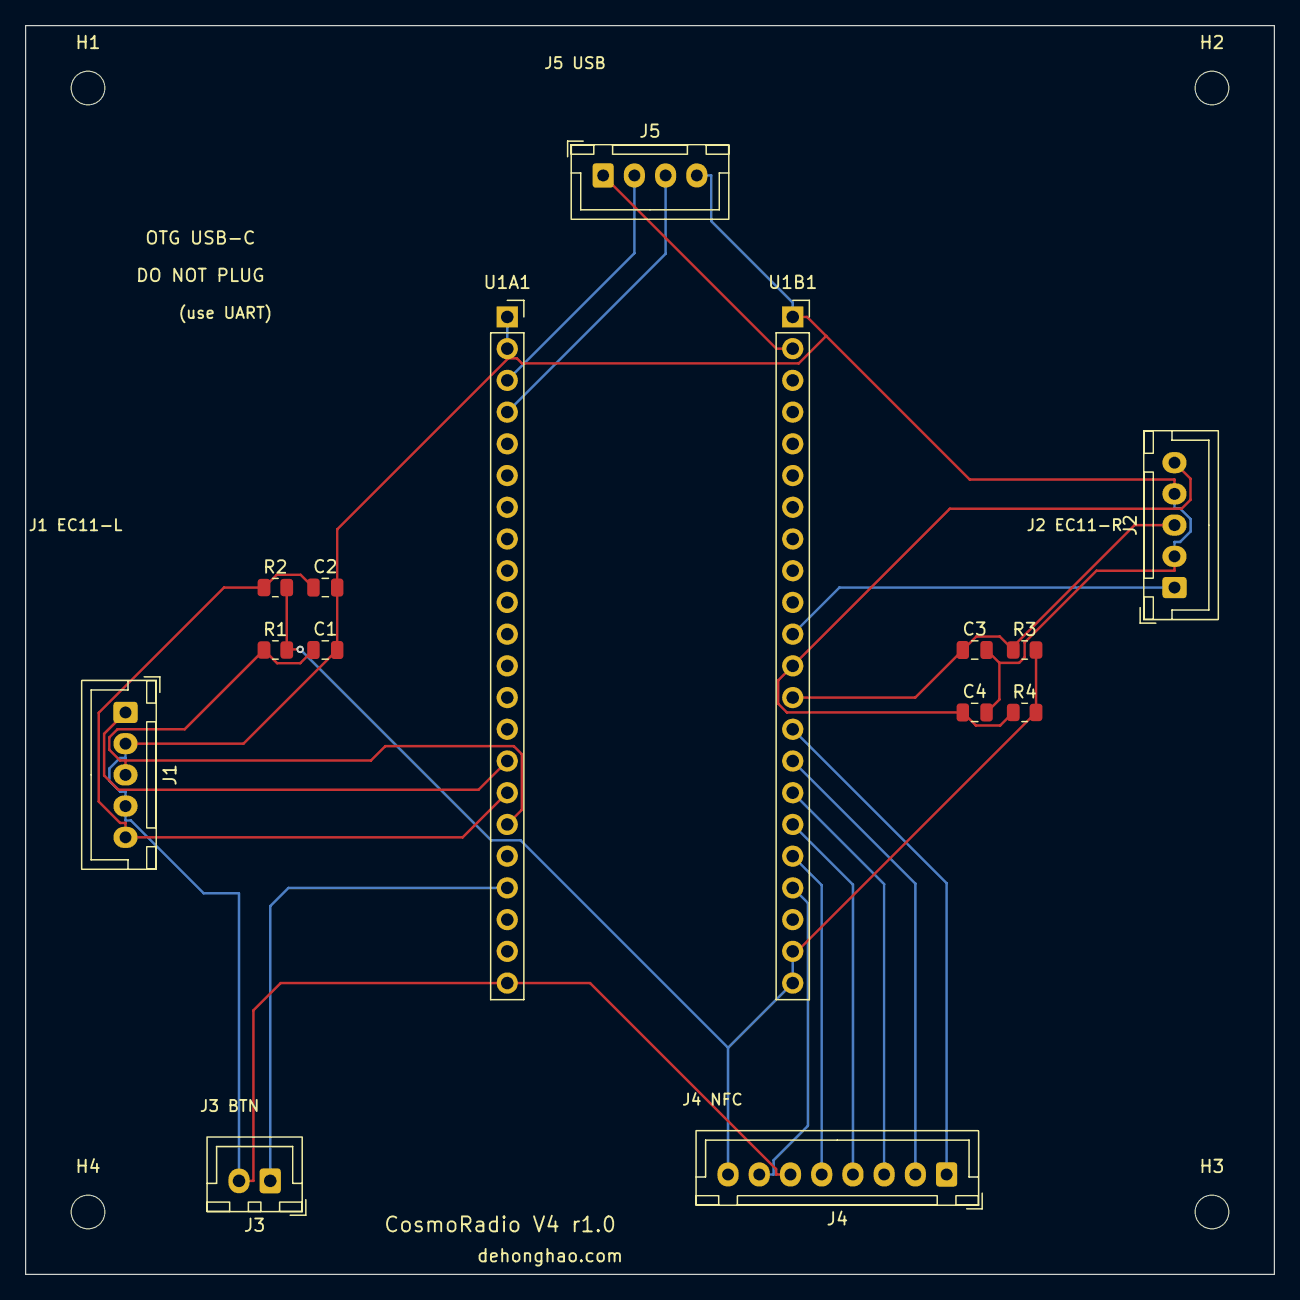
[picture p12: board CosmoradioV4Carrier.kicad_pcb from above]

Board: 2 copper layers, 100.0 x 100.0 mm, 19 parts (0 on the bottom side), 18 nets.

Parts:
C1, C2, C3, C4: 10nF; C_0805_2012Metric
H1, H2, H3, H4: MountingHole_2.7mm_M2.5
J1: EC11-L; JST_XH_B5B-XH-A_1x05_P2.50mm_Vertical
J2: EC11-R; JST_XH_B5B-XH-A_1x05_P2.50mm_Vertical
J3: BTN; JST_XH_B2B-XH-A_1x02_P2.50mm_Vertical
J4: NFC; JST_XH_B8B-XH-A_1x08_P2.50mm_Vertical
J5: USB-DONGLE; JST_XH_B4B-XH-A_1x04_P2.50mm_Vertical
R1, R2, R3, R4: 10k; R_0805_2012Metric
U1A1: DevKitC-L; PinSocket_1x22_P2.54mm_Vertical
U1B1: DevKitC-R; PinSocket_1x22_P2.54mm_Vertical

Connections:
3V3: J4.8, R1.2, R2.2, R3.2, R4.2, U1B1.21, U1B1.22
5V: J5.1, U1B1.2
BTN: J3.1, U1A1.19
ENC1_A: C1.1, J1.3, R1.1, U1A1.17
ENC1_B: C2.1, J1.5, R2.1, U1A1.16
ENC1_SW: J1.1, U1A1.15
ENC2_A: C3.1, J2.3, R3.1, U1B1.13
ENC2_B: C4.1, J2.5, R4.1, U1B1.12
ENC2_SW: J2.1, U1B1.11
GND: C1.2, C2.2, C3.2, C4.2, J1.2, J1.4, J2.2, J2.4, J3.2, J4.6, J5.4, U1A1.1, U1A1.2, U1A1.22, U1B1.1
NFC_CS: J4.1, U1B1.14
NFC_IRQ: J4.5, U1B1.18
NFC_MISO: J4.4, U1B1.17
NFC_MOSI: J4.3, U1B1.16
NFC_RST: J4.7, U1B1.19
NFC_SCK: J4.2, U1B1.15
USB_DM: J5.2, U1A1.3
USB_DP: J5.3, U1A1.4

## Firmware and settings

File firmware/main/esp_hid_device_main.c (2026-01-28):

/*
 * SPDX-FileCopyrightText: 2021-2024 Espressif Systems (Shanghai) CO LTD
 *
 * SPDX-License-Identifier: Unlicense OR CC0-1.0
 */

#include <stdio.h>
#include <stdlib.h>
#include <string.h>
#include <inttypes.h>

#include "freertos/FreeRTOS.h"
#include "freertos/task.h"
#include "freertos/event_groups.h"
#include "esp_system.h"
#include "esp_wifi.h"
#include "esp_event.h"
#include "esp_log.h"
#include "nvs_flash.h"
#include "esp_bt.h"

#if CONFIG_BT_NIMBLE_ENABLED
#include "host/ble_hs.h"
#include "nimble/nimble_port.h"
#include "nimble/nimble_port_freertos.h"
#else
#include "esp_bt_defs.h"
#if CONFIG_BT_BLE_ENABLED
#include "esp_gap_ble_api.h"
#include "esp_gatts_api.h"
#include "esp_gatt_defs.h"
#endif
#include "esp_bt_main.h"
#include "esp_bt_device.h"
#if CONFIG_BT_SDP_COMMON_ENABLED
#include "esp_sdp_api.h"
#endif /* CONFIG_BT_SDP_COMMON_ENABLED */
#endif

#include "esp_hidd.h"
#include "esp_hid_gap.h"
#include "driver/gpio.h"
#include "device_identity.h"
#include "input_handler.h"
#include "led_indicator.h"

// HID key codes for arrow keys and enter
// Note: GPIO definitions are in input_handler.c
#define HID_KEY_ENTER       0x28
#define HID_KEY_UP_ARROW    0x52
#define HID_KEY_DOWN_ARROW  0x51
#define HID_KEY_LEFT_ARROW  0x50
#define HID_KEY_RIGHT_ARROW 0x4F

static const char *TAG = "HID_DEV_DEMO";

typedef struct
{
    TaskHandle_t task_hdl;
    esp_hidd_dev_t *hid_dev;
    uint8_t protocol_mode;
    uint8_t *buffer;
} local_param_t;

#if CONFIG_BT_BLE_ENABLED || CONFIG_BT_NIMBLE_ENABLED
static local_param_t s_ble_hid_param = {0};

const unsigned char mediaReportMap[] = {
    0x05, 0x0C,        // Usage Page (Consumer)
    0x09, 0x01,        // Usage (Consumer Control)
    0xA1, 0x01,        // Collection (Application)
    0x85, 0x03,        //   Report ID (3)
    0x09, 0x02,        //   Usage (Numeric Key Pad)
    0xA1, 0x02,        //   Collection (Logical)
    0x05, 0x09,        //     Usage Page (Button)
    0x19, 0x01,        //     Usage Minimum (0x01)
    0x29, 0x0A,        //     Usage Maximum (0x0A)
    0x15, 0x01,        //     Logical Minimum (1)
    0x25, 0x0A,        //     Logical Maximum (10)
    0x75, 0x04,        //     Report Size (4)
    0x95, 0x01,        //     Report Count (1)
    0x81, 0x00,        //     Input (Data,Array,Abs,No Wrap,Linear,Preferred State,No Null Position)
    0xC0,              //   End Collection
    0x05, 0x0C,        //   Usage Page (Consumer)
    0x09, 0x86,        //   Usage (Channel)
    0x15, 0xFF,        //   Logical Minimum (-1)
    0x25, 0x01,        //   Logical Maximum (1)
    0x75, 0x02,        //   Report Size (2)
    0x95, 0x01,        //   Report Count (1)
    0x81, 0x46,        //   Input (Data,Var,Rel,No Wrap,Linear,Preferred State,Null State)
    0x09, 0xE9,        //   Usage (Volume Increment)
    0x09, 0xEA,        //   Usage (Volume Decrement)
    0x15, 0x00,        //   Logical Minimum (0)
    0x75, 0x01,        //   Report Size (1)
    0x95, 0x02,        //   Report Count (2)
    0x81, 0x02,        //   Input (Data,Var,Abs,No Wrap,Linear,Preferred State,No Null Position)
    0x09, 0xE2,        //   Usage (Mute)
    0x09, 0x30,        //   Usage (Power)
    0x09, 0x83,        //   Usage (Recall Last)
    0x09, 0x81,        //   Usage (Assign Selection)
    0x09, 0xB0,        //   Usage (Play)
    0x09, 0xB1,        //   Usage (Pause)
    0x09, 0xB2,        //   Usage (Record)
    0x09, 0xB3,        //   Usage (Fast Forward)
    0x09, 0xB4,        //   Usage (Rewind)
    0x09, 0xB5,        //   Usage (Scan Next Track)
    0x09, 0xB6,        //   Usage (Scan Previous Track)
    0x09, 0xB7,        //   Usage (Stop)
    0x15, 0x01,        //   Logical Minimum (1)
    0x25, 0x0C,        //   Logical Maximum (12)
    0x75, 0x04,        //   Report Size (4)
    0x95, 0x01,        //   Report Count (1)
    0x81, 0x00,        //   Input (Data,Array,Abs,No Wrap,Linear,Preferred State,No Null Position)
    0x09, 0x80,        //   Usage (Selection)
    0xA1, 0x02,        //   Collection (Logical)
    0x05, 0x09,        //     Usage Page (Button)
    0x19, 0x01,        //     Usage Minimum (0x01)
    0x29, 0x03,        //     Usage Maximum (0x03)
    0x15, 0x01,        //     Logical Minimum (1)
    0x25, 0x03,        //     Logical Maximum (3)
    0x75, 0x02,        //     Report Size (2)
    0x81, 0x00,        //     Input (Data,Array,Abs,No Wrap,Linear,Preferred State,No Null Position)
    0xC0,              //   End Collection
    0x81, 0x03,        //   Input (Const,Var,Abs,No Wrap,Linear,Preferred State,No Null Position)
    0xC0,              // End Collection
};
#if CONFIG_EXAMPLE_HID_DEVICE_ROLE && CONFIG_EXAMPLE_HID_DEVICE_ROLE == 3
const unsigned char mouseReportMap[] = {
    0x05, 0x01,                    // USAGE_PAGE (Generic Desktop)
    0x09, 0x02,                    // USAGE (Mouse)
    0xa1, 0x01,                    // COLLECTION (Application)

    0x09, 0x01,                    //   USAGE (Pointer)
    0xa1, 0x00,                    //   COLLECTION (Physical)

    0x05, 0x09,                    //     USAGE_PAGE (Button)
    0x19, 0x01,                    //     USAGE_MINIMUM (Button 1)
    0x29, 0x03,                    //     USAGE_MAXIMUM (Button 3)
    0x15, 0x00,                    //     LOGICAL_MINIMUM (0)
    0x25, 0x01,                    //     LOGICAL_MAXIMUM (1)
    0x95, 0x03,                    //     REPORT_COUNT (3)
    0x75, 0x01,                    //     REPORT_SIZE (1)
    0x81, 0x02,                    //     INPUT (Data,Var,Abs)
    0x95, 0x01,                    //     REPORT_COUNT (1)
    0x75, 0x05,                    //     REPORT_SIZE (5)
    0x81, 0x03,                    //     INPUT (Cnst,Var,Abs)

    0x05, 0x01,                    //     USAGE_PAGE (Generic Desktop)
    0x09, 0x30,                    //     USAGE (X)
    0x09, 0x31,                    //     USAGE (Y)
    0x09, 0x38,                    //     USAGE (Wheel)
    0x15, 0x81,                    //     LOGICAL_MINIMUM (-127)
    0x25, 0x7f,                    //     LOGICAL_MAXIMUM (127)
    0x75, 0x08,                    //     REPORT_SIZE (8)
    0x95, 0x03,                    //     REPORT_COUNT (3)
    0x81, 0x06,                    //     INPUT (Data,Var,Rel)

    0xc0,                          //   END_COLLECTION
    0xc0                           // END_COLLECTION
};
// send the buttons, change in x, and change in y
void send_mouse(uint8_t buttons, char dx, char dy, char wheel)
{
    static uint8_t buffer[4] = {0};
    buffer[0] = buttons;
    buffer[1] = dx;
    buffer[2] = dy;
    buffer[3] = wheel;
    esp_hidd_dev_input_set(s_ble_hid_param.hid_dev, 0, 0, buffer, 4);
}

void ble_hid_demo_task_mouse(void *pvParameters)
{
    static const char* help_string = "########################################################################\n"\
    "BT hid mouse demo usage:\n"\
    "You can input these value to simulate mouse: 'q', 'w', 'e', 'a', 's', 'd', 'h'\n"\
    "q -- click the left key\n"\
    "w -- move up\n"\
    "e -- click the right key\n"\
    "a -- move left\n"\
    "s -- move down\n"\
    "d -- move right\n"\
    "h -- show the help\n"\
    "########################################################################\n";
    printf("%s\n", help_string);
    char c;
    while (1) {
        c = fgetc(stdin);
        switch (c) {
        case 'q':
            send_mouse(1, 0, 0, 0);
            break;
        case 'w':
            send_mouse(0, 0, -10, 0);
            break;
        case 'e':
            send_mouse(2, 0, 0, 0);
            break;
        case 'a':
            send_mouse(0, -10, 0, 0);
            break;
        case 's':
            send_mouse(0, 0, 10, 0);
            break;
        case 'd':
            send_mouse(0, 10, 0, 0);
            break;
        case 'h':
            printf("%s\n", help_string);
            break;
        default:
            break;
        }
        vTaskDelay(10 / portTICK_PERIOD_MS);
    }
}
#endif

#if CONFIG_EXAMPLE_HID_DEVICE_ROLE && CONFIG_EXAMPLE_HID_DEVICE_ROLE == 2
#define CASE(a, b, c)  \
                case a: \
				buffer[0] = b;  \
				buffer[2] = c; \
                break;\

// USB keyboard codes
#define USB_HID_MODIFIER_LEFT_CTRL      0x01
#define USB_HID_MODIFIER_LEFT_SHIFT     0x02
#define USB_HID_MODIFIER_LEFT_ALT       0x04
#define USB_HID_MODIFIER_RIGHT_CTRL     0x10
#define USB_HID_MODIFIER_RIGHT_SHIFT    0x20
#define USB_HID_MODIFIER_RIGHT_ALT      0x40

#define USB_HID_SPACE                   0x2C
#define USB_HID_DOT                     0x37
#define USB_HID_NEWLINE                 0x28
#define USB_HID_FSLASH                  0x38
#define USB_HID_BSLASH                  0x31
#define USB_HID_COMMA                   0x36
#define USB_HID_DOT                     0x37

const unsigned char keyboardReportMap[] = { //7 bytes input (modifiers, resrvd, keys*5), 1 byte output
    0x05, 0x01,        // Usage Page (Generic Desktop Ctrls)
    0x09, 0x06,        // Usage (Keyboard)
    0xA1, 0x01,        // Collection (Application)
    0x85, 0x01,        //   Report ID (1)
    0x05, 0x07,        //   Usage Page (Kbrd/Keypad)
    0x19, 0xE0,        //   Usage Minimum (0xE0)
    0x29, 0xE7,        //   Usage Maximum (0xE7)
    0x15, 0x00,        //   Logical Minimum (0)
    0x25, 0x01,        //   Logical Maximum (1)
    0x75, 0x01,        //   Report Size (1)
    0x95, 0x08,        //   Report Count (8)
    0x81, 0x02,        //   Input (Data,Var,Abs,No Wrap,Linear,Preferred State,No Null Position)
    0x95, 0x01,        //   Report Count (1)
    0x75, 0x08,        //   Report Size (8)
    0x81, 0x03,        //   Input (Const,Var,Abs,No Wrap,Linear,Preferred State,No Null Position)
    0x95, 0x05,        //   Report Count (5)
    0x75, 0x01,        //   Report Size (1)
    0x05, 0x08,        //   Usage Page (LEDs)
    0x19, 0x01,        //   Usage Minimum (Num Lock)
    0x29, 0x05,        //   Usage Maximum (Kana)
    0x91, 0x02,        //   Output (Data,Var,Abs,No Wrap,Linear,Preferred State,No Null Position,Non-volatile)
    0x95, 0x01,        //   Report Count (1)
    0x75, 0x03,        //   Report Size (3)
    0x91, 0x03,        //   Output (Const,Var,Abs,No Wrap,Linear,Preferred State,No Null Position,Non-volatile)
    0x95, 0x05,        //   Report Count (5)
    0x75, 0x08,        //   Report Size (8)
    0x15, 0x00,        //   Logical Minimum (0)
    0x25, 0x65,        //   Logical Maximum (101)
    0x05, 0x07,        //   Usage Page (Kbrd/Keypad)
    0x19, 0x00,        //   Usage Minimum (0x00)
    0x29, 0x65,        //   Usage Maximum (0x65)
    0x81, 0x00,        //   Input (Data,Array,Abs,No Wrap,Linear,Preferred State,No Null Position)
    0xC0,              // End Collection

    // 65 bytes
};

static void char_to_code(uint8_t *buffer, char ch)
{
	// Check if lower or upper case
	if(ch >= 'a' && ch <= 'z')
	{
		buffer[0] = 0;
		// convert ch to HID letter, starting at a = 4
		buffer[2] = (uint8_t)(4 + (ch - 'a'));
	}
	else if(ch >= 'A' && ch <= 'Z')
	{
		// Add left shift
		buffer[0] = USB_HID_MODIFIER_LEFT_SHIFT;
		// convert ch to lower case
		ch = ch - ('A'-'a');
		// convert ch to HID letter, starting at a = 4
		buffer[2] = (uint8_t)(4 + (ch - 'a'));
	}
	else if(ch >= '0' && ch <= '9') // Check if number
	{
		buffer[0] = 0;
		// convert ch to HID number, starting at 1 = 30, 0 = 39
		if(ch == '0')
		{
			buffer[2] = 39;
		}
		else
		{
			buffer[2] = (uint8_t)(30 + (ch - '1'));
		}
	}
	else // not a letter nor a number
	{
		switch(ch)
		{
            CASE(' ', 0, USB_HID_SPACE);
			CASE('.', 0,USB_HID_DOT);
            CASE('\n', 0, USB_HID_NEWLINE);
			CASE('?', USB_HID_MODIFIER_LEFT_SHIFT, USB_HID_FSLASH);
			CASE('/', 0 ,USB_HID_FSLASH);
			CASE('\\', 0, USB_HID_BSLASH);
			CASE('|', USB_HID_MODIFIER_LEFT_SHIFT, USB_HID_BSLASH);
			CASE(',', 0, USB_HID_COMMA);
			CASE('<', USB_HID_MODIFIER_LEFT_SHIFT, USB_HID_COMMA);
			CASE('>', USB_HID_MODIFIER_LEFT_SHIFT, USB_HID_COMMA);
			CASE('@', USB_HID_MODIFIER_LEFT_SHIFT, 31);
			CASE('!', USB_HID_MODIFIER_LEFT_SHIFT, 30);
			CASE('#', USB_HID_MODIFIER_LEFT_SHIFT, 32);
			CASE('$', USB_HID_MODIFIER_LEFT_SHIFT, 33);
			CASE('%', USB_HID_MODIFIER_LEFT_SHIFT, 34);
			CASE('^', USB_HID_MODIFIER_LEFT_SHIFT,35);
			CASE('&', USB_HID_MODIFIER_LEFT_SHIFT, 36);
			CASE('*', USB_HID_MODIFIER_LEFT_SHIFT, 37);
			CASE('(', USB_HID_MODIFIER_LEFT_SHIFT, 38);
			CASE(')', USB_HID_MODIFIER_LEFT_SHIFT, 39);
			CASE('-', 0, 0x2D);
			CASE('_', USB_HID_MODIFIER_LEFT_SHIFT, 0x2D);
			CASE('=', 0, 0x2E);
			CASE('+', USB_HID_MODIFIER_LEFT_SHIFT, 39);
			CASE(8, 0, 0x2A); // backspace
			CASE('\t', 0, 0x2B);
			default:
				buffer[0] = 0;
				buffer[2] = 0;
		}
	}
}

void send_keyboard(char c)
{
    static uint8_t buffer[8] = {0};
    char_to_code(buffer, c);
    esp_hidd_dev_input_set(s_ble_hid_param.hid_dev, 0, 1, buffer, 8);
    /* send the keyrelease event with sufficient delay */
    vTaskDelay(50 / portTICK_PERIOD_MS);
    memset(buffer, 0, sizeof(uint8_t) * 8);
    esp_hidd_dev_input_set(s_ble_hid_param.hid_dev, 0, 1, buffer, 8);
}

// Note: GPIO initialization is now handled by input_handler module

// Send key press event (key down)
static void send_key_down(uint8_t keycode)
{
    if (s_ble_hid_param.hid_dev == NULL) {
        return;
    }
    uint8_t buffer[8] = {0};
    buffer[2] = keycode;
    esp_hidd_dev_input_set(s_ble_hid_param.hid_dev, 0, 1, buffer, 8);
}

// Send key release event (key up)
static void send_key_up(void)
{
    if (s_ble_hid_param.hid_dev == NULL) {
        return;
    }
    uint8_t buffer[8] = {0};
    esp_hidd_dev_input_set(s_ble_hid_param.hid_dev, 0, 1, buffer, 8);
}

// Send a single key press and release (pulse mode for rotary encoders)
static void send_key_pulse(uint8_t keycode)
{
    send_key_down(keycode);
    vTaskDelay(pdMS_TO_TICKS(10));
    send_key_up();
}

// Note: Encoder reading is now handled by input_handler module

// Input event callback - handles events from interrupt-based input handler
static void on_input_event(const input_event_t *event)
{
    switch (event->type) {
    case INPUT_EVENT_BUTTON_PRESS:
        ESP_LOGI(TAG, "BTN -> ENTER (pressed)");
        led_indicator_red();  // LED on (red) when button pressed
        send_key_down(HID_KEY_ENTER);
        break;
    case INPUT_EVENT_BUTTON_RELEASE:
        ESP_LOGI(TAG, "BTN -> ENTER (released)");
        led_indicator_off();  // LED off when button released
        send_key_up();
        break;
    case INPUT_EVENT_ENC1_CW:
        ESP_LOGI(TAG, "ENC1 CW -> UP");
        send_key_pulse(HID_KEY_UP_ARROW);
        break;
    case INPUT_EVENT_ENC1_CCW:
        ESP_LOGI(TAG, "ENC1 CCW -> DOWN");
        send_key_pulse(HID_KEY_DOWN_ARROW);
        break;
    case INPUT_EVENT_ENC2_CW:
        ESP_LOGI(TAG, "ENC2 CW -> RIGHT");
        send_key_pulse(HID_KEY_RIGHT_ARROW);
        break;
    case INPUT_EVENT_ENC2_CCW:
        ESP_LOGI(TAG, "ENC2 CCW -> LEFT");
        send_key_pulse(HID_KEY_LEFT_ARROW);
        break;
    default:
        break;
    }
}

// Legacy polling task (kept for reference, not used)
void ble_hid_demo_task_kbd(void *pvParameters)
{
    ESP_LOGI(TAG, "GPIO input task started (interrupt-based)");

    // Initialize and start the interrupt-based input handler
    input_handler_init();
    input_handler_set_callback(on_input_event);
    input_handler_start();

    // This task now just monitors the input handler
    // The actual input processing happens via ISR -> queue -> callback
    while (1) {
        vTaskDelay(pdMS_TO_TICKS(1000));  // Periodic housekeeping
    }
}
#endif
static esp_hid_raw_report_map_t ble_report_maps[] = {
#if !CONFIG_BT_NIMBLE_ENABLED || CONFIG_EXAMPLE_HID_DEVICE_ROLE == 1
    /* This block is compiled for bluedroid as well */
    {
        .data = mediaReportMap,
        .len = sizeof(mediaReportMap)
    }
#elif CONFIG_EXAMPLE_HID_DEVICE_ROLE && CONFIG_EXAMPLE_HID_DEVICE_ROLE == 2
    {
        .data = keyboardReportMap,
        .len = sizeof(keyboardReportMap)
    },
#elif CONFIG_EXAMPLE_HID_DEVICE_ROLE && CONFIG_EXAMPLE_HID_DEVICE_ROLE == 3
    {
        .data = mouseReportMap,
        .len = sizeof(mouseReportMap)
    },
#endif
};

// Device config - name and serial will be set dynamically
static esp_hid_device_config_t ble_hid_config = {
    .vendor_id          = 0x16C0,
    .product_id         = 0x05DF,
    .version            = 0x0100,
    .device_name        = NULL,  // Set dynamically from device_identity
    .manufacturer_name  = "Cosmo",
    .serial_number      = NULL,  // Set dynamically from device_identity
    .report_maps        = ble_report_maps,
    .report_maps_len    = 1
};

#define HID_CC_RPT_MUTE                 1
#define HID_CC_RPT_POWER                2
#define HID_CC_RPT_LAST                 3
#define HID_CC_RPT_ASSIGN_SEL           4
#define HID_CC_RPT_PLAY                 5
#define HID_CC_RPT_PAUSE                6
#define HID_CC_RPT_RECORD               7
#define HID_CC_RPT_FAST_FWD             8
#define HID_CC_RPT_REWIND               9
#define HID_CC_RPT_SCAN_NEXT_TRK        10
#define HID_CC_RPT_SCAN_PREV_TRK        11
#define HID_CC_RPT_STOP                 12

#define HID_CC_RPT_CHANNEL_UP           0x10
#define HID_CC_RPT_CHANNEL_DOWN         0x30
#define HID_CC_RPT_VOLUME_UP            0x40
#define HID_CC_RPT_VOLUME_DOWN          0x80

// HID Consumer Control report bitmasks
#define HID_CC_RPT_NUMERIC_BITS         0xF0
#define HID_CC_RPT_CHANNEL_BITS         0xCF
#define HID_CC_RPT_VOLUME_BITS          0x3F
#define HID_CC_RPT_BUTTON_BITS          0xF0
#define HID_CC_RPT_SELECTION_BITS       0xCF

// Macros for the HID Consumer Control 2-byte report
#define HID_CC_RPT_SET_NUMERIC(s, x)    (s)[0] &= HID_CC_RPT_NUMERIC_BITS;   (s)[0] = (x)
#define HID_CC_RPT_SET_CHANNEL(s, x)    (s)[0] &= HID_CC_RPT_CHANNEL_BITS;   (s)[0] |= ((x) & 0x03) << 4
#define HID_CC_RPT_SET_VOLUME_UP(s)     (s)[0] &= HID_CC_RPT_VOLUME_BITS;    (s)[0] |= 0x40
#define HID_CC_RPT_SET_VOLUME_DOWN(s)   (s)[0] &= HID_CC_RPT_VOLUME_BITS;    (s)[0] |= 0x80
#define HID_CC_RPT_SET_BUTTON(s, x)     (s)[1] &= HID_CC_RPT_BUTTON_BITS;    (s)[1] |= (x)
#define HID_CC_RPT_SET_SELECTION(s, x)  (s)[1] &= HID_CC_RPT_SELECTION_BITS; (s)[1] |= ((x) & 0x03) << 4

// HID Consumer Usage IDs (subset of the codes available in the USB HID Usage Tables spec)
#define HID_CONSUMER_POWER          48  // Power
#define HID_CONSUMER_RESET          49  // Reset
#define HID_CONSUMER_SLEEP          50  // Sleep
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
void app_main(void)
{
    esp_err_t ret;
#if HID_DEV_MODE == HIDD_IDLE_MODE
    ESP_LOGE(TAG, "Please turn on BT HID device or BLE!");
    return;
#endif
    ret = nvs_flash_init();
    if (ret == ESP_ERR_NVS_NO_FREE_PAGES || ret == ESP_ERR_NVS_NEW_VERSION_FOUND) {
        ESP_ERROR_CHECK(nvs_flash_erase());
        ret = nvs_flash_init();
    }
    ESP_ERROR_CHECK( ret );

    // Initialize device identity (must be after NVS init)
    ret = device_identity_init();
    ESP_ERROR_CHECK( ret );

    // Initialize LED indicator (WS2812 on D5)
    ret = led_indicator_init();
    ESP_ERROR_CHECK( ret );

    // Set dynamic device name and serial number
    ble_hid_config.device_name = device_identity_get_name();
    ble_hid_config.serial_number = device_identity_get_serial();
    ESP_LOGI(TAG, "Device: %s (SN: %s)", ble_hid_config.device_name, ble_hid_config.serial_number);

    ESP_LOGI(TAG, "setting hid gap, mode:%d", HID_DEV_MODE);
    ret = esp_hid_gap_init(HID_DEV_MODE);
    ESP_ERROR_CHECK( ret );

#if CONFIG_BT_BLE_ENABLED || CONFIG_BT_NIMBLE_ENABLED
#if CONFIG_EXAMPLE_HID_DEVICE_ROLE == 2
    ret = esp_hid_ble_gap_adv_init(ESP_HID_APPEARANCE_KEYBOARD, ble_hid_config.device_name);
#elif CONFIG_EXAMPLE_HID_DEVICE_ROLE == 3
    ret = esp_hid_ble_gap_adv_init(ESP_HID_APPEARANCE_MOUSE, ble_hid_config.device_name);
#else
    ret = esp_hid_ble_gap_adv_init(ESP_HID_APPEARANCE_GENERIC, ble_hid_config.device_name);
#endif
    ESP_ERROR_CHECK( ret );
#if CONFIG_BT_BLE_ENABLED
    if ((ret = esp_ble_gatts_register_callback(esp_hidd_gatts_event_handler)) != ESP_OK) {
        ESP_LOGE(TAG, "GATTS register callback failed: %d", ret);
        return;
    }
#endif
    ESP_LOGI(TAG, "setting ble device");
    ESP_ERROR_CHECK(
        esp_hidd_dev_init(&ble_hid_config, ESP_HID_TRANSPORT_BLE, ble_hidd_event_callback, &s_ble_hid_param.hid_dev));
#endif

#if CONFIG_BT_HID_DEVICE_ENABLED
    ESP_LOGI(TAG, "setting device name");
    esp_bt_gap_set_device_name(bt_hid_config.device_name);
    ESP_LOGI(TAG, "setting cod major, peripheral");
    esp_bt_cod_t cod = {0};
    cod.major = ESP_BT_COD_MAJOR_DEV_PERIPHERAL;
    cod.minor = ESP_BT_COD_MINOR_PERIPHERAL_POINTING;
    esp_bt_gap_set_cod(cod, ESP_BT_SET_COD_MAJOR_MINOR);
    vTaskDelay(1000 / portTICK_PERIOD_MS);
    ESP_LOGI(TAG, "setting bt device");
    ESP_ERROR_CHECK(
        esp_hidd_dev_init(&bt_hid_config, ESP_HID_TRANSPORT_BT, bt_hidd_event_callback, &s_bt_hid_param.hid_dev));
#if CONFIG_BT_SDP_COMMON_ENABLED
    ESP_ERROR_CHECK(esp_sdp_register_callback(esp_sdp_cb));
    ESP_ERROR_CHECK(esp_sdp_init());
#endif /* CONFIG_BT_SDP_COMMON_ENABLED */
#endif /* CONFIG_BT_HID_DEVICE_ENABLED */
#if CONFIG_BT_NIMBLE_ENABLED
    /* XXX Need to have template for store */
    ble_store_config_init();

    ble_hs_cfg.store_status_cb = ble_store_util_status_rr;
	/* Starting nimble task after gatts is initialized*/
    ret = esp_nimble_enable(ble_hid_device_host_task);
    if (ret) {
        ESP_LOGE(TAG, "esp_nimble_enable failed: %d", ret);
    }

    // Start GPIO input task immediately for testing (even without BLE connection)
    ble_hid_task_start_up();
#endif
}

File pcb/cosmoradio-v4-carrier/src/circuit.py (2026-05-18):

"""
CosmoradioV4Carrier — circuit-synth source

CosmoRadio V4 PCB 载板（Plan v2，2026-05-18）。
ESP32-S3 DevKitC N16R8 通过两条 1×22 单排母插入，5 路 XH2.54 连接器即插即用。
EC11 A/B 信号各加 10kΩ 上拉 + 10nF 对 GND RC 去抖（τ=100µs）。

Run with circuit-synth's bundled Python:
    /Users/dehonghao/.local/share/uv/tools/circuit-synth/bin/python3 src/circuit.py

Outputs:
    CosmoradioV4Carrier/CosmoradioV4Carrier.kicad_sch    schematic with real symbols
    CosmoradioV4Carrier/CosmoradioV4Carrier.kicad_pro    project file
    CosmoradioV4Carrier/CosmoradioV4Carrier.pdf          rendered schematic PDF
    CosmoradioV4Carrier/CosmoradioV4Carrier.csv          BOM

Then extract netlist:
    kicad-cli sch export netlist --format kicadsexpr \\
        --output CosmoradioV4Carrier/CosmoradioV4Carrier.net \\
        CosmoradioV4Carrier/CosmoradioV4Carrier.kicad_sch

Critical rules (see ~/.claude/skills/pcb/SKILL.md):
- ALWAYS set both `value` AND `footprint` on every Component (else 422 error)
- Wipe stale output before re-running: `rm -rf CosmoradioV4Carrier/`
- Don't use circuit-synth's PCB generator (paywalled). Hand-build via pcbnew API.

DevKitC 物理引脚分布权威表见 /CLAUDE.md "GPIO Pin Assignments"。
U1A/U1B 引脚顺序按 PCB 物理位置（pin 1 = 顶部 = 近 USB-C 端）。
"""

from circuit_synth import Component, Net, circuit


@circuit(name="CosmoradioV4Carrier")
def cosmoradio_v4_carrier():
    # ====================================================================
    # COMPONENTS
    # ====================================================================

    # ----- U1A: DevKitC 左列插座 (PCB 左侧, 1×22 排母) -----
    # 物理映射 (pin 1 = 顶部 = 近 USB-C 端，pin 22 = 底部 = 远端):
    #  1=GND, 2=GND (! 不是 5V — 实测 user-LEFT 顶部两个都是 GND, 5V 在 U1B pin2)
    #  3=GPIO19(USB D-), 4=GPIO20(USB D+), 5=GPIO21, 6=GPIO47,
    #  7=GPIO48, 8=GPIO45, 9=GPIO0, 10=GPIO35, 11=GPIO36, 12=GPIO37,
    #  13=GPIO38, 14=GPIO39, 15=GPIO40(ENC1 SW), 16=GPIO41(ENC1 B),
    #  17=GPIO42(ENC1 A), 18=GPIO2, 19=GPIO1(BTN), 20=GPIO44(RX0),
    #  21=GPIO43(TX0), 22=GND
    u1a = Component(
        symbol="Connector_Generic:Conn_01x22",
        ref="U1A1",
        value="DevKitC-Left-Socket",
        footprint="Connector_PinSocket_2.54mm:PinSocket_1x22_P2.54mm_Vertical",
    )

    # ----- U1B: DevKitC 右列插座 (PCB 右侧, 1×22 排母) -----
    # 物理映射:
    #  1=GND, 2=5V, 3=GPIO14, 4=GPIO13, 5=GPIO12, 6=GPIO11, 7=GPIO10, 8=GPIO9,
    #  9=GPIO46, 10=GPIO3, 11=GPIO8(ENC2 SW), 12=GPIO18(ENC2 B), 13=GPIO17(ENC2 A),
    #  14=GPIO16(NFC CS), 15=GPIO15(NFC SCK), 16=GPIO7(NFC MOSI),
    #  17=GPIO6(NFC MISO), 18=GPIO5(NFC IRQ), 19=GPIO4(NFC RST), 20=RST(CHIP_PU),
    #  21=3V3, 22=3V3
    u1b = Component(
        symbol="Connector_Generic:Conn_01x22",
        ref="U1B1",
        value="DevKitC-Right-Socket",
        footprint="Connector_PinSocket_2.54mm:PinSocket_1x22_P2.54mm_Vertical",
    )

    # ----- J1: EC11-L (用户左旋钮) 5P XH2.54, PCB 左侧中段 -----
    # 端子线序 (实物 EC11 顺序): pin 1=SW(GPIO40), 2=GND, 3=A(GPIO42), 4=GND, 5=B(GPIO41)
    j1 = Component(
        symbol="Connector_Generic:Conn_01x05",
        ref="J1",
        value="EC11-L-5P",
        footprint="Connector_JST:JST_XH_B5B-XH-A_1x05_P2.50mm_Vertical",
    )

    # ----- J2: EC11-R (用户右旋钮) 5P XH2.54, PCB 右侧中段 -----
    # 端子线序 (实物 EC11 顺序): pin 1=SW(GPIO8), 2=GND, 3=A(GPIO17), 4=GND, 5=B(GPIO18)
    j2 = Component(
        symbol="Connector_Generic:Conn_01x05",
        ref="J2",
        value="EC11-R-5P",
        footprint="Connector_JST:JST_XH_B5B-XH-A_1x05_P2.50mm_Vertical",
    )

    # ----- J3: Action Button 2P XH2.54, PCB 左侧靠前 -----
    # pin: 1=SIG(GPIO1), 2=GND
    j3 = Component(
        symbol="Connector_Generic:Conn_01x02",
        ref="J3",
        value="BTN-2P",
        footprint="Connector_JST:JST_XH_B2B-XH-A_1x02_P2.50mm_Vertical",
    )

    # ----- J4: RC522 NFC 8P XH2.54, PCB 右侧 -----
    # pin: 1=CS(16), 2=SCK(15), 3=MOSI(7), 4=MISO(6), 5=IRQ(5), 6=GND,
    #      7=RST(4), 8=3V3
    j4 = Component(
        symbol="Connector_Generic:Conn_01x08",
        ref="J4",
        value="NFC-8P",
        footprint="Connector_JST:JST_XH_B8B-XH-A_1x08_P2.50mm_Vertical",
    )

    # ----- J5: OTG dongle USB 数据 4P XH2.54, PCB 左侧靠后 -----
    # pin: 1=VBUS(5V), 2=D-(GPIO19), 3=D+(GPIO20), 4=GND
    j5 = Component(
        symbol="Connector_Generic:Conn_01x04",
        ref="J5",
        value="USB-DONGLE-4P",
        footprint="Connector_JST:JST_XH_B4B-XH-A_1x04_P2.50mm_Vertical",
    )

    # ----- R1-R4: 10kΩ 0805, EC11 A/B 上拉到 3V3 -----
    r1 = Component(
        symbol="Device:R", ref="R1", value="10k",
        footprint="Resistor_SMD:R_0805_2012Metric",
    )  # ENC1_A pull-up
    r2 = Component(
        symbol="Device:R", ref="R2", value="10k",
        footprint="Resistor_SMD:R_0805_2012Metric",
    )  # ENC1_B pull-up
    r3 = Component(
        symbol="Device:R", ref="R3", value="10k",
        footprint="Resistor_SMD:R_0805_2012Metric",
    )  # ENC2_A pull-up
    r4 = Component(
        symbol="Device:R", ref="R4", value="10k",
        footprint="Resistor_SMD:R_0805_2012Metric",
    )  # ENC2_B pull-up

    # ----- C1-C4: 10nF 0805, EC11 A/B 对 GND RC 去抖 (τ=100µs) -----
    c1 = Component(
        symbol="Device:C", ref="C1", value="10nF",
        footprint="Capacitor_SMD:C_0805_2012Metric",
    )  # ENC1_A debounce
    c2 = Component(
        symbol="Device:C", ref="C2", value="10nF",
        footprint="Capacitor_SMD:C_0805_2012Metric",
    )  # ENC1_B debounce
    c3 = Component(
        symbol="Device:C", ref="C3", value="10nF",
        footprint="Capacitor_SMD:C_0805_2012Metric",
    )  # ENC2_A debounce
    c4 = Component(
        symbol="Device:C", ref="C4", value="10nF",
        footprint="Capacitor_SMD:C_0805_2012Metric",
    )  # ENC2_B debounce

    # ====================================================================
    # NETS
    # ====================================================================
    # Power
    p5v = Net("5V")
    p3v3 = Net("3V3")
    gnd = Net("GND")

    # EC11-L 信号 (用户左旋钮)
    enc1_a = Net("ENC1_A")    # GPIO42
    enc1_b = Net("ENC1_B")    # GPIO41
    enc1_sw = Net("ENC1_SW")  # GPIO40

    # EC11-R 信号 (用户右旋钮)
    enc2_a = Net("ENC2_A")    # GPIO17
    enc2_b = Net("ENC2_B")    # GPIO18
    enc2_sw = Net("ENC2_SW")  # GPIO8

    # Action Button
    btn = Net("BTN")          # GPIO1

    # NFC SPI + control
    nfc_cs = Net("NFC_CS")      # GPIO16
    nfc_sck = Net("NFC_SCK")    # GPIO15
    nfc_mosi = Net("NFC_MOSI")  # GPIO7
    nfc_miso = Net("NFC_MISO")  # GPIO6
    nfc_irq = Net("NFC_IRQ")    # GPIO5
    nfc_rst = Net("NFC_RST")    # GPIO4

    # USB OTG (走 J5 到 dongle)
    usb_dm = Net("USB_DM")    # GPIO19
    usb_dp = Net("USB_DP")    # GPIO20
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

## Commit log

2025-12-30 feat: initial project setup
    - Add project documentation (README, hardware architecture)
    - Add E5 Ultra device reference and design draft
    - Add Adafruit HUZZAH32 and ESP-IDF BLE HID references
    - Add ESP32 firmware based on esp_hid_device example
    - Configure NimBLE BLE-only stack for keyboard HID
    - Add VS Code multi-root workspace configuration
2025-12-30 docs: define GPIO pin assignments for input devices
    Finalize hardware wiring design:
    - Button: GPIO 27
    - Encoder 1 (Up/Down): GPIO 33 (CLK) / 15 (DT)
    - Encoder 2 (Left/Right): GPIO 32 (CLK) / 14 (DT)
    All pins are physically adjacent on right edge of HUZZAH32 board,
    use internal pull-ups, no external resistors needed.
2025-12-30 feat(firmware): implement GPIO input for rotary encoders and button
    Replace console input demo with real hardware input:
    - Add GPIO driver for button (GPIO 27) and two EC11 rotary encoders
    (GPIO 33/15 for encoder 1, GPIO 32/14 for encoder 2)
    - Implement Gray code state machine for encoder direction detection
    - Map inputs to HID keys: encoders to arrow keys, button to Enter
    - Use 10ms polling interval with internal pull-up resistors
    All inputs use active-low logic (connect to GND when triggered).
    [esp_hid_device_main.c]
2025-12-30 docs: update documentation with firmware development notes
    - Update README with project status and firmware build instructions
    - Add ESP-IDF development guide to HUZZAH32 reference doc
    - Environment setup, common commands
    - GPIO driver usage in ESP-IDF v5.x
    - Rotary encoder Gray code principle
    - HID key codes reference
    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
2025-12-30 feat(test): add retro-futuristic HID input test page
    Add a single-file HTML test tool for verifying ESP32 BLE HID input:
    - Three-circle layout matching physical mask design (1280x720)
    - Frequency dial with smooth vertical scroll (↑↓ keys, 88.0-108.0 MHz)
    - Mode selector with horizontal scroll (←→ keys, FM/AM/SW/LW/MW)
    - Center confirm button (Enter key)
    - Retro radio aesthetic with amber/cyan glow effects
    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
2025-12-31 fix(test): optimize HID test page for E5 Ultra display
    - Add viewport scaling with JS to fit device screen (765x430 CSS px)
    - Add 25px horizontal offset for physical mask alignment
    - Increase font sizes for better readability:
    - Main circle: station logo 24px, hint 20px, counter 22px
    - Side circles: labels 12px, freq items 18-24px, mode items 14-20px
    - Wrap content in viewport-container for proper scaling
2025-12-31 fix(firmware): trigger encoder event once per detent
    Change encoder decoding to only trigger at the 11->10 (CW) or 11->01
    (CCW) state transition, which corresponds to the physical "click"
    position of EC11 rotary encoders.
    Previously, the full Gray code state machine triggered on every state
    change, causing 2 events per detent.
    [esp_hid_device_main.c]
2025-12-31 chore: update workspace and configuration files
    - Added multi-root workspace name to VS Code settings for better organization.
    - Updated README to include additional information.
    - Changed the IDF port in firmware settings to a specific USB serial device for consistency.
2026-01-02 feat(firmware): enable Just Works BLE pairing without PIN
    Change BLE security configuration to use Just Works pairing mode:
    - Set IO capability to NO_IO (no input/output)
    - Disable MITM protection requirement
    This allows automatic pairing without PIN entry, which is necessary
    when the device screen is covered by the physical mask.
    Bonding is still enabled, so paired devices will auto-reconnect.
2026-01-02 fix(test): adjust side circles for new physical mask
    - Scale side circles to 1.5x (116px → 174px)
    - Adjust positions to maintain center alignment
    - Update viewport offset (25 → 21) for mask alignment
2026-01-15 feat(firmware): migrate from HUZZAH32 to XIAO ESP32S3
    Hardware migration:
    - Update GPIO mappings: D0(1) button, D1-D4(2-5) encoders
    - Switch from ESP32 to ESP32-S3 target
    - Update flash size from 4MB to 8MB
    - Add sdkconfig.defaults.esp32s3 for NimBLE + Keyboard config
    - Change Kconfig default HID role to Keyboard (mode:2)
    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
2026-01-15 chore(firmware): rename BLE device to cosmo-radio-input
2026-01-26 feat(firmware): improve BLE stability and add force restart
    - Disable tickless idle to prevent BLE disconnection issues
    - Optimize BLE connection parameters (50-100ms interval, latency 5)
    - Add 15-second long press force restart for fault recovery
    - Refactor to interrupt-based input handler (ISR + queue)
    - Add device identity module for unique device naming
    - Enable indefinite BLE advertising with auto-reconnect
    [esp_hid_device_main.c, input_handler.c]
2026-01-28 feat(firmware): add WS2812 LED indicator on button press
    Add LED indicator module to provide visual feedback when the button is
    pressed. The WS2812 LED connected to D5 (GPIO6) lights up red on button
    press and turns off on release.
2026-01-29 feat(firmware): enhance device identity management and BLE connection stability
    - Introduced device number configuration (1-99) for unique BLE naming (e.g., "cosmo-01").
    - Updated device identity initialization to load and persist device number from NVS.
    - Added functionality to reset device name based on device number or MAC address.
    - Implemented keepalive task for monitoring BLE connection stability and handling disconnections.
    - Enhanced BLE advertising with directed advertising for faster reconnections to bonded peers.
2026-02-04 feat(tusb_hid): add USB HID implementation as alternative to BLE
    - Add tusb_hid/ project using TinyUSB for USB HID keyboard
    - Reuse input_handler and led_indicator modules from BLE firmware
    - Map button to Enter, encoders to arrow keys
    - Support WS2812 LED status indication
    - Update docs: support BLE/USB options, generic Android tablet
2026-04-01 docs: fix stale filename reference in CLAUDE.md
    nfc-module.md → nfc.md in naming convention example.
2026-04-30 chore: pcb — scaffold board workspace
2026-04-30 docs: pcb — record USB charge strategy
2026-04-30 docs: pcb — fix OTG validation power path
2026-05-06 feat(firmware): V4 GPIO migration + NFC RC522 + #<payload> HID protocol
    End-to-end technical validation complete on perfboard prototype:
    electrical, firmware, and NFC protocol all verified. Remaining V4
    work is PCB layout and mechanical design.
    Firmware:
    - Migrate input_handler from V3 SuperMini (GPIO 1-6) to V4 DevKitC
    N16R8 (button=1, ENC1=17/18/8, ENC2=42/41/40); add EC11 push-switch
    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
2026-05-07 feat(firmware): V4 thorough optimization — N16R8 sdkconfig + multi-key HID
    Two A-tier debts cleared end-to-end and validated on hardware:
    sdkconfig.defaults: 4MB SuperMini config → 16MB QIO flash + 8MB Octal
    PSRAM @ 80MHz. Required adding esp_psram to main/CMakeLists.txt
    PRIV_REQUIRES because the project uses MINIMAL_BUILD ON; otherwise
    CONFIG_SPIRAM is silently treated as an unknown symbol and dropped
    from sdkconfig at reconfigure time.
    HID layer: replace clear-all send_key_up() with s_pressed_keys[6] +
    s_modifier + s_hid_mutex. Two FreeRTOS tasks (input_handler +
    RC522 event task) now share the HID report path safely. "Hold F1 +
    rotate ENC1" produces a real F1+Up combo, and NFC strin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
    [tusb_hid_example_main.c]
2026-05-15 refactor(firmware): NFC HID — drop '#' prefix on NDEF payload
    NDEF Text payload is now typed verbatim followed by Enter, instead of
    "#<payload>\n". The leading '#' was originally meant to let the tablet
    distinguish NFC content from ordinary HID key input by first character,
    but the tablet side disambiguates by page state / input length now, so
    the prefix is dead weight. UID fallback path still uses "NFC:<UID>\n".
    Verified end-to-end on hardware: UID 04A38B6A220289 → '004\n',
    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
2026-05-15 fix(firmware): input_handler — swap L/R encoder GPIO for reversed harness
    Breadboard prototype has the EC11 harnesses physically reversed vs the
    CLAUDE.md GPIO table (PCB design intent). Firmware compensates here so
    ENC1 still means "left knob" and ENC2 still means "right knob" from the
    user's perspective. CLAUDE.md table stays as-is — it documents the PCB
    target. Once the PCB is built and harnessed per spec, revert this swap.
    In-source NOTE block records the rationale at the call site.
    [input_handler.c]
2026-05-18 feat(pcb): V4 carrier board 落版完成 — JLC-ready Gerber + 全文档同步
    PCB Plan v2 实施 (2026-05-18):
    - 100×100mm 双面板, 2× 1×22 单排母 (DevKitC), 5× B-type 立式直插 JST,
    4× 10kΩ + 4× 10nF EC11 RC 去抖网络
    - DRC 0/0/0 (0 unconnected, 0 copper, 0 silk warning)
    - Gerber zip + BOM + 3D 渲染图全部产出
    修正的 3 个关键 bug (vs 早期 plan):
    1. U1A pin 2 实测是 GND (不是 5V) — 避免插板瞬间 5V→GND 短路
    2. EC11 端子线序为 SW-GND-A-GND-B (按实物 5P 排序, 不是 ABCDE)
    3. 连接器换回 B-type Vertical (从上往下垂直插入), latch 朝板边外侧
    工程脚手架:
    - pcb/cosmoradio-v4-carrier/src/circuit.py — circuit-syn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
    [CosmoradioV4Carrier.csv, CosmoradioV4Carrier.kicad_pcb, CosmoradioV4Carrier.kicad_sch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]
